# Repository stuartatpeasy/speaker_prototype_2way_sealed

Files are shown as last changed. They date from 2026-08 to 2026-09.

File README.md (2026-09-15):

# DIY Near-Wall Two-Way Loudspeaker

This is the compact project dashboard and documentation router for the sealed
passive two-way prototype. Read it first, then follow only the route relevant to
the task. Detailed procedures, evidence, and history are deliberately kept out
of this file.

## 1. Current Project State

**Lifecycle:** ACTIVE PROTOTYPE DEVELOPMENT

**Current phase:** measured Seed A is the accepted reversible external
prototype. Its acoustic summation, as-built load, bounded level/distortion, and
exposed-component surface-thermal gates pass. Driver procurement and final
crossover/placement decisions remain provisional. The owning
[driver](doc/DRIVER_ANALYSIS.md), [crossover](doc/CROSSOVER_DESIGN.md), and
[REW](doc/rew/README.md) records provide the conditions and evidence.

**Next action:** inventory/procure and build speaker two to the same design,
then compare the decisive installed, acoustic, load, level, and thermal results
under matched conditions. On speaker two, capture a valid immediate hot
`0-degree` response and check whether the narrow `2.18 kHz` high-level feature
repeats. Speaker one's wrong-angle hot trace remains excluded; retest it only if
speaker two reveals an anomaly.

**Last reviewed:** 2026-09-15

| Subsystem | Current consequence | Detailed authority |
| --- | --- | --- |
| Cabinet | One representative sealed prototype is complete; speaker two should match it. | [Cabinet design](doc/CABINET_DESIGN.md) |
| Drivers | The original cooled installed ZMAs remain model baselines; a cooled post-conditioning woofer check is lower priority. | [Driver analysis](doc/DRIVER_ANALYSIS.md) |
| Crossover | Seed A passes the bounded hardware and acoustic gates; keep it external through pair matching. | [Crossover design](doc/CROSSOVER_DESIGN.md) |
| Measurement | StarTech load and UMC22 raw-driver routes pass; desktop UMC202HD sweeps remain suspended. | [REW dispatcher](doc/rew/README.md) |
| Room | Near-wall placement candidates remain measurement trials. | [Room summary](doc/ROOM_DETAILS.md) |

## 2. Project Goal And Locked Architecture

Design and build a pair of accurate, measurement-led passive loudspeakers with
neutral tonal balance, smooth on-axis and off-axis behaviour, low distortion,
and an amplifier-friendly measured load. Installed measurements take precedence
over nominal impedance, textbook crossover values, or unsupported audiophile
claims.

The first version is locked to:

- passive two-way operation;
- SB Acoustics SB17NRX2C35-8 woofer/midwoofer;
- SB Acoustics SB26STWGC-4 waveguide tweeter;
- sealed, near-wall enclosure;
- an external development crossover through a four-pole speakON connection;
- crossover design from phase-bearing measurements of the installed drivers.

Three-way, open-baffle, transmission-line, horn, and reflex alternatives are
outside this version. DSP may be used experimentally before the passive
crossover is finalised.

## 3. Task-Oriented Reading Routes

Read `AGENTS.md` as the standing collaboration policy. Then use the smallest
route below. Files labelled history or qualification are not routine context.

| Task | Read | Add only when needed |
| --- | --- | --- |
| Driver or enclosure alignment | [Driver analysis](doc/DRIVER_ANALYSIS.md) | [Run-in procedure](doc/DRIVER_RUNIN.md) for conditioning; [cabinet design](doc/CABINET_DESIGN.md) for mechanical consequences |
| Cabinet fabrication | [Cabinet design](doc/CABINET_DESIGN.md) | [3D-model hub](doc/3d_models/README.md) for model selection; [regeneration and retention](doc/3d_models/REGENERATION_AND_RETENTION.md) only for rebuilding a model or printer job |
| Crossover modelling | [Driver analysis](doc/DRIVER_ANALYSIS.md), [crossover design](doc/CROSSOVER_DESIGN.md), [measurement workflow](doc/MEASUREMENT_WORKFLOW.md) | [Component development](doc/CROSSOVER_COMPONENT_DEVELOPMENT.md) only for component construction or thermal/mechanical questions |
| UMC22 woofer capture or repeatability investigation | [REW dispatcher](doc/rew/README.md), [UMC22 runbook](doc/rew/procedures/UMC22_INSTALLED_WOOFER_FRD.md) | [FRD method](doc/rew/FRD_MEASUREMENT_METHOD.md) when reviewing geometry, impulse/ETC, the production window, or capture comparisons; [driver analysis](doc/DRIVER_ANALYSIS.md) when assessing or promoting driver-design evidence; qualification only for audit or failure investigation |
| UMC22 protected tweeter capture | [REW dispatcher](doc/rew/README.md), [UMC22 tweeter runbook](doc/rew/procedures/UMC22_INSTALLED_TWEETER_FRD.md) | [FRD method](doc/rew/FRD_MEASUREMENT_METHOD.md) for common timing/window review; [driver analysis](doc/DRIVER_ANALYSIS.md) for the approved impedance and protection derivation |
| UMC22 horizontal off-axis driver series | [REW dispatcher](doc/rew/README.md), [horizontal off-axis runbook](doc/rew/procedures/UMC22_INSTALLED_HORIZONTAL_OFF_AXIS_FRD.md) | [FRD method](doc/rew/FRD_MEASUREMENT_METHOD.md) only when reviewing timing/window validity; completed on-axis runbooks only to audit a disputed electrical-route fact |
| Seed A as-built impedance/phase planning or operation | [StarTech Seed A impedance procedure](doc/rew/procedures/STARTECH_SEED_A_SYSTEM_IMPEDANCE.md), [crossover design](doc/CROSSOVER_DESIGN.md) | [Driver analysis](doc/DRIVER_ANALYSIS.md) for baseline comparison; Seed A commissioning history only to audit completed acoustic evidence |
| Review or deliberately repeat Seed A full-system level/thermal validation | [Seed A level/thermal qualification](doc/rew/qualification/SEED_A_FULL_SYSTEM_LEVEL_AND_THERMAL_QUALIFICATION_2026-09-10.md), [crossover design](doc/CROSSOVER_DESIGN.md) | [Completed procedure](doc/rew/procedures/UMC22_SEED_A_LEVEL_AND_THERMAL.md) only for a deliberate repeat; [fixture use](doc/rew/fixtures/REFERENCE_FIXTURE_USE.md) only after reconnection or a changed route |
| Reconnect or operate the reference fixture | [Fixture use](doc/rew/fixtures/REFERENCE_FIXTURE_USE.md) and the applicable interface procedure | [Fixture specification](doc/rew/fixtures/REFERENCE_FIXTURE_SPECIFICATION.md) if rebuilding or redesigning |
| Audit UMC22 or fixture qualification | [REW dispatcher](doc/rew/README.md), then the named record under `doc/rew/qualification/` | Chronological records under `doc/rew/history/` only for superseded attempts or provenance questions |
| Diagnose or resume UMC202HD | [Dropout diagnosis](doc/rew/UMC202HD_DESKTOP_DROPOUT_DIAGNOSIS.md) | [Suspended UMC202HD procedure](doc/rew/procedures/UMC202HD_FRD_SUSPENDED.md) when preparing to resume |
| Room placement | [Room summary](doc/ROOM_DETAILS.md), [placement and measurement](doc/room/ROOM_PLACEMENT_AND_MEASUREMENT.md) | [Geometry and screening](doc/room/ROOM_GEOMETRY_AND_SCREENING.md) for CAD, coupled-space, or modal questions |
| FRD, ZMA, impulse, or VituixCAD file inspection/comparison | [Measurement data tooling](doc/MEASUREMENT_DATA_TOOLING.md) | [Measurement workflow](doc/MEASUREMENT_WORKFLOW.md) only when interpreting evidence or changing measurement policy |
| REW API status or session snapshot | [REW API client](doc/REW_API_CLIENT.md) | Its qualification record only for maintenance or audit |
| Retained `.mdat` extraction or summary | [REW MDAT extraction](doc/rew/procedures/REW_MDAT_EXTRACTION.md) | [REW API client](doc/REW_API_CLIENT.md) for live reachability; API qualification only for maintenance or audit |
| 3D model selection | [3D-model hub](doc/3d_models/README.md), then one component README | [Regeneration and retention](doc/3d_models/REGENERATION_AND_RETENTION.md) only for rebuilding or re-slicing |
| Documentation review | [Documentation review procedure](doc/DOCUMENTATION_REVIEW.md) | [Local tooling](doc/LOCAL_TOOLING.md) for the offline link, route, and changed-file checks; use comprehensive mode only for consolidation or handover |
| Repository or generated-artifact maintenance | [AGENTS.md](AGENTS.md), [.gitignore](.gitignore), [local tooling](doc/LOCAL_TOOLING.md) | Relevant reconstruction authority only |

## 4. Documentation Map

| Area | Authority |
| --- | --- |
| Collaboration and retention policy | [AGENTS.md](AGENTS.md), [.gitignore](.gitignore) |
| Documentation review | [doc/DOCUMENTATION_REVIEW.md](doc/DOCUMENTATION_REVIEW.md) |
| Driver evidence and conditioning | [doc/DRIVER_ANALYSIS.md](doc/DRIVER_ANALYSIS.md), [doc/DRIVER_RUNIN.md](doc/DRIVER_RUNIN.md) |
| Cabinet and crossover | [doc/CABINET_DESIGN.md](doc/CABINET_DESIGN.md), [doc/CROSSOVER_DESIGN.md](doc/CROSSOVER_DESIGN.md), [doc/CROSSOVER_COMPONENT_DEVELOPMENT.md](doc/CROSSOVER_COMPONENT_DEVELOPMENT.md) |
| Measurement policy and tooling | [doc/MEASUREMENT_WORKFLOW.md](doc/MEASUREMENT_WORKFLOW.md), [doc/MEASUREMENT_DATA_TOOLING.md](doc/MEASUREMENT_DATA_TOOLING.md), [doc/REW_API_CLIENT.md](doc/REW_API_CLIENT.md) |
| REW procedures, qualification, and history | [doc/rew/README.md](doc/rew/README.md) |
| Dated driver and crossover decisions | [doc/history/README.md](doc/history/README.md) — history dispatcher; load only for provenance |
| Room geometry and placement | [doc/ROOM_DETAILS.md](doc/ROOM_DETAILS.md) |
| 3D-model documentation | [doc/3d_models/README.md](doc/3d_models/README.md) |
| Local environments and checkout paths | [doc/LOCAL_TOOLING.md](doc/LOCAL_TOOLING.md) |

All durable project Markdown except this file and `AGENTS.md` lives under
`doc/`. Subtree dispatchers index detailed component, qualification, and history
records without forcing them into normal orientation context.

## 5. Open Decisions

- final damping quantity and distribution;
- final cooled woofer impedance baseline and whether further conditioning helps;
- exact crossover frequency, topology, acoustic polarity, and component values;
- final inductor implementation, restraint, and crossover mounting position;
- amplifier headroom at the required listening level;
- final veneer and finish;
- final room placement among the documented reversible trials;
- whether DSP or a future subwoofer forms part of the finished system;
- production-driver spread and stereo-pair matching during the second-speaker
  build, including the deferred hot `0-degree` comparison.

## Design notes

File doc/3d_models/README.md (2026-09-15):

# 3D Model Collection

| State | Value |
| --- | --- |
| Lifecycle | **CURRENT COLLECTION HUB** |
| Owns | Model catalogue and selection routing |
| Does not own | Component-specific dimensions, provenance, inferred geometry, limitations, or regeneration detail |
| Source tree | [`src/3d_models/`](../../src/3d_models/) |
| Artefact tree | [`3d_models/`](../../3d_models/) |
| Regeneration, preview, printer, and retention | [Regeneration and retention](REGENERATION_AND_RETENTION.md) |
| Last reviewed | 2026-09-15 |

## 1. Collection catalogue

| Family | Preferred model and variants | Component record |
| --- | --- | --- |
| M4 × 10 Type D flanged insert | Low-poly DAE for repeated cabinet instances; detailed DAE for close views; legacy STL fallbacks retained | [Type D insert](M4x10_Type_D_Flanged_Threaded_Insert/README.md) |
| M4 × 10 Type E non-flanged insert | One DAE | [Type E insert](M4x10_Type_E_NonFlanged_Threaded_Insert/README.md) |
| M4 × 30 countersunk machine screw | One DAE | [M4 machine screw](M4x30_Countersunk_Machine_Screw_Black/README.md) |
| No. 4 × 3/4 in self-tapping screw | One DAE | [No. 4 screw](No4x3-4in_2.9x19mm_Pozi_Countersunk_Self_Tapping_Screw_Black_Passivated/README.md) |
| No. 8 × 1 in self-tapping screw | One DAE | [No. 8 screw](No8x1in_4.2x25mm_Pozi_Countersunk_Self_Tapping_Screw_Black/README.md) |
| Neutrik NL4MPXX | DAE converted from retained STEP | [NL4MPXX connector](Neutrik_NL4MPXX/README.md) |
| SB Acoustics SB17NRX2C35-8 | DAE; legacy STL fallback retained | [Woofer](SB_Acoustics_SB17NRX2C35-8/README.md) |
| SB Acoustics SB26STWGC-4 | One DAE | [Tweeter](SB_Acoustics_SB26STWGC-4/README.md) |
| Crossover-coil formers and brackets | Five retained SketchUp-exported fabrication STLs | [Crossover coils](Crossover_Coils/README.md) |

Canonical cabinet and room assemblies, fabrication STLs, and printer jobs also live under [`3d_models/`](../../3d_models/), but are not members of this scripted component catalogue.

## 2. Choose the next authority

For model selection, read only the relevant component record above. For scripted-model regeneration, SketchUp import, preview rendering, runtime/dependencies, G-code re-slicing, verification, or retention, read [Regeneration and retention](REGENERATION_AND_RETENTION.md) after the selected component record. Canonical assemblies and fabrication STL/printer jobs are not part of the scripted catalogue; use their named records and retained source files.

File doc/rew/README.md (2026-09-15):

# REW Documentation Dispatcher

Lifecycle: **CURRENT DISPATCHER**
Last reviewed: 2026-09-15

## 1. Purpose

This file routes a task to one REW authority. It owns navigation and lifecycle
labels only; it does not own measurement status, results, settings, or safety
release. Begin with the smallest route below and load evidence or history only
when the task actually requires it.

The lifecycle labels mean:

- **CURRENT PROCEDURE** — instructions that may govern the next physical or
  software action after their stated prerequisites are satisfied.
- **COMPLETED PROCEDURE / RETAINED EVIDENCE** — the route used for finished
  work; consult for audit or a deliberate repeat after material change, not as
  an automatic signal release.
- **METHOD** — interface-neutral measurement principles and data-handling
  requirements; not an equipment power-up authority.
- **QUALIFICATION EVIDENCE** — concise retained results supporting a release or
  engineering conclusion; normally read for audit, failure investigation, or
  hardware/configuration change.
- **ACTIVE DIAGNOSTIC** — the authority for an unresolved fault and its next
  useful discriminator.
- **HISTORY** — superseded and failed branches retained for provenance. Do not
  load routinely and never follow an old instruction without checking the
  current procedure.

## 2. Task Routes

| Task | Read first | Add only if needed |
| --- | --- | --- |
| UMC22 installed-woofer capture or repeatability investigation | [`procedures/UMC22_INSTALLED_WOOFER_FRD.md`](procedures/UMC22_INSTALLED_WOOFER_FRD.md) | [`FRD_MEASUREMENT_METHOD.md`](FRD_MEASUREMENT_METHOD.md) when choosing/reviewing the production window or comparing captures; [`../DRIVER_ANALYSIS.md`](../DRIVER_ANALYSIS.md) when assessing or promoting driver-design evidence |
| UMC22 protected installed-tweeter capture | [`procedures/UMC22_INSTALLED_TWEETER_FRD.md`](procedures/UMC22_INSTALLED_TWEETER_FRD.md) | [`FRD_MEASUREMENT_METHOD.md`](FRD_MEASUREMENT_METHOD.md) for common timing/window review; [`../DRIVER_ANALYSIS.md`](../DRIVER_ANALYSIS.md) for the measured load and protection derivation |
| UMC22 installed-driver horizontal off-axis series | [`procedures/UMC22_INSTALLED_HORIZONTAL_OFF_AXIS_FRD.md`](procedures/UMC22_INSTALLED_HORIZONTAL_OFF_AXIS_FRD.md) | The completed woofer/tweeter runbooks only if an existing electrical-route fact is disputed; qualification only for a failed gate or changed hardware |
| Audit the completed Seed A full-system level and thermal gate | [`qualification/SEED_A_FULL_SYSTEM_LEVEL_AND_THERMAL_QUALIFICATION_2026-09-10.md`](qualification/SEED_A_FULL_SYSTEM_LEVEL_AND_THERMAL_QUALIFICATION_2026-09-10.md) | [`../CROSSOVER_DESIGN.md`](../CROSSOVER_DESIGN.md) for the design consequence; the completed procedure only for a deliberate repeat |
| Deliberately repeat the Seed A level/thermal route or adapt it for speaker two | [`procedures/UMC22_SEED_A_LEVEL_AND_THERMAL.md`](procedures/UMC22_SEED_A_LEVEL_AND_THERMAL.md) | Fixture qualification only after a changed route or failed gate |
| Deliberately repeat Seed A impedance/phase or adapt the route for speaker two | [`procedures/STARTECH_SEED_A_SYSTEM_IMPEDANCE.md`](procedures/STARTECH_SEED_A_SYSTEM_IMPEDANCE.md) | [`../CROSSOVER_DESIGN.md`](../CROSSOVER_DESIGN.md) for the design gate; qualification only if hardware or an established gate is disputed |
| Audit the completed Seed A load or EPDR result | [`qualification/SEED_A_AS_BUILT_IMPEDANCE_AND_EPDR_2026-09-09.md`](qualification/SEED_A_AS_BUILT_IMPEDANCE_AND_EPDR_2026-09-09.md) | [`../CROSSOVER_DESIGN.md`](../CROSSOVER_DESIGN.md) for the current design consequence |
| Audit completed Seed A filtered/full-system acoustic evidence | [`history/SEED_A_EXTERNAL_CROSSOVER_COMMISSIONING_2026-09-08_TO_09.md`](history/SEED_A_EXTERNAL_CROSSOVER_COMMISSIONING_2026-09-08_TO_09.md) | [`../DRIVER_ANALYSIS.md`](../DRIVER_ANALYSIS.md) or [`../CROSSOVER_DESIGN.md`](../CROSSOVER_DESIGN.md) for the current engineering consequence |
| General installed-driver measurement design or FRD review | [`FRD_MEASUREMENT_METHOD.md`](FRD_MEASUREMENT_METHOD.md) | The applicable interface procedure |
| Plan a new measurement series or revise evidence handling | [`MEASUREMENT_PLANNING_AND_EVIDENCE.md`](MEASUREMENT_PLANNING_AND_EVIDENCE.md) | The exact current interface procedure and qualification only when a gate changes |
| Extract or compactly summarise a retained `.mdat` through REW | [`procedures/REW_MDAT_EXTRACTION.md`](procedures/REW_MDAT_EXTRACTION.md) | [`../REW_API_CLIENT.md`](../REW_API_CLIENT.md) for live status/snapshot; API validation only for maintenance or failure audit |
| Audit the UMC22 release | [`qualification/UMC22_FRD_QUALIFICATION.md`](qualification/UMC22_FRD_QUALIFICATION.md) | The dated UMC22 history only for failed or superseded branches |
| Audit approved installed-driver acoustic sources, window choice, or a capture exclusion | [`qualification/INSTALLED_DRIVER_ACOUSTIC_SOURCES_2026-09-06_TO_07.md`](qualification/INSTALLED_DRIVER_ACOUSTIC_SOURCES_2026-09-06_TO_07.md) | [`../DRIVER_ANALYSIS.md`](../DRIVER_ANALYSIS.md) for the current modelling consequence; dated history only for superseded interface attempts |
| Audit or reproduce REW API extraction validation | [`qualification/REW_API_CLIENT_VALIDATION.md`](qualification/REW_API_CLIENT_VALIDATION.md) | [`../REW_API_CLIENT.md`](../REW_API_CLIENT.md) for the current operating procedure |
| Operate or reconnect the reference fixture | [`fixtures/REFERENCE_FIXTURE_USE.md`](fixtures/REFERENCE_FIXTURE_USE.md) | Qualification only if a gate fails or hardware changed |
| Rebuild, modify, or redesign the fixture | [`fixtures/REFERENCE_FIXTURE_SPECIFICATION.md`](fixtures/REFERENCE_FIXTURE_SPECIFICATION.md) | [`qualification/REFERENCE_FIXTURE_QUALIFICATION_2026-09-01_TO_03.md`](qualification/REFERENCE_FIXTURE_QUALIFICATION_2026-09-01_TO_03.md) |
| Diagnose UMC202HD desktop dropouts | [`UMC202HD_DESKTOP_DROPOUT_DIAGNOSIS.md`](UMC202HD_DESKTOP_DROPOUT_DIAGNOSIS.md) | No other REW file unless a specific analogue result is disputed |
| Decide whether UMC202HD FRD may resume | [`procedures/UMC202HD_FRD_SUSPENDED.md`](procedures/UMC202HD_FRD_SUSPENDED.md) | Dropout authority, fixture-use file, then qualification evidence if the physical chain changed |

## 3. Evidence And History

- [`qualification/UMC22_FRD_QUALIFICATION.md`](qualification/UMC22_FRD_QUALIFICATION.md) — **QUALIFICATION EVIDENCE** for UMC22 Gates A-E and the final repeatability release.
- [`qualification/INSTALLED_DRIVER_ACOUSTIC_SOURCES_2026-09-06_TO_07.md`](qualification/INSTALLED_DRIVER_ACOUSTIC_SOURCES_2026-09-06_TO_07.md) — **QUALIFICATION EVIDENCE** for approved installed-driver on-axis and sparse-polar source selection, exclusions, timing, windows, and protection scale.
- [`qualification/REFERENCE_FIXTURE_QUALIFICATION_2026-09-01_TO_03.md`](qualification/REFERENCE_FIXTURE_QUALIFICATION_2026-09-01_TO_03.md) — **QUALIFICATION EVIDENCE** for amplifier topology, fixture construction, clamps, ground paths, cables, and AC commissioning.
- [`qualification/REW_API_CLIENT_VALIDATION.md`](qualification/REW_API_CLIENT_VALIDATION.md) — **QUALIFICATION EVIDENCE** for offline tests and live selected extraction; the Codex host-access boundary remains separately stated.
- [`qualification/STARTECH_IMPEDANCE_ROUTE_QUALIFICATION_2026-09-09.md`](qualification/STARTECH_IMPEDANCE_ROUTE_QUALIFICATION_2026-09-09.md) — **QUALIFICATION EVIDENCE** for the effective R/R/L route, refreshed open/short/reference calibration, known-resistor verification, and Seed A level release.
- [`qualification/SEED_A_AS_BUILT_IMPEDANCE_AND_EPDR_2026-09-09.md`](qualification/SEED_A_AS_BUILT_IMPEDANCE_AND_EPDR_2026-09-09.md) — **QUALIFICATION EVIDENCE** for the retained complete-system capture, measured minimum load, EPDR derivation, model comparison, and load-gate pass.
- [`qualification/SEED_A_FULL_SYSTEM_LEVEL_AND_THERMAL_QUALIFICATION_2026-09-10.md`](qualification/SEED_A_FULL_SYSTEM_LEVEL_AND_THERMAL_QUALIFICATION_2026-09-10.md) — **QUALIFICATION EVIDENCE** for the retained level series, sampled distortion, compression comparison, external-component temperatures, invalid post-thermal trace exclusion, and bounded decision.
- [`history/UMC22_FRD_QUALIFICATION_LOG_2026-09-05.md`](history/UMC22_FRD_QUALIFICATION_LOG_2026-09-05.md) — **HISTORY** containing the detailed UMC22 chronology.
- [`history/FRD_REPEATABILITY_DEVELOPMENT_2026-09-03_TO_05.md`](history/FRD_REPEATABILITY_DEVELOPMENT_2026-09-03_TO_05.md) — **HISTORY** containing the UMC202HD-to-UMC22 method-development narrative.
- [`history/SEED_A_EXTERNAL_CROSSOVER_COMMISSIONING_2026-09-08_TO_09.md`](history/SEED_A_EXTERNAL_CROSSOVER_COMMISSIONING_2026-09-08_TO_09.md) — **HISTORY / RETAINED MEASUREMENT EVIDENCE** for Seed A cold commissioning, the parked tweeter-only-load investigation, WF1/TF1/SUM1/REV1, and the first physical full-system horizontal set.

History files are deliberately excluded from normal orientation. Search or
open the relevant dated subsection only when reconstructing why a setting or
decision changed.

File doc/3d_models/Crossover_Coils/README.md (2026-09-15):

# Crossover Coil Fabrication Models

| State | Value |
| --- | --- |
| Lifecycle | **CURRENT RETAINED FABRICATION SOURCES** |
| Owns | Identity, file-level provenance, geometry checks, print reconstruction, and retention limits for the crossover-coil formers and brackets |
| Does not own | Electrical winding targets, inductance/DCR acceptance, PCB layout, installed restraint, or manufacturing release |
| Source tree | [`3d_models/Crossover coils/`](../../../3d_models/Crossover%20coils/) |
| Current use | Candidate formers and restraint brackets for the reversible external crossover and its matched second network |
| Limitations | Only binary STL exports are retained; no editable SketchUp source or parameterised generator is present, and STL dimensions do not prove fit or mechanical adequacy |
| Last reviewed | 2026-09-15 |

## 1. Retained models

Each binary header begins `SketchUp STL tmp`, which establishes the exporter
family but not the SketchUp version, units setting, authoring history, or design
intent. File-level inspection gives:

| STL | Bytes | Triangles | Axis-aligned size, mm | SHA-256 |
| --- | ---: | ---: | --- | --- |
| `Crossover coil bracket 70mm.stl` | `36,884` | `736` | `24 x 45 x 47` | `1a1c5f53c819f191d65dd57bc6a944bdf2bd17f0ede35a2619a52653eb27129a` |
| `Crossover coil bracket B.stl` | `81,284` | `1,624` | `54 x 50 x 51` | `bb128d6cfdb267210c2d28ef907b901df0f76c888de0b029383f7d10baa7defd` |
| `Crossover coil former 50mm.stl` | `87,884` | `1,756` | `50 x 50 x 33` | `1d27ed4c79d08ac5ad17f20713781e60b5f202eba2ae47380797f6348366c287` |
| `Crossover coil former 60mm.stl` | `115,484` | `2,308` | `60 x 60 x 33` | `46a93e1c0fd671c08022aa63b22a1416570dfbe013cbe9eb493ed98c347cc9a6` |
| `Crossover coil former 70mm.stl` | `104,084` | `2,080` | `70 x 70 x 33.5` | `411bb6568155a367072750986901e53c84828467ae5ccf0e84cfa93079025e8f` |

These are retained fabrication sources because no complete reconstruction path
exists. Do not replace or ignore them merely because a slicer can consume the
exports. Verify coil fit, lead exit, separation/orientation, restraint, PCB and
cabinet clearance, material, and print quality on the actual assembly.

## 2. Print reconstruction

[`3d_models/PRINT_SETTINGS.json`](../../../3d_models/PRINT_SETTINGS.json) owns
the Cura 5.13.0 / Creality CR-20 Pro settings and reference output statistics.
G-code is intentionally ignored. Re-slice the named current STL with the
manifest settings and compare bounds, time, and filament use proportionately;
functional rather than byte-identical equivalence is expected.

The 2026-09-13 file reorganisation changed two former geometries while removing
their old names. For historical print jobs, the manifest therefore records the
source path and Git revision that existed at capture. Recover that exact input
without altering the worktree with:

```text
git show <sourceRevisionAtCapture>:3d_models/<sourceStlAtCapture>
```

Redirect that output only into a temporary workspace. A similarly named current
STL is not assumed geometrically equivalent unless the manifest says the move
was exact.

## 3. Electrical authority

Former diameter and winding space are mechanical constraints, not inductance
specifications. Use [Crossover component
development](../../CROSSOVER_COMPONENT_DEVELOPMENT.md) for the measured Seed A
inductances, DCRs, winding practice, pair matching, and thermal limitations.

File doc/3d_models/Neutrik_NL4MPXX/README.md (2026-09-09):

# Neutrik NL4MPXX Connector

[Collection import, regeneration, and retention instructions](../README.md)

## 1. Model, source, and placement

The SketchUp model is [Neutrik_NL4MPXX.dae](../../../3d_models/Neutrik_NL4MPXX/Neutrik_NL4MPXX.dae). It is an OpenCascade tessellation of the retained [3d_models/nl4mpxx.stp](../../../3d_models/nl4mpxx.stp).

- Units: millimetres; Z-up.
- Origin/orientation: the STEP coordinate system is preserved without scaling, rotation, centring, or relocation.
- Dimensions: 25.9 × 30.9 × 34.3 mm.
- Bounds: X `-12.95` to `12.95` mm; Y `-15.45` to `15.45` mm; Z `-27.25` to `7.05` mm.

## 2. Provenance and conversion limits

The STEP identifies `NL4MPXX-4`, Creo Parametric, and millimetres. OpenCascade reads one valid solid with 1,108 analytic B-rep faces. Because the source contains no STEP colour/presentation records, the DAE adds one dark graphite housing material rather than inferred part colours.

Source STEP SHA-256:

```text
AA7DDF218941F2284EE6E9C9E7E2591CA32B3B0ED0E6CA1A27EAEDB660CD6748
```

The converter uses `0.35 mm` linear and `0.65 rad` angular deflection. The result contains 18,262 triangles, 17,428 face-local vertices, and no degenerate triangles. Periodic CAD seams remain coincident mesh seams; the source B-rep passes OpenCascade validity.

## 3. Generator and dependency

[generate_neutrik_nl4mpxx.py](../../../src/3d_models/Neutrik_NL4MPXX/generate_neutrik_nl4mpxx.py) reads the retained STEP path above. Conversion additionally requires:

```console
python -m pip install cadquery-ocp-novtk
```

The exact package version used for the present DAE was not recorded. Treat the
documented STEP hash, tessellation settings, bounds, solid/face count, triangle
count, and validity checks as the current semantic reconstruction test, and pin
the package version before changing or re-qualifying the converter. The shared
preview renderer reads the generated DAE directly, so OpenCascade is needed
only for STEP conversion.

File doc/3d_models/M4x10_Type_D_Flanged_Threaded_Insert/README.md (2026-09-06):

# M4 × 10 mm Type D Flanged Threaded Insert

[Collection import, regeneration, and retention instructions](../README.md)

## 1. Preferred variant and placement

Use the [low-poly DAE](../../../3d_models/M4x10_Type_D_Flanged_Threaded_Insert_LowPoly/M4x10_Type_D_Flanged_Threaded_Insert_LowPoly.dae) for repeated cabinet instances. It retains the published envelope, flange, hex drive, through bore, and visible external helix in approximately 1,900 triangles. Use the [detailed DAE](../../../3d_models/M4x10_Type_D_Flanged_Threaded_Insert/M4x10_Type_D_Flanged_Threaded_Insert.dae) only for close views requiring the modelled internal M4 thread.

- Units: millimetres.
- Origin: centre of the upper flange face.
- Orientation: flange face in the XY plane; insert extends 10 mm along negative Z.

## 2. Controlling dimensions

| Feature | Dimension |
| --- | ---: |
| Overall length | 10.0 mm |
| Flange / maximum diameter | 8.5 mm |
| Body root diameter | 5.5 mm |
| Internal machine thread | M4 × 0.7 |
| Hex drive | 4.0 mm across flats |
| Suggested pilot hole, reference only | 5.6–6.0 mm |

## 3. Provenance and limitations

Envelope dimensions come from [The Insert Company Type D table](https://www.theinsertcompany.com/type_d_threaded_insert_for_wood.php). Flange thickness, hex depth, and die-cast external tooth form are not fully specified and are representative. Confirm the actual insert and pilot-hole behaviour in the cabinet material before fabrication.

Both variants are closed manifold meshes. The low-poly model substitutes a smooth 3.24 mm M4 minor-diameter bore for the hidden internal helix. Its 24-sided flange preserves the exact 8.5 mm X/Y envelope with approximately 0.036 mm maximum chord error. Retained [detailed STL](../../../3d_models/M4x10_Type_D_Flanged_Threaded_Insert/M4x10_Type_D_Flanged_Threaded_Insert.stl) and [low-poly STL](../../../3d_models/M4x10_Type_D_Flanged_Threaded_Insert_LowPoly/M4x10_Type_D_Flanged_Threaded_Insert_LowPoly.stl) files are legacy fallbacks.

## 4. Generators

- [Detailed generator](../../../src/3d_models/M4x10_Type_D_Flanged_Threaded_Insert/generate_m4_type_d_insert.py)
- [Low-poly generator](../../../src/3d_models/M4x10_Type_D_Flanged_Threaded_Insert_LowPoly/generate_m4_type_d_insert_low_poly.py)

Use the low-poly folder name with the shared preview renderer when verifying the preferred assembly variant.

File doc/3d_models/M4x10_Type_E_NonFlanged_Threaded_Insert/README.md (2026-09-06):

# M4 × 10 mm Type E Non-Flanged Threaded Insert

[Collection import, regeneration, and retention instructions](../README.md)

## 1. Model and placement

The SketchUp model is [M4x10_Type_E_NonFlanged_Threaded_Insert.dae](../../../3d_models/M4x10_Type_E_NonFlanged_Threaded_Insert/M4x10_Type_E_NonFlanged_Threaded_Insert.dae).

- Units: millimetres; Z-up.
- Origin: centre of the upper drive face.
- Orientation: insert extends exactly 10 mm along negative Z.
- The unheaded body can be installed below the wood surface.

## 2. Controlling dimensions

| Feature | Dimension |
| --- | ---: |
| Internal thread | M4 × 0.7 |
| Overall length | 10.0 mm |
| Maximum external-thread diameter | 8.5 mm |
| External-thread root diameter | 5.5 mm |
| Hex drive | 4.0 mm across flats |
| Suggested pilot hole | 5.6–6.0 mm |

## 3. Provenance and limitations

Dimensions and the non-flanged form come from [The Insert Company Type E record](https://www.theinsertcompany.com/type_e_threaded_insert_for_wood.php). External-thread pitch and crest form, bottom runout, hex depth, drive-to-bore transition, and four-lobed upper contour details are inferred from supplier imagery. The hidden M4 female helix is represented by a smooth 3.24 mm minor-diameter bore.

The model is a closed, outward-wound manifold containing 936 vertices and 1,872 triangles. Its 24-sided maximum-diameter approximation preserves the exact 8.5 mm X/Y envelope with approximately 0.036 mm maximum chord error.

## 4. Generator

[generate_m4_type_e_insert.py](../../../src/3d_models/M4x10_Type_E_NonFlanged_Threaded_Insert/generate_m4_type_e_insert.py)

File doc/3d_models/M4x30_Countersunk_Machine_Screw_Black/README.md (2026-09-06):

# M4 × 30 mm Black Countersunk Machine Screw

[Collection import, regeneration, and retention instructions](../README.md)

## 1. Model and placement

The SketchUp model is [M4x30_Countersunk_Machine_Screw_Black.dae](../../../3d_models/M4x30_Countersunk_Machine_Screw_Black/M4x30_Countersunk_Machine_Screw_Black.dae).

- Units: millimetres; Z-up.
- Origin: centre of the flat upper head face.
- Orientation: screw extends exactly 30.0 mm along negative Z.
- Countersunk-screw length includes the head.

## 2. Controlling dimensions

| Feature | Dimension |
| --- | ---: |
| Thread | M4 × 0.7, right hand |
| Overall length | 30.0 mm |
| Head diameter | 7.5 mm |
| Head height | 2.2 mm |
| Countersink angle | 90 degrees |
| Drive | PZ2 |
| Modelled thread-root diameter | 3.14 mm |

## 3. Provenance and limitations

The product size and black finish come from [Accu](https://www.accu.co.uk/pozi-countersunk-screws/988564-SPK-M4-30-CS-BL); [Westfield Fasteners](https://www.westfieldfasteners.co.uk/Bolts-Screws-Metric/Machine-Screw-Phillips-Countersunk-M4x75-A2-Stainless.html) corroborates the DIN 965 M4 head dimensions.

The 24-sided head preserves the exact 7.5 mm X/Y envelope. The right-hand external thread is a continuous helix with a flat, lightly chamfered end; the Pozidriv recess is a cavity. Recess-wing detail and the 3.14 mm root diameter are representative where drawings are incomplete. The closed manifold has 1,562 vertices and 3,120 triangles.

## 4. Generator

[generate_m4x30_countersunk_machine_screw.py](../../../src/3d_models/M4x30_Countersunk_Machine_Screw_Black/generate_m4x30_countersunk_machine_screw.py)

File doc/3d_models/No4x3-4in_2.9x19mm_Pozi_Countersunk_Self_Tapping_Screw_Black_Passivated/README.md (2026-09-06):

# No. 4 × 3/4 in (2.9 × 19 mm) Black-Passivated Self-Tapping Screw

[Collection import, regeneration, and retention instructions](../README.md)

## 1. Model and placement

The SketchUp model is [No4x3-4in_2.9x19mm_Pozi_Countersunk_Self_Tapping_Screw_Black_Passivated.dae](../../../3d_models/No4x3-4in_2.9x19mm_Pozi_Countersunk_Self_Tapping_Screw_Black_Passivated/No4x3-4in_2.9x19mm_Pozi_Countersunk_Self_Tapping_Screw_Black_Passivated.dae).

- Units: millimetres; Z-up.
- Origin: centre of the flat upper head face.
- Orientation: screw extends exactly 19.0 mm along negative Z, including the head.
- The metric 19 mm nominal length controls the model.

## 2. Controlling dimensions

| Feature | Dimension |
| --- | ---: |
| Thread | ST2.9 × 1.1, right hand |
| Overall length | 19.0 mm |
| Head diameter | 5.5 mm |
| Head height | 1.7 mm |
| Countersink angle | 80 degrees |
| Drive | PZ1 |
| Type Z recess width | 2.8 mm |
| Modelled recess depth | 1.60 mm |
| Type C point length | 2.6 mm |
| Modelled thread-root diameter | 2.08 mm |

## 3. Provenance and limitations

[Bolt World](https://boltworld.co.uk/products/no-4-x-3-4-2-9-x-19mm-pozi-countersunk-self-tapping-screws-black-passivated-zinc-plated-din-7982/) establishes the matching finish, PZ1 drive, head dimensions, and Type C/AB point. [Accu](https://www.accu.co.uk/self-tapping-pozi-countersunk-screws/163548-SPKT-No-4-3-4-A2-BL) corroborates the 2.9 × 19 mm, 80-degree, DIN 7982 C Z form; [Westfield Fasteners](https://www.westfieldfasteners.co.uk/Standards/TappingScrew-PoziCsk.html) supplies pitch, recess, and point standards data.

The 24-sided head preserves the 5.5 mm X/Y envelope. The external thread is a continuous helix blending into a Type C/AB-style point, and the PZ1 recess is a cavity. Recess-wing form and the modelled thread root remain representative. The closed manifold contains 890 vertices and 1,776 triangles.

## 4. Generator

[generate_no4x3_4in_pozi_countersunk_self_tapping_screw.py](../../../src/3d_models/No4x3-4in_2.9x19mm_Pozi_Countersunk_Self_Tapping_Screw_Black_Passivated/generate_no4x3_4in_pozi_countersunk_self_tapping_screw.py)

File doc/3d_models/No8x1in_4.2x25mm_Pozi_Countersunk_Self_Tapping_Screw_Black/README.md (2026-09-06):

# No. 8 × 1 in (4.2 × 25 mm) Black Self-Tapping Screw

[Collection import, regeneration, and retention instructions](../README.md)

## 1. Model and placement

The SketchUp model is [No8x1in_4.2x25mm_Pozi_Countersunk_Self_Tapping_Screw_Black.dae](../../../3d_models/No8x1in_4.2x25mm_Pozi_Countersunk_Self_Tapping_Screw_Black/No8x1in_4.2x25mm_Pozi_Countersunk_Self_Tapping_Screw_Black.dae).

- Units: millimetres; Z-up.
- Origin: centre of the flat upper head face.
- Orientation: screw extends exactly 25.0 mm along negative Z, including the head.
- The metric 25 mm nominal length controls the model.

## 2. Controlling dimensions

| Feature | Dimension |
| --- | ---: |
| Thread | ST4.2 × 1.4, right hand |
| Overall length | 25.0 mm |
| Head diameter | 8.1 mm |
| Head height | 2.5 mm |
| Countersink angle | 80 degrees |
| Drive | PZ2 |
| Point length | 3.7 mm |
| Modelled thread-root diameter | 3.10 mm |

## 3. Provenance and limitations

[Bolt World](https://boltworld.co.uk/products/no-8-x-1-4-2-x-25mm-pozi-countersunk-self-tapping-screws-black-passivated-zinc-plated-din-7982/) establishes the matching size, PZ2 drive, head dimensions, and DIN 7982 designation. [Accu](https://www.accu.co.uk/self-tapping-pozi-countersunk-screws/163584-SPKT-No-8-1-A2-BL) corroborates the product; [Westfield Fasteners](https://www.westfieldfasteners.co.uk/Standards/TappingScrew-PoziCsk.html) supplies pitch and Type C point data.

The 24-sided head preserves the exact 8.1 mm X/Y envelope. The external thread is a continuous helix blending into a Type C/AB-style point, and the Pozidriv recess is a cavity. Recess-wing form and the 3.10 mm thread root are representative where drawings are incomplete. The closed manifold contains 890 vertices and 1,776 triangles.

## 4. Generator

[generate_no8x1in_pozi_countersunk_self_tapping_screw.py](../../../src/3d_models/No8x1in_4.2x25mm_Pozi_Countersunk_Self_Tapping_Screw_Black/generate_no8x1in_pozi_countersunk_self_tapping_screw.py)

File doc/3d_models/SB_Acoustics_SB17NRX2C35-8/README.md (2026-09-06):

# SB Acoustics SB17NRX2C35-8 SketchUp Model

[Collection import, regeneration, and retention instructions](../README.md)

## 1. Model and placement

The primary model is [SB_Acoustics_SB17NRX2C35-8.dae](../../../3d_models/SB_Acoustics_SB17NRX2C35-8/SB_Acoustics_SB17NRX2C35-8.dae). The [STL](../../../3d_models/SB_Acoustics_SB17NRX2C35-8/SB_Acoustics_SB17NRX2C35-8.stl) is an uncoloured legacy fallback, not a watertight printing solid.

- Units: millimetres.
- Origin: acoustic axis on the rear mounting face of the flange.
- Orientation: cone/front along positive Z; motor along negative Z.
- Rear limit with the mounting plane at Z = 0: exactly `-75 mm`.

## 2. Manufacturer-published dimensions

| Feature | Dimension |
| --- | ---: |
| Frame outside diameter | 171.0 mm |
| Mounting-hole pitch circle | 159.0 mm |
| Mounting recesses / through holes | 4 × 8.5 mm / 4 × 4.3 mm |
| Rear basket envelope | 144.9 mm diameter |
| Magnet outside diameter | 100.0 mm |
| Front flange thickness | 6.5 mm |
| Mounting / overall depth | 75.0 mm / 85.9 mm |
| Front projection | 10.9 mm |
| Voice-coil diameter / winding height | 35.5 mm / 16.0 mm |

Sources: [manufacturer product page](https://sbacoustics.com/product/6in-sb17nrx2c35-8-norex/) and [datasheet](https://sbacoustics.com/wp-content/uploads/2020/02/6in-SB17NRX2C35-8.pdf).

## 3. Inferred geometry and limitations

Basket/spokes, cone and surround profiles, spider, motor plates, pole vent, terminals, tinsel leads, and labels are visually representative estimates from manufacturer and public product imagery. They do not override published dimensions.

Stepped mounting holes and pitch circle are accurate coloured reference surfaces but are not boolean-cut through the flange. The visual/layout assembly contains overlapping closed parts. Its 64-sided 171 mm circumference has approximately 0.103 mm maximum chord error; less visible parts use lower radial resolution. The generated model contains 8,068 triangles.

## 4. Generator

[generate_sb17nrx2c35_8.py](../../../src/3d_models/SB_Acoustics_SB17NRX2C35-8/generate_sb17nrx2c35_8.py) produces the correctly named `.dae` above; it does not recreate the legacy STL.

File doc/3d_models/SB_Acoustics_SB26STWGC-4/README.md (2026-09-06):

# SB Acoustics SB26STWGC-4 SketchUp Model

[Collection import, regeneration, and retention instructions](../README.md)

## 1. Model and placement

The model is [SB_Acoustics_SB26STWGC-4.dae](../../../3d_models/SB_Acoustics_SB26STWGC-4/SB_Acoustics_SB26STWGC-4.dae).

- Units: millimetres.
- Origin: acoustic axis on the rear mounting face of the waveguide.
- Orientation: waveguide/front along positive Z; motor and chamber along negative Z.
- Rear limit with the mounting plane at Z = 0: exactly `-42.1 mm`.

## 2. Manufacturer-published dimensions

| Feature | Dimension |
| --- | ---: |
| Waveguide outside diameter | 103.8 mm |
| Mounting-hole pitch circle | 92.0 mm |
| Mounting recesses / through holes | 4 × 8.0 mm / 4 × 4.2 mm |
| Rear/terminal envelope | 82.8 mm diameter |
| Motor diameter | 70.0 mm |
| Faceplate thickness | 6.0 mm |
| Mounting / overall depth | 42.1 mm / 48.1 mm |
| Voice-coil diameter / winding height | 25.4 mm / 1.3 mm |

Sources: [manufacturer product page](https://sbacoustics.com/product/sb26stwgc-4-fabric/), [datasheet](https://sbacoustics.com/wp-content/uploads/2020/05/SB26STWGC-4.pdf), and [public multi-angle imagery](https://www.soundimports.eu/en/sb-acoustics-sb26stwgc-4.html).

## 3. Inferred geometry and limitations

Waveguide and dome/surround profiles, adapter boss, motor plates, rear chamber, pole vent, terminals, and labels are visually representative estimates. A user-supplied production-unit sketch established a flat rear annulus blending into an approximately 64 mm central boss with a 3.0 mm concave root fillet; the 70 mm motor overhangs the boss and opposed terminals define the 82.8 mm envelope. These inferences do not override published dimensions.

Mounting recesses and holes are accurate coloured reference surfaces but are not boolean-cut. The visual/layout assembly is not a watertight printing solid. The 64-sided waveguide circumference has approximately 0.062 mm maximum chord error; the four-subdivision root fillet has approximately 0.058 mm maximum profile chord error. The DAE contains 5,714 triangles and the generator reports no degenerate triangles.

## 4. Generator

[generate_sb26stwgc_4.py](../../../src/3d_models/SB_Acoustics_SB26STWGC-4/generate_sb26stwgc_4.py)

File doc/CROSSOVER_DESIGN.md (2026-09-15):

# Crossover Design

> - **Lifecycle:** ACTIVE DESIGN AUTHORITY
> - **Owns:** current acoustic direction, driver polarity/topology, NL4 allocation, evidence dependencies, validation gates, and open design decisions
> - **Does not own:** detailed component construction, installed-driver evidence, measurement procedures, or superseded design development
> - **Read when:** modelling, assessing the present crossover, or planning an authorised controlled refinement
> - **Current decision:** retain same-polarity third-order Seed A as the reversible external prototype; measured acoustic, load, bounded level/distortion, and external-component surface-thermal gates pass
> - **Next gate:** build and test speaker two under matched conditions, including a correct immediate hot `0-degree` comparison and a check that the narrow approximately `1.28 dB` high-level shape change near `2.18 kHz` repeats
> - **Limitations:** one speaker only; approximate rather than steady sweep-voltage readings; generic rather than absolute-SPL microphone calibration; the attempted post-thermal trace is excluded because it was captured at `60 degrees`; positive-side sparse-horizontal evidence only; the parked undamped tweeter-only mechanism and possible ultrasonic behaviour remain unproved
> - **As of:** 2026-09-15

This is the current passive-crossover authority. Read the [design-development
history](history/CROSSOVER_DESIGN_DEVELOPMENT_2026-09-07_TO_08.md) only to
audit the exploratory Seed A/Seed B work or the VituixCAD correction history.
Current driver sources are in [DRIVER_ANALYSIS.md](DRIVER_ANALYSIS.md), and
component construction is in
[CROSSOVER_COMPONENT_DEVELOPMENT.md](CROSSOVER_COMPONENT_DEVELOPMENT.md).

## 1. Prototype interface and external crossover

The prototype brings the woofer and tweeter out separately through a **Neutrik
speakON NL4**:

- 1+ / 1-: woofer positive / negative;
- 2+ / 2-: tweeter positive / negative.

Keep the crossover external on a board with secure terminals, accessible
inductor taps, and enough room for safe substitutions. Do not switch taps with
the amplifier energised. Leave unused winding sections open-circuit, insulated,
and restrained so they cannot become a shorted turn.

## 2. Current crossover direction

Design from installed phase-bearing driver responses and impedances, not nominal
impedances or textbook equations. The initial approximately `2.2-2.4 kHz`,
LR4-like direction has been superseded by the measured Seed A prototype, which
crosses broadly near `1.83 kHz` and passes its physical summation gates.

Seed A uses normal (same) acoustic polarity and the measured third-order
electrical network in Section 2.2. Its shallow woofer upper transition and
moderate crossover-region beamwidth flare remain possible refinement targets.
The bounded alternative search found extra woofer suppression traded away
response span, phase/null margin, or load, while fourth-order and targeted-notch
variants were negligible or locally overfit. Do not promote Seed B unless
matched speaker-two evidence repeats a broad, design-relevant weakness.

Retain these design rules for later controlled work:

- electrical and acoustic order can differ because natural driver responses
  contribute to the final slopes;
- use partial rather than full baffle-step compensation;
- keep tweeter attenuation and check the complete measured load; and
- add impedance equalisation, breakup suppression, or sixth-order slopes only
  for a measured whole-system benefit.

### 2.1 Verified measured baseline

[`vituixcad/Prototype loudspeaker measured baseline verified 2026-09-07.vxp`](../vituixcad/Prototype%20loudspeaker%20measured%20baseline%20verified%202026-09-07.vxp)
is `10,825` bytes with SHA-256
`a456b8c2773cf0412394c75811aa6fdb41c2047a15f5f193f130904a7fb85645`.
It contains correct TW1/C2 FRDs at `0 degrees`, current installed ZMAs, TW1
scale `0.00 dB`, C2 scale `+11.14 dB`, zero response delays, native
unsmoothed phase, normal polarity, and direct unfiltered branches. It is the
raw software baseline, not a listening network.

### 2.2 Practical measured-component model

**DERIVED PRACTICAL MODEL / SIGNAL-FREE GATES PASSED:**
[`vituixcad/Prototype loudspeaker crossover Seed A practical measured 2026-09-08.vxp`](../vituixcad/Prototype%20loudspeaker%20crossover%20Seed%20A%20practical%20measured%202026-09-08.vxp)
retains the verified sparse-polar source assignments, topology, normal polarity,
and C2 scale multiplier `3.605786`, while using the completed measurements:

| Part | Practical value |
|---|---:|
| L(W1) | `0.724 mH`, `0.292 ohm` DCR, `1.8 mm` wire |
| C(W1) | `17.96 uF`, `0.04 ohm` ESR |
| L(W2) | `0.111 mH`, `0.172 ohm` DCR, `1.8 mm` wire |
| C(T1) | `12.22 uF`, `0.04 ohm` ESR |
| L(T1) | `0.219 mH`, `0.193 ohm` DCR, `1.8 mm` wire |
| C(T2) | `22.59 uF`, `0.04 ohm` ESR |
| R(Tser) | `1.401 ohm`; aggregate bank power field `20 W` |
| R(Tpar) | `39.032 ohm`; aggregate bank power field `15 W` |

The current practical file is `26,354` bytes with SHA-256
`16676944a98b625bb59effa4757f4224e0da763b36293679ace8dc0c67861a04`.
It parses with two drivers, eight measured components, four horizontal responses
per driver, installed ZMA paths, and unchanged tweeter scale; no source is
missing. Complex replay gives `2.116 kHz` branch equality, `13.2 degrees`
relative phase, `18.6 dB` normal-to-reverse difference, and `3.805 ohm`
minimum input impedance near `2.792 kHz` at `-9.4 degrees`. These pass the
bounded `2.05-2.25 kHz`, `20 degree`, `15 dB`, and `3.5 ohm` gates.

### 2.3 Measured acoustic consequence

**MEASURED ACOUSTIC VALIDATION - PROPORTIONATE PASS:** the retained authority is
[`rew/SB17NRX2C35-8_UMC22_full_dual_repeatability.mdat`](../rew/SB17NRX2C35-8_UMC22_full_dual_repeatability.mdat).
Capture detail and diagnostics are in the [Seed A commissioning
history](rew/history/SEED_A_EXTERNAL_CROSSOVER_COMMISSIONING_2026-09-08_TO_09.md).

- WF1 and TF1 place broad measured branch equality near `1.83 kHz`, about
  `13-14%` below the practical model, with essentially coincident phase.
- SUM1 correlates `0.99566` with voltage-corrected WF1+TF1; REV1 correlates
  `0.99463` with WF1-TF1. The physical polarity gate passes: the
  normal-to-reverse difference peaks at `25.31 dB` near `1.636 kHz` and is
  `15.82 dB` near `1.83 kHz`.
- The approximately `5.3 dB` axial dip near `11 kHz` predates Seed A and
  partly fills/moves off axis; it does not justify EQ.
- The `0/+20/+40/+60 degree` full-system set has no broad crossover hole. A
  moderate roughly `2.5-3.1 dB` beamwidth change through `1.5-2.5 kHz`
  remains a possible controlled-refinement target.

The intermittent distorted `1 kHz` tone occurred only with the undamped
tweeter-only load. It is closed/parked after clean resistor-dummy, damped
real-tweeter, and complete-system tests; an amplifier/load interaction remains
an inference, not a diagnosis.

### 2.4 As-built complete-system load

**VERIFIED MEASUREMENT / DERIVED - LOAD GATE PASSED:**
[`rew/SPK_impedance_WT_1_20260909.mdat`](../rew/SPK_impedance_WT_1_20260909.mdat)
and
[`rew/SPK_impedance_both_drivers_run1_2026-09-09.zma`](../rew/SPK_impedance_both_drivers_run1_2026-09-09.zma)
are owned by the [load record](rew/qualification/SEED_A_AS_BUILT_IMPEDANCE_AND_EPDR_2026-09-09.md).

Across `20 Hz-20 kHz`, minimum magnitude is `4.366 ohm` near `9.617 kHz`,
minimum real part is `4.284 ohm` near `2.156 kHz`, and minimum idealised
class-B EPDR is `2.563 ohm` near `1.942 kHz`, where actual impedance is
`4.905 ohm` at `-25.113 degrees`. The measured load clears the `3.5 ohm`
prototype gate by `0.866 ohm`; retain Seed A unchanged.

### 2.5 Full-system level, distortion, compression, and thermal result

**VERIFIED MEASUREMENT / USER-REPORTED CONDITIONS / DERIVED - BOUNDED PASS
WITH HOT-ACOUSTIC CHECK DEFERRED:** the [level/thermal qualification](rew/qualification/SEED_A_FULL_SYSTEM_LEVEL_AND_THERMAL_QUALIFICATION_2026-09-10.md)
and
[`rew/SPK_Seed_A_full_system_level_thermal_20260910.mdat`](../rew/SPK_Seed_A_full_system_level_thermal_20260910.mdat)
cover `0.5/1/2/4 V RMS` and a 15-minute nominal `2 V RMS` CTA-2034 exposure.

Both UMC22 inputs retained at least `27.9 dB` headroom; no warning, clipping,
dropout, audible distortion, protection event, or anomaly was reported. Sampled
THD and compression pass. A narrow `4 V` versus `2 V` difference reaches
`-1.28 dB` near `2.18 kHz`; it is a speaker-two confirmation item. R(Tser)
rose from `20.4` to `20.8 degrees C` and L(W1) from `20.4` to
`20.6 degrees C`, with neither rising in the final five minutes. The attempted
post-thermal sweep is excluded because it was at `60 degrees`, not `0 degrees`.

## 3. Evidence and model dependencies

Use only approved installed ZMA and phase-bearing FRD sources in
[DRIVER_ANALYSIS.md](DRIVER_ANALYSIS.md). The useful present crossover-region
loads near `2.30 kHz` are approximately `7.98 ohm` at `+10.8 degrees` for
the woofer and `3.48 ohm` at `-5.0 degrees` for the tweeter.

The approved C6 woofer source is
[`rew/frd/SB17NRX2C35-8/000deg_1m_UMC22_2026-09-06.frd`](../rew/frd/SB17NRX2C35-8/000deg_1m_UMC22_2026-09-06.frd).
The common-position TW1 source is
[`rew/frd/SB17NRX2C35-8/000deg_tweeter-axis_1m_UMC22_2026-09-06.frd`](../rew/frd/SB17NRX2C35-8/000deg_tweeter-axis_1m_UMC22_2026-09-06.frd).
With the `10.13 uF`, `0.08 ohm` protection capacitor and installed tweeter
ZMA, C2 requires `+11.14 dB`; leave TW1 at `0.00 dB`, delays at `0 us`,
minimum-phase conversion off, and polarity normal. History explains the
multiplier/decibel serialisation correction.

## 4. Excursion and power philosophy

Do not design for routine operation at rated Xmax. Normal use should be well
below Xmax; Xmech/Xlim are emergency limits. Read tweeter power ratings with
their specified high-pass condition and never apply an unfiltered broadband or
low-frequency signal to the bare tweeter.

## 5. Validation state before freezing the crossover

1. **Passed:** approved installed ZMA and phase-bearing FRD sources.
2. **Passed:** measured external network and practical model.
3. **Passed:** filtered drivers, normal sum, physical reverse-polarity null,
   sparse positive-horizontal set, and as-built load/EPDR.
4. **Bounded pass / deferred comparison:** level, sampled distortion, and
   external-component thermal gates. The wrong-angle post-thermal trace is
   excluded; obtain the valid hot `0-degree` comparison and check `2.18 kHz`
   on speaker two.
5. Keep the network external through matched speaker-two and pair checks. Move
   it inside only if those results support final implementation.

## 6. Open crossover items

- whether matched speaker-two evidence supports retaining Seed A unchanged;
- second-channel component matching and final inductor implementation;
- permanent inductor interlock, outer-layer binding, and PCB restraint;
- amplifier headroom at the required listening level; and
- final crossover mounting position and whether DSP remains development-only.

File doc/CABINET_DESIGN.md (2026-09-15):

# Cabinet and Mechanical Design

| State | Value |
| --- | --- |
| Lifecycle | **ACTIVE MECHANICAL AUTHORITY** |
| Owns | Accepted enclosure geometry, construction, hardware, sealing, bracing, damping intent, and repeat-build mechanical checks |
| Does not own | Driver evidence, acoustic alignment, crossover topology, room placement, or component-PCB design |
| Current decision | Retain the completed approximately `280 x 430 x 300 mm`, `21.7 L` geometric-net sealed prototype as speaker one's representative enclosure |
| Next gate | Build speaker two to the same verified physical geometry, recording any fitted or manufacturing-dependent dimensions that differ |
| Limitations | The prototype itself remains authoritative for empirically fitted details not yet back-annotated into CAD; damping quantity, final finish, crossover mounting, and repeat-build cutting/joinery detail remain open |
| Last reviewed | 2026-09-15 |

This file is the detailed mechanical source for the prototype enclosure. The high-level project state and documentation index are in [README.md](../README.md); driver and alignment evidence is in [DRIVER_ANALYSIS.md](DRIVER_ANALYSIS.md).

## 1. Prototype mechanical baseline

The enclosure geometry in **`3d_models/Prototype loudspeaker cabinet.dae`** records the design basis of the completed acoustically representative prototype. Further enclosure resizing or structural redesign is not planned before measurement of this build.

The prototype itself remains the dimensional authority for details that depend on actual purchased parts or manufacturing. Countersinks will be fitted to the actual screws, tweeter body and terminal clearance will be adjusted empirically, and the rear-panel centre landing will be fitted to the measured working compression of the actual gasket. Confirmed adjustments should be back-annotated into the CAD model.

This baseline freezes the initial enclosure design, not the damping distribution, finish, crossover, or later production refinements.

## 2. Enclosure alignment and volume

The enclosure is **sealed**, giving a predictable prototype with gradual bass roll-off, no port artefacts or below-tuning unloading, and straightforward integration with near-wall placement, a future subwoofer, or DSP high-pass.

The accepted body is approximately **280 × 430 × 300 mm**, giving about **23.65 L gross** and **21.7 L geometric net volume** before damping. The **20–24 L** range remains an acoustic reference, not permission to resize the accepted prototype. The target is well damped rather than maximally extended.

Published woofer parameters predicted approximately **Qtc 0.63 / Fc 54.7 Hz / F3 62 Hz**. The completed prototype must instead be assessed from its installed impedance and acoustic measurements; see [DRIVER_ANALYSIS.md](DRIVER_ANALYSIS.md).

Width and depth modes remain clustered near **700 Hz**. Retain the present geometry and use bracing, damping, and measurement rather than resizing solely to separate them.

## 3. Cabinet construction

Locked construction choices:

- main cabinet panels: **18 mm plywood**;
- front baffle: two laminated layers of 18 mm plywood, total **36 mm**;
- final cosmetic finish likely to be veneer over the plywood;
- solid hardwood is not required structurally and is not expected to improve acoustic performance.

The cabinet must be airtight, accurately assembled, well braced, internally damped, and free from large unsupported panel spans.

### 3.1 Fastener schedule

To minimise distinct hardware types:

- **M4 × 30 mm black countersunk Pozi machine screws**: rear panel and tweeter, into M4 inserts;
- **M4 × 10 mm Type E non-flanged threaded inserts**: rear frame, centre-brace landing, and tweeter; selected for manufacturability and their ability to be recessed below the plywood surface;
- **No. 8 × 1 in black countersunk Pozi screws**: woofer, direct into plywood; a pragmatic prototype choice that may be improved later;
- **No. 4 × 3/4 in black countersunk Pozi screws**: speakON connector.

## 4. Front baffle

The current baffle design is considered substantially complete.

### 4.1 Overall geometry

- baffle size: approximately **280 × 430 × 36 mm**;
- woofer and tweeter vertically aligned;
- driver centre-to-centre spacing: **150 mm**;
- both drivers flush-recessed;
- no separate driver gaskets: both drivers use their manufacturer-fitted gaskets;
- woofer rear cut-out: approximately Ø148 mm for 18 mm behind the mounting plane, followed by an approximately 11.5 mm, 45° relief to Ø171 mm; this relief is retained to reduce throat reflection and basket shadowing;
- tweeter rear opening kept close to the required body clearance rather than heavily flared.

### 4.2 Edge treatment

All baffle edges use approximately **25 mm radius roundovers**. The side roundovers are most important; retain 25 mm where practical, prioritising a smooth and consistent profile. A reduction to 20 mm is an acceptable manufacturing fallback.

### 4.3 Driver mounting status

For the selected Ø8.5 mm **Type E non-flanged M4 inserts**, retain about **5 mm of sound plywood beyond the insert OD** to any free or cut edge—roughly **9.25 mm insert-axis-to-edge**—with 6 mm preferred and less than 4 mm high-risk. The modelled **Ø5.5 mm pilot is a deliberate, slightly undersized prototype choice**, not a drafting error; confirm insertion behaviour, holding strength, and resistance to ply splitting or delamination in an offcut of the actual plywood before machining the cabinet.

Tweeter mounting:

- recessed Type E non-flanged M4 inserts will be installed from the enclosure side of the baffle, behind the driver-body region; retention relies on their external thread rather than a flange;
- the front portion uses M4 clearance bores and the insert-sized pilots are confined to the rear portion;
- the rear opening includes local clearance around the two terminal “ears” without unnecessarily enlarging the opening around the rest of the tweeter body;
- exact body, terminal, connector, and wiring clearance will be fitted to the physical tweeter because the available 3D model is not a manufacturing drawing.

Prototype woofer mounting:

- basket, airflow, and edge-clearance constraints prevent suitable local mounting islands or conventional M4 wood inserts;
- the specified No. 8 × 1 in screws will be used directly in the plywood for the prototype;
- the accepted CAD uses approximately Ø3.0 mm pilots, slightly below the representative 3.10 mm thread-root diameter; confirm the actual screws in the complete plywood laminate;
- metal backing plates, captive nuts, or another repeatable fastening system remain possible later production refinements.

The woofer fasteners need only compress the flange gasket evenly. They should not be tightened to general-purpose metal-fastener torque.

### 4.4 Final machining checks

Before cutting a repeat or final baffle:

- measure the actual physical drivers;
- make test rebates in scrap;
- include clearance for veneer, adhesive, finish, and manufacturing tolerance;
- confirm flange depth after gasket compression;
- ensure adequate material remains between the two driver rebates;
- preserve full-thickness material around mounting points;
- verify the rear-installed tweeter inserts and corrected body clearance in a full-depth test piece;
- test the selected woofer fastening method in the complete 36 mm plywood laminate, including repeated removal and refitting, tightening feel, pull-out resistance, and any tendency for the plies to split or delaminate.

## 5. Other cabinet panels

The side, top, bottom, and removable rear panel may remain simple rectangles.
Speaker one is complete; exact repeat/production cutting dimensions and joinery
still need to be reconciled with the fitted prototype and back-annotated into
the fabrication record before speaker two is cut.

## 6. Rear panel and prototype access

For the prototype, the rear panel should be:

- removable, flush or slightly recessed rather than proud;
- provided with deliberate peripheral assembly clearance for manufacturing tolerance and finish;
- sealed by **15 × 2 mm self-adhesive closed-cell neoprene sponge strip** around the perimeter only;
- fixed by M4 countersunk machine screws into recessed Type E non-flanged threaded inserts in the internal rear frame;
- sufficiently supported and evenly sealed so it does not become a large radiating panel.

Current rear-panel details:

- the approximately **242 × 392 mm** panel has about **1 mm clearance per edge** within the approximately 244 × 394 mm opening;
- 16 perimeter inserts are centred in approximately 20 mm-wide frame rails, about 10 mm from either rail edge;
- the panel screw holes use approximately **Ø4.5 mm shank clearance**; countersink angle, mouth diameter, and depth will be cut to the actual 90° M4 screw heads during the prototype build rather than copied literally from the current CAD representation;
- the main horizontal brace has no compressible centre gasket: it should meet the panel at a rigid central landing, with deliberate clearance elsewhere;
- the modelled central landing is approximately **40 mm wide**, uses the full brace thickness, and is fitted to the panel position only after the actual neoprene reaches a comfortable, repeatable working compression; the single central M4 screw supplies preload rather than bending the panel into contact or crushing the gasket to a nominal dimension.

The final production version may use a permanently glued rear panel after the crossover and damping are settled.

## 7. Prototype connector

The prototype brings woofer and tweeter connections out separately through a **Neutrik speakON NL4** so the development crossover can remain external. The connector and rear panel must remain airtight. A right-angle plug will enable the cabinet to remain at its design distance from the rear wall.

Pin allocation and development-crossover safety are specified in [CROSSOVER_DESIGN.md](CROSSOVER_DESIGN.md).

## 8. Bracing

Use single-piece **window braces** fitted to the internal cross-section, with large openings and perimeter glue joints tying opposite panels together.

For the removable-rear prototype, the main brace does not depend on a permanent glue joint to the rear panel. Its small, rigid central landing is mechanically clamped to the panel, while the remainder of the brace edge stays at least approximately 1 mm clear to prevent intermittent contact or buzzing.

Likely initial bracing:

- one main horizontal window brace;
- secondary upper, lower, and rear-panel stiffeners;
- placement chosen to avoid the woofer magnet vent, terminals, and connector;
- generous openings so the enclosure remains one acoustically connected volume.

Selected brace corners are chamfered to ease installation of damping material; elaborate internal coving is not required.

## 9. Internal damping and stuffing

Use open, air-permeable **4 oz polyester/Dacron upholstery wadding**, chosen for clean, stable, and readily adjustable prototype damping.

Provisional use:

- one layer on the side, top, and bottom walls;
- two or more layers on the rear wall behind the woofer;
- optional additional loose fill in the remaining volume;
- keep clear of the woofer basket, cone, surround, pole-piece vent, terminals, and tweeter connections;
- do not compress it flat.

The amount and distribution must be recorded and adjusted using repeatable impedance and acoustic measurements. Treat the geometric 21.7 L volume separately from any damping-induced effective-volume increase.

## 10. Feet and support

Use four approximately **32 × 32 × 16 mm soft silicone-rubber feet**. Their installed rise is approximately **15 mm**, giving a supported cabinet height of about **445 mm**. They suit the intended shelf placement, reduce rattles and surface transmission, and provide repeatable positioning without spikes.

## 11. Open mechanical items

- repeat/production cutting list and detailed joinery for the 430 mm-high body;
- exact rear-panel countersink dimensions after trial fitting the actual screws;
- final working compression of the neoprene strip and resulting central-landing fit;
- exact empirical tweeter body, terminal, connector, and wiring clearance;
- any later production replacement for the prototype woofer wood-screw mounting;
- final damping quantity and distribution;
- inductor interlock and PCB restraint interfaces with the cabinet;
- final crossover mounting position;
- final veneer and finish.

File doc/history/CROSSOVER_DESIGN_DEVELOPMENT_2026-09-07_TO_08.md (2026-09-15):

# Crossover Design Development - 2026-09-07 to 2026-09-08

> - **Lifecycle:** HISTORY / SUPERSEDED DESIGN DEVELOPMENT
> - **Owns:** exploratory Seed A and Seed B modelling, predecessor VXP review, and resolved VXP serialisation/connectivity errors
> - **Does not own:** current Seed A decision, measured-component model, or validation gate
> - **Read when:** auditing why Seed A was selected, reproducing a historic calculation, or diagnosing an old VXP
> - **Current consequence:** retain measured same-polarity third-order Seed A; current evidence is in [Crossover design](../CROSSOVER_DESIGN.md)
> - **Last reviewed:** 2026-09-15

This record retains dated calculations and superseded VXP interpretation. They
were useful selection evidence, not measured filtered-system evidence.

## 1. Exploratory Seed A

An independent complex nodal fit compared second-, third-, and fourth-order
scaffolds in both polarities against native TW1/C2 FRDs and installed ZMAs,
penalising phase mismatch, low impedance, tweeter attenuation, and woofer
breakup. The simplest useful seed was same-polarity third order:

| Branch | Source-to-driver order | Seed value |
|---|---|---:|
| Woofer | L(W1), shunt C(W1), L(W2) | `0.72 mH` / `18.0 uF` / `0.11 mH` |
| Tweeter | C(T1), shunt L(T1), C(T2), R(Tser) | `12.2 uF` / `0.22 mH` / `22.5 uF` / `1.40 ohm` |
| Tweeter shunt | R(Tpar) directly across tweeter | `39 ohm` |
| Polarity | both drivers | normal / same |

Estimated DCRs (`0.165`, `0.097`, `0.083 ohm`) and capacitor ESRs
(`0.01 ohm`) were planning inputs, not measurements. The longer-window
calculation predicted `2.12 kHz` equality, `16.8 degrees` relative phase,
`16.6 dB` reverse null, `3.71 ohm` minimum near `2.66 kHz`, `-24.8 dB`
tweeter attenuation at `1 kHz`, and woofer output `15.4 dB` below tweeter at
`5 kHz`. The former fourth-order scaffold predicted `2.77 kHz`,
approximately `102 degrees`, and poor summation, so it was superseded.

The positive `+20/+40/+60 degree` raw-driver data supported a handover region
near `2.2-2.3 kHz` without defining it to the nearest hundred hertz. The
woofer's local `+40 degree`, `2.2 kHz` feature carried approximately
`0.8 dB` window-choice uncertainty. The vertical pivot was in the front-baffle
plane on the horizontal driver centreline; positive rotation was anti-clockwise
viewed from above. Use only the measured positive side; no full-space/directivity
conclusion follows.

## 2. Nominal sparse-polar VXP and correction

[`vituixcad/Prototype loudspeaker crossover Seed A sparse polar verified 2026-09-07.vxp`](../../vituixcad/Prototype%20loudspeaker%20crossover%20Seed%20A%20sparse%20polar%20verified%202026-09-07.vxp)
was `26,630` bytes with SHA-256
`e8235831de072724d95ad0a5d1b84fb57bc4235693953d717626b5fadb8d3538` at
review. It contains two drivers, eight electrical components, twelve sources,
and explicit horizontal `0/+20/+40/+60 degree` entries per driver; the current
practical VXP retains sources/settings and substitutes measured values.

The stored C2 scale `3.6057864302164244` is a linear multiplier, displayed by
VituixCAD as `20 log10(3.6057864302164244) = 11.140 dB`. Intermediate files
that stored `11.14` applied about `+20.94 dB`, over-weighting the tweeter by
about `9.80 dB`; their acoustic plots are invalid. Separately, R2=`39 ohm`
was initially in series below D2 rather than across it. The retained verified
VXP has R2 in parallel and R1=`1.4 ohm` in series; the later R(Tpar) symbol
move was cosmetic. Earlier source, level-corrected, corrected, and redundant
on-axis variants were deleted at the user's request after their reconstruction
inputs and failure modes were recorded. None validates Seed A.

The verified sparse-polar VXP uses the tweeter's `1.5 ms` polar window rather
than the `3.5 ms` on-axis design FRD. Its calculation gives `2.101 kHz`,
`6.4 degrees`, and a `25.1 dB` reverse null; the longer-window seed's
`2.12 kHz`, `16.8 degrees`, and `16.6 dB` are an analysis-window
difference, not a physical timing change. Its calculated `3.705 ohm` minimum
near `2.655 kHz` at `-10.4 degrees` was later superseded for hardware
judgement by the as-built load measurement.

## 3. Signal-free audit and bounded Seed B comparison

The longer-window replay gave `2.102 kHz`, `16.1 degrees`, `5.71 dB`
constructive addition, `16.84 dB` normal-to-reverse difference, and a
`3.705 ohm` minimum. It showed a reasonable tweeter rise but only about
`9.1 dB` woofer fall from `2.1-4.2 kHz`; raw breakup counteracted electrical
roll-off. A conventional added woofer shunt capacitor (`1-22 uF`) made that
fall progressively shallower, while a larger second inductor worsened phase,
null, and response span. This was a provisional hold, not a construction gate.

The deterministic Seed B search fixed the Seed A tweeter branch and required
`2.05-2.25 kHz` equality, at most `20 degrees`, at least `15 dB` reverse
difference, at most `4.2 dB` robust `1-5 kHz` span, and at least `3.5 ohm`
minimum impedance. DCR scaled with square-root inductance, so comparisons were
not construction specifications. The strongest three-reactance result
(`0.739 mH / 15.34 uF / 0.320 mH`) improved woofer fall `-8.89` to
`-12.15 dB` and `5 kHz` separation `-15.50` to `-17.36 dB`, but worsened
span `3.46` to `4.20 dB`, phase `16.93` to `19.52 degrees`, reverse
difference `16.52` to `15.27 dB`, and minimum impedance `3.707` to
`3.599 ohm`. Four-reactance searches reduced their added capacitor to
`0.06-0.14 uF`, electrically negligible. A series-RLC shunt could fit a
narrow `4.2 kHz` dip but did not meet all system gates. No Seed B was promoted.

This comparison selected Seed A for a reversible build. Measured construction,
acoustic evidence, load, and bounded level/thermal evidence subsequently
replaced the signal-free work as the current authority.

## 4. Retained sparse-polar directivity detail

The protected-tweeter `+20/+40/+60 degree` archive passed identity, timing,
impulse, and window-sensitivity review. With its matched `1.5 ms` right
window, it remained broad through approximately `2.1-2.4 kHz` and narrowed
progressively above about `4 kHz`. The completed woofer family passed UUID,
metadata, impulse-envelope, reflection, window, and native-response review.
A common `3.5 ms` right window was stable enough: changing to `3.0 ms`
changed derived directivity over `1.8-2.6 kHz` by `0.13-0.53 dB RMS`.

At `2.4 kHz`, woofer changes from on-axis were `-0.94`, `-1.80`, and
`-4.39 dB` at `+20`, `+40`, and `+60 degrees`; at `3.0 kHz` they were
`-1.63`, `-4.20`, and `-9.75 dB`. One-sixth-octave mismatch between
woofer and tweeter was lowest near `2.2-2.3 kHz`: `1.99 dB` at `2.2 kHz`
and `2.05 dB` at `2.3 kHz`, against `3.32 dB` at `2.1 kHz`,
`3.10 dB` at `2.4 kHz`, and about `3.8 dB` at `2.5-2.6 kHz`.

The preliminary Seed A polar calculation gave extrema over `1.8-3.0 kHz` of
`-1.74/+0.29 dB` at `+20 degrees`, `-1.94/+2.11 dB` at `+40 degrees`,
and `-3.12/+0.43 dB` at `+60 degrees`. The positive `+40 degree` feature
near `2.2 kHz` appeared in both drivers and overlapped the approximately
`0.8 dB` local woofer window uncertainty. It did not justify fine
optimisation or further raw sweeps.

## 5. Retained signal-free branch detail

At the measured approximately `3.48 ohm` tweeter impedance near `2.3 kHz`,
`39 ohm` in parallel gives about `3.20 ohm`; with `1.40 ohm` series its
resistive divider is about `-3.15 dB`. The complete high-pass was about
`-3.88 dB` at `2.3 kHz` and its `8-10 kHz` passband about `-2.70 dB`;
filtered tweeter output at `1 kHz` was about `24.4 dB` below `8-10 kHz`.
The ideal LR4 reference was diagnostic, not an order requirement.

For resistor planning only, the pad-only model assigned approximately `30%`
of real input power to the `1.40 ohm` series resistor and `6%` to the
`39 ohm` shunt over `2.3-10 kHz`. If `20 W` reached the pad, that was
about `6.0 W` and `1.2 W`; actual selected-bank construction superseded
this planning calculation.

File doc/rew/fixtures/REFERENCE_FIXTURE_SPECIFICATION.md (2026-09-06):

# Amplifier-Output Reference Fixture — Specification

Lifecycle: **CURRENT SPECIFICATION**
Owns: electrical design, construction requirements, component evidence,
attenuation/loading/fault calculations, and redesign constraints.
Does not own: operating sequence or completed test evidence.
Use procedure: [`REFERENCE_FIXTURE_USE.md`](REFERENCE_FIXTURE_USE.md)
Qualification:
[`../qualification/REFERENCE_FIXTURE_QUALIFICATION_2026-09-01_TO_03.md`](../qualification/REFERENCE_FIXTURE_QUALIFICATION_2026-09-01_TO_03.md)
Last reviewed: 2026-09-06

## 1. Functional Definition

The fixture derives a protected electrical reference from one Technics SU-V570
speaker-output pair for a two-channel REW measurement. It comprises:

1. a `2 m`, red/black, `1.5 mm^2` two-conductor input cable;
2. two symmetric `9.1 kohm` series and `1.0 kohm` shunt divider legs;
3. two independent bidirectional `5.1 V` zener clamp pairs;
4. an approximately `5 cm` twisted tip/ring/sleeve output tail; and
5. a 1/4-inch TRS plug.

The electrical reference removes DAC/amplifier gain and response from the
derived acoustic transfer function and supplies common timing. The current
connection references amplifier terminals, not the driver end of the separate
speaker cable. The true-RMS meter remains the authority for setting driver
voltage.

The SU-V570 has passed the unpowered common-ground topology gate, but neither
speaker conductor is hard-wired to fixture sleeve. Both legs are attenuated.
This preserves a floating symmetric network when disconnected and avoids
building an additional direct ground bond into the fixture.

The protection layers are:

- R1/R2 `9.1 kohm`, minimum `0.5 W`, as primary current limiters;
- R3/R4 `1.0 kohm` shunts, providing approximately 20 dB attenuation;
- series-opposed `5.1 V` zener pairs as secondary open-shunt/overvoltage
  protection; and
- construction, resistance, DC, ground-path, and proportionate AC tests.

The fixture is not mains isolation, protective earth, a speaker load, or a
substitute for amplifier safety testing. It cannot protect a construction error
that bypasses a series resistor.

## 2. Electrical Schematic

The installed clamp pairs are series-opposed with anodes joined. A
common-cathode pair is electrically equivalent. Each midpoint is individually
insulated and connected nowhere else.

```text
         2 m, 1.5 mm^2                    ~5 cm TWISTED T/R/S WIRES
       RED amplifier lead                       TO 1/4-INCH TRS

SU + o================o-- R1 9.1 kohm, 0.5 W --+---------- T (tip)
                                                |
                                                +-- R3 1.0 kohm --+
                                                |                 |
                                                +--K D1 A--A D2 K-+
                                                                  |
                                                                  +------ S
                                                                  |
                                                +--K D3 A--A D4 K-+
                                                |                 |
                                                +-- R4 1.0 kohm --+
                                                |
SU - o================o-- R2 9.1 kohm, 0.5 W --+---------- R (ring)

      BLACK amplifier lead
```

Fixture sleeve is not directly connected to the black amplifier lead.
UMC202HD Input 2 outer XLR contacts remain unused. UMC22 use is controlled by
its separate risk acceptance and qualification.

## 3. Bill Of Materials And Retained Evidence

| Ref. | Requirement | Present evidence and limitation |
| --- | --- | --- |
| Input cable | `2 m`, joined red/black `1.5 mm^2`; insulation suitable for completed `64.5 V DC` test | No printed manufacturer/rating; complete fixture passed; secure bare-wire amplifier end |
| R1 | `9.1 kohm`, 1%, metal film, at least `0.5 W`, working voltage above `100 V` | User-confirmed Mouser part, part number unretained; complete path `9.125 kohm` pre-stress, `9.127 kohm` post-stress |
| R2 | Same as R1 | Complete path `9.139 kohm` pre-stress, `9.141 kohm` post-stress |
| R3 | `1.0 kohm`, 1%, metal film, at least `0.25 W` | `1.002 kohm` pre/post-stress |
| R4 | Same as R3 | `1.003 kohm` pre-stress, `1.004 kohm` post-stress |
| D1-D4 | Four matched `5.1 V` small-signal zeners, two opposed pairs; traceable `BZX55B5V1` or `BZX55C5V1` preferred for a reproducible build | Marked `BZX 5V1`; manufacturer, suffix, tolerance, and rating unknown; each near `5 V` at `2 mA`; installed bidirectional behaviour passed |
| Output tail | Shielded balanced pair preferred; very short twisted T/R/S allowed with noise check | Approximately `5 cm` of three twisted, insulated `14/0.7` hookup wires; no overall screen |
| Plug | 1/4-inch TRS, contacts exactly as schematic | Unknown make/model; all-metal body bonded to sleeve; internal insulator and cable clamp; mapping passed |
| Body | Insulating enclosure and strain relief; no exposed joints | Approximately `6 cm` multilayer heat-shrink body; individually insulated parts/junctions; bench-use limitation |

A reproducible future build should use fully traceable resistors, zeners, cable,
plug, and enclosure. Do not infer missing manufacturer ratings from generic
part-family expectations.

## 4. Construction Requirements

1. Keep red and black input conductors together for their full route. Do not
   form separate loops around the room.
2. Prevent R1/R2 bodies or leads contacting one another, sleeve, enclosure
   hardware, or clamp parts.
3. Use sleeve as the local star point only for R3, R4, clamp endpoints, and the
   output-tail sleeve.
4. Put each clamp pair close to its signal node and sleeve connection. Insulate
   the joined midpoint; do not use it as a ground or test point.
5. Provide independent strain relief for the heavy input cable and output tail.
   Solder joints must carry no cable tension.
6. Permanently mark the amplifier end `RED +` and `BLACK -`, and mark the TRS
   plug `UMC202HD INPUT 2 - CENTRAL TRS - LINE` where that interface is used.
7. Use fully insulated/shrouded connections for high-voltage DC qualification.
8. Ensure the bare-wire amplifier termination is fully captured and cannot
   bridge adjacent binding posts. Inspect and pull-test before use.

**RECORDED CONSTRUCTION — 2026-09-03:** joined figure-of-eight insulation
continues over the `2 m` input cable except approximately `5 cm` at the
amplifier end and `2 cm` at the fixture. Components form a free-air soldered
network with individually heat-shrunk bodies/leads, additional junction
insulation, and overlapping overall heat-shrink. Tapered layers and internal
wire returns transfer moderate pull into encapsulation. All conductors and both
zener midpoints are inaccessible. Sleeve is the verified local star.

The output tail is deliberately unscreened. Its short twisted construction and
approximately `1 kohm` shunts keep loop area and node impedance moderate, but it
is not electrostatically equivalent to screened balanced cable. Actual
full-system no-signal noise and movement sensitivity are therefore required
measurement-quality checks.

Unknown heat-shrink identity means no specific dielectric, abrasion,
temperature, or flame rating is claimed. Passing the `64.5 V DC` test and
post-stress matrix supports careful bench use only—not permanent installation,
crushing, abrasion, unattended operation, or use after damage.

## 5. Cable Resistance And Attenuation

At approximately `20 degrees C`, with copper resistivity
`rho ~= 0.0172 ohm mm^2/m`, each `2 m`, `1.5 mm^2` conductor is estimated at:

```text
Rlead = rho x length / area
      = 0.0172 ohm mm^2/m x 2 m / 1.5 mm^2
      = 0.0229 ohm
Rloop = 0.0459 ohm
```

At `1.00 V RMS`, divider current is about `99 uA`, so one lead drops only
about `2.3 uV`. Even `4.50 mA` fault current drops about `0.10 mV`; cable
resistance is negligible in the divider ratio.

Nominal one-leg transfer, with sleeve externally tied to amplifier reference:

```text
k = 1.0 kohm / (9.1 kohm + 1.0 kohm) = 0.099010
A = 20 log10(k) = -20.086 dB
```

Measured pre-stress branch values give:

```text
k_tip  = 1.002 / (9.125 + 1.002) = 0.098943 = -20.092 dB
k_ring = 1.003 / (9.139 + 1.003) = 0.098896 = -20.096 dB

k_floating = (1.002 + 1.003)
             / (9.125 + 1.002 + 1.003 + 9.139)
           = 0.098920 = -20.094 dB
```

These are unloaded predictions. Published UMC202HD material does not state the
`LINE` input impedance, so installed loading cannot be calculated defensibly.
Actual full-dual reference level owns installed gain; sub-decibel agreement is
not itself a safety condition.

## 6. Amplifier Loading And Fault Calculations

With external playback commoning sleeve to SU-V570 signal ground, the active
branch is approximately `10.127 kohm`. At `1.00 V RMS`:

```text
Ifixture = 1.00 V / 10.127 kohm = 98.75 uA
Pfixture = 98.75 uW
8 ohm || 10.127 kohm = 7.9937 ohm
```

The fixture changes an ideal `8 ohm` load by only `0.079%`.

The SU-V570 schematic shows approximately `+45.5 V`, `0 V`, and `-45.5 V`
rails. An ideal rail-limited sine gives `32.17 V RMS`. Divided output is
`3.18 V RMS`, `4.50 V peak`. Published amplifier conditions are lower:

| Condition | Speaker voltage | Fixture-node peak |
| --- | ---: | ---: |
| `60 W` into `8 ohm`, 20 Hz-20 kHz | `21.91 V RMS` | `3.07 V` |
| `70 W` into `8 ohm`, 1 kHz at 1% THD | `23.66 V RMS` | `3.31 V` |
| Ideal `+/-45.5 V` rail-bound sine | `32.17 V RMS` | `4.50 V` |

UMC202HD `+20 dBu` maximum line level corresponds to `7.75 V RMS` or
`10.96 V peak`; the rail-bound divided output is approximately `7.7 dB` below
that performance limit. The UMC22's lower instrument-input limit is handled by
its separate accepted-risk record.

For sustained `45.5 V DC` with shunt intact:

```text
Ifault = 45.5 V / (9.125 kohm + 1.002 kohm) = 4.49 mA
P_R1 = (4.49 mA)^2 x 9.125 kohm = 0.184 W
P_R3 = (4.49 mA)^2 x 1.002 kohm = 0.020 W
Vtip = 4.50 V
```

This supports the `0.5 W` series and `0.25 W` shunt minimums with useful
margin, subject to working-voltage and temperature derating.

## 7. Clamp Design And Redesign Constraints

Two series-opposed `5.1 V` zeners at each node produce a low-current clamp
approximately equal to zener plus forward drop:

```text
Vclamp approximately Vz + Vf approximately 5.5 to 6.2 V peak
```

The reported anode-to-anode installation is correct; polarity swaps which
device is in zener breakdown. The earlier provisional `3.3 V` choice is
superseded because its soft knee lies too close to possible `3.1-4.5 V peak`
normal divided output.

With an open shunt and `45.5 V` fault, using `5.6 V` clamp:

```text
Iclamp = (45.5 - 5.6) V / 9.125 kohm = 4.37 mA
Pzener approximately 5.0 V x 4.37 mA = 21.9 mW
```

At `64 V` commissioning with shunt intact:

```text
Iseries = (64 - 5.6) V / 9.125 kohm = 6.40 mA
Ishunt = 5.6 V / 1.002 kohm = 5.59 mA
Izener approximately 0.81 mA
Pzener approximately 4.1 mW
```

Even accidental open shunt during that current-limited test bounds zener
dissipation near `32 mW`. No `500 mW` rating is attributed to the unidentified
parts; completed four-polarity curves provide the one-off prototype evidence.

Do not substitute a power TVS without redesign and remeasurement: its rated
surge voltage may assume unavailable current and its capacitance may disturb
the audio-band reference. Do not change resistor values, clamp family,
topology, cable/reference plane, or enclosure and inherit this qualification.
A redesign must re-check attenuation, interface loading, rail/fault current,
resistor power/voltage, clamp current/knee/capacitance, construction, complete
resistance matrix, both polarities of both legs, ground paths, and low-voltage
AC behaviour.

Do not use anticipated loudness or volume position as protection. UMC202HD
`+3 dBu` output is `1.095 V RMS`; against SU-V570 `150 mV` sensitivity for
rated output, the ratio is `7.30` or `17.3 dB`, so rated amplifier output is
possible with substantial volume attenuation.

## 8. Primary Component References

- [Vishay BZX55 data sheet](https://www.vishay.com/docs/85604/bzx55.pdf)
- [Thurlby Thandar PL-series data](https://www.farnell.com/datasheets/99860.pdf)

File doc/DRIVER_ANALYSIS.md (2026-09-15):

# Driver Analysis and Measurement Record

**Project:** sealed passive two-way loudspeaker prototype
**Woofer:** SB Acoustics **SB17NRX2C35-8**
**Tweeter:** SB Acoustics **SB26STWGC-4**
**Record created:** 2026-08-27
**Last updated:** 2026-09-15

> - **Lifecycle:** ACTIVE DRIVER EVIDENCE AUTHORITY
> - **Owns:** evidence classes, approved driver ZMA/FRD sources, measurement conditions and quality, woofer/tweeter results and derivations, retention and procurement decisions, driver-specific modelling consequences, uncertainties, and next evidence gates
> - **Does not own:** REW/interface qualification chronology, fixture design, detailed acoustic-capture procedure, crossover-component construction, or room-placement evidence
> - **Current decision:** retain both installed drivers and Seed A; acoustic, as-built load, bounded level/distortion, and external-component surface-thermal gates pass proportionately
> - **Next gate:** procure/build and measure speaker two under matched conditions, including a correct immediate hot `0-degree` comparison and confirmation of the narrow approximately `1.28 dB` high-level shape change near `2.18 kHz`; retest speaker one only if the second unit reveals an anomaly
> - **Limitations:** one sample of each driver; incomplete baseline conditions; approximate rather than steady sweep-voltage readings; generic rather than absolute-SPL microphone calibration; the attempted post-thermal trace is excluded because the speaker was at `60 degrees`; contact probes do not measure voice-coil temperature; known local woofer early-tail variability near `2.03 kHz`; C2 scale is derived; the parked undamped tweeter-only mechanism and possible ultrasonic behaviour remain unproved; positive-side sparse polar evidence only
> - **As of:** 2026-09-15

This is the durable engineering record for the driver investigation. It supplements [README.md](../README.md). Detailed dated driver-impact history is retained in [DRIVER_ANALYSIS_CHANGELOG.md](history/DRIVER_ANALYSIS_CHANGELOG.md).

## 1. Authority, evidence, and current sources

### 1.1 Evidence labels

- **VERIFIED MEASUREMENT** — directly present in retained measurement evidence and independently read back or checked; a user-transcribed instrument result remains **USER-REPORTED** unless its own durable record supports verification.
- **DERIVED** — calculated from stated measured or published inputs and retained equations.
- **PUBLISHED** — manufacturer specification or manufacturer technical guidance.
- **EXTERNAL RESEARCH** — relevant non-manufacturer technical literature.
- **USER-REPORTED** — a configuration, condition, or observation reported by the user but not independently encoded in an archived measurement.
- **USER-CONFIRMED CONFIGURATION** — a user-confirmed setting or connection state used to interpret evidence.
- **INFERRED** — a physically plausible interpretation requiring assumptions that have not been measured.
- **PROVISIONAL DECISION** — a present engineering direction subject to stated test gates.
- **OPEN ITEM** — measurement, decision, or archival work still outstanding.
- **HISTORICAL EVIDENCE** — retained evidence whose conclusion or procedure has been superseded.

### 1.2 Approved impedance sources

The only current driver-impedance baselines approved for crossover modelling are:

- Woofer: [`rew/SB17NRX2C35-8 installed.zma`](../rew/SB17NRX2C35-8%20installed.zma)
- Tweeter: [`rew/SB26STWGC-4 installed.zma`](../rew/SB26STWGC-4%20installed.zma)

Both drivers were correctly mounted in the sealed prototype enclosure in their normal mechanical configuration, without temporary sealing putty. The woofer baseline was taken immediately after installation and before deliberate run-in. The matched-rate post-conditioning trace remains comparison evidence only because its approximately 0.342 ohm broadband series-resistance offset prevents promotion to the cooled modelling baseline.

### 1.3 Approved acoustic-source manifest

**PROVISIONAL DESIGN RELEASE:** retain C6 as the installed-woofer-axis source, with C5 as its immediate repeatability witness. Retain TW1 and protected-tweeter C2 as the common-position, tweeter-axis pair. The positive-side `0/+20/+40/+60 degree` woofer and protected-tweeter families are approved sparse-polar evidence. This is a prototype-design release, with the stated uncertainty; it is not a production response specification.

| Use | Current source and interpretation limit |
| --- | --- |
| Woofer-axis crossover source | `rew/SB17NRX2C35-8_installed_0deg_1m_UMC22_C6_2026-09-06.mdat`, UUID `1547767f-1781-4e51-b824-462b5a2788e1`; durable export [`000deg_1m_UMC22_2026-09-06.frd`](../rew/frd/SB17NRX2C35-8/000deg_1m_UMC22_2026-09-06.frd), SHA-256 `af3142aeff9dcd232ddb61878452c31afe5cae5446e4bd266b2e4e337488c1ca`; use `500 Hz-12 kHz`. |
| Common-position woofer source | `rew/SB17NRX2C35-8_installed_000deg_tweeter-axis_1m_UMC22_2026-09-06.mdat`, TW1 UUID `12568bef-2ec1-4cc7-be3a-91460b0659fa`; durable export [`000deg_tweeter-axis_1m_UMC22_2026-09-06.frd`](../rew/frd/SB17NRX2C35-8/000deg_tweeter-axis_1m_UMC22_2026-09-06.frd), SHA-256 `03923152b08c36e066cb0f9520c7a76489bf6837e3b85cd06c67af0c12a8e4b7`; use `500 Hz-12 kHz`. |
| Common-position protected-tweeter source | `rew/SB26STWGC-4_installed_0deg_tweeter-axis_1m_UMC22_2026-09-06.mdat`, C2 UUID `898195c2-fc7d-4eee-a877-7be9d3782f0d`; durable export [`000deg_tweeter-axis_1m_UMC22_2026-09-06.frd`](../rew/frd/SB26STWGC-4/000deg_tweeter-axis_1m_UMC22_2026-09-06.frd), SHA-256 `a409445a40e645682b188b7a12596c10f727d8a0f78138f052c043d60bb0ea1e`; use `500 Hz-12 kHz` and apply `+11.14 dB` magnitude only in VituixCAD. |
| Sparse positive-horizontal families | Woofer: `1.5-5 kHz`; protected tweeter: `1.5-12 kHz`. Use their separate `polar/` FRDs, native phase, their approved windows, and no added alignment. |

All current source identities, raw-file and FRD hashes, UUIDs, capture conditions, window validation, rejected attempts, export/release checks, polar results, and the derivation of the protected-tweeter scale are retained once in the audit-only [installed-driver acoustic-source qualification](rew/qualification/INSTALLED_DRIVER_ACOUSTIC_SOURCES_2026-09-06_TO_07.md). Read it to audit a source, change its release, investigate a failure, or reproduce an export; do not load it for routine modelling.

Durable acoustic exports use `rew/frd/<driver>/<AAA>deg_<distance>_<interface>_<date>.frd`; do not overwrite a dataset when a new condition needs a distinct identity.
### 1.4 Current driver state

- Only one woofer and one tweeter are presently available.
- The prototype's geometric net volume is approximately 21.7 L before damping-material effective-volume change.
- The cooled pre-conditioning woofer baseline has one clean sealed-box resonance at approximately 67.0 Hz and no separate resonance near 83 Hz.
- The matched 48 kHz post-conditioning trace moves the resonance to approximately 65.71 Hz, a 1.88% decrease, but still awaits a fully cooled confirmation.
- The woofer's installed total system Q is approximately 0.81–0.82 and remains manageable for development.
- The tweeter's installed impedance agrees closely with published parameters and has no suspicious additional resonance.
- Both drivers remain provisionally retained.
- Seed A's measured filtered branches cross broadly near 1.83 kHz with nearly coincident phase; constructive sum, physical reverse null, and the sparse positive-horizontal full-system set pass proportionately.
- The moderate approximately 2.5–3.1 dB beamwidth change through 1.5–2.5 kHz is retained as a possible later refinement target, not a present failure.
- The as-built Seed A load passes: minimum magnitude is `4.366 ohm`, minimum real part is `4.284 ohm`, and minimum idealised class-B EPDR is `2.563 ohm`; detailed system evidence is in the [Seed A load record](rew/qualification/SEED_A_AS_BUILT_IMPEDANCE_AND_EPDR_2026-09-09.md).
- The raw woofer, protected-tweeter, sparse-polar, Seed A acoustic/load, bounded level/distortion, and external-component surface-thermal packages are complete. The wrong-angle post-thermal trace is excluded; the next driver-relevant gate is matched speaker-two measurement, including a valid hot `0-degree` comparison and confirmation of the narrow high-level feature near `2.18 kHz`.

### 1.5 Project file-location convention

- `rew/` — raw REW measurements and impedance exports; durable acoustic
  exports use the driver-specific `rew/frd/<driver>/` subtree and the naming
  convention in Section 1.3.
- `vituixcad/` — VituixCAD projects and VituixCAD-generated outputs.

## 2. Current impedance-measurement data

### 2.1 File metadata

**VERIFIED FROM BOTH FILE HEADERS**

| Field | Value |
|---|---|
| REW version | 5.40 beta 133 |
| Interface | StarTech ICUSBAUDIO2D generic external USB sound card (**USER-CONFIRMED for all impedance measurements to date**) |
| Measurement date | 2026-08-30 |
| Sweep | 1M logarithmic swept sine, one sweep, -12 dBFS |
| Sample rate | 48 kHz |
| Sense resistor | 100.0 ohm |
| Entered lead resistance | 0.000 ohm |
| Input resistance | 20 kohm |
| Calibration factor | 0.9783 |
| Smoothing / spacing | none / 1/96 octave |
| Point count | 1,276 per file |
| Recorded span | 2.211 Hz to 22.013 kHz |

The woofer was measured at 09:30:58 and the tweeter at 10:00:22. The exported
headers preserve only a generic Windows USB-audio source name, so the StarTech
identity comes from the user's measurement-history confirmation rather than
independent file metadata. The headers do not record driver-terminal voltage,
enclosure fill state, ambient temperature, or screw torque. Those conditions
should be recorded with future comparison measurements.

### 2.2 Data quality and usable range

Both files are valid, densely sampled ZMA exports with frequency, impedance magnitude, and phase. Their traces are smooth and physically coherent through the resonances and crossover region.

**VERIFIED MEASUREMENT:** points below approximately **8-10 Hz** are measurement artifacts. They fall below credible voice-coil resistance and must not be used to estimate DCR, Q, or low-frequency load. This does not affect crossover modelling or the sealed-box result around 67 Hz.

### 2.3 Reproducible impedance-peak calculation

The fitted Q values below use a curve-consistent baseline resistance, $R_0$, estimated from the real part of impedance at 10 Hz:

$$
R_0=|Z|\cos\phi.
$$

For a single dominant impedance resonance, define the bandwidth level and crossing frequencies by

$$
Z_{th}=\sqrt{R_0Z_{max}},
$$

with $f_1$ and $f_2$ at the rising and falling crossings of that magnitude. Log-frequency interpolation between adjacent measured points is used. Then

$$
f_0=\sqrt{f_1f_2},
$$

$$
Q_m=\frac{f_0}{f_2-f_1}\sqrt{\frac{Z_{max}}{R_0}},
\qquad
Q_e=\frac{Q_m}{Z_{max}/R_0-1},
\qquad
Q_t=\frac{Q_m}{Z_{max}/R_0}.
$$

For the installed woofer these are box-system quantities $Q_{mc}$, $Q_{ec}$, and $Q_{tc}$. For the tweeter, whose own rear chamber defines its mechanical system, they are reported conventionally as $Q_{ms}$, $Q_{es}$, and $Q_{ts}$. They are approximate equivalent-circuit fits, not independent direct measurements of every loss mechanism.

## 3. Woofer published reference data

### 3.1 Manufacturer specifications

**PUBLISHED - SB Acoustics SB17NRX2C35-8 datasheet**

| Parameter | Published value |
|---|---:|
| Nominal impedance | 8 ohm |
| DC resistance, $R_e$ | 5.7 ohm |
| Voice-coil inductance, $L_e$ | 0.15 mH |
| Effective diaphragm area, $S_d$ | 118 cm2 |
| Free-air resonance, $F_s$ | 36.5 Hz |
| Sensitivity | 87 dB at 2.83 V/1 m |
| $Q_{ms}$ | 4.55 |
| $Q_{es}$ | 0.47 |
| $Q_{ts}$ | 0.42 |
| Moving mass, $M_{ms}$ | 13.9 g |
| Force factor, $Bl$ | 6.25 T m |
| Equivalent compliance volume, $V_{as}$ | 27 L |
| Suspension compliance, $C_{ms}$ | 1.37 mm/N |
| Mechanical resistance, $R_{ms}$ | 0.7 kg/s |
| Linear excursion, $X_{max}$ | +/-5.5 mm |
| Rated power | 50 W |

### 3.2 Published-parameter enclosure prediction

Using the published $F_s=36.5$ Hz, $Q_{ts}=0.42$, $V_{as}=27$ L, and the approximately 21.7 L geometric net volume gives:

- **DERIVED:** $F_c\approx54.7$ Hz;
- **DERIVED:** $Q_{tc}\approx0.63$;
- **DERIVED:** ideal anechoic small-signal $F_3\approx62.3$ Hz;
- no response peak from the nominal second-order sealed alignment.

These remain a record of the datasheet-based design case, not a description of the completed prototype.

## 4. Woofer installed measurement

### 4.1 Principal measured features

**VERIFIED MEASUREMENT / DERIVED FROM CURRENT ZMA**

| Quantity | Result |
|---|---:|
| Curve-consistent $R_0$ estimate | 5.645 ohm |
| Impedance magnitude maximum | 96.544 ohm at 67.272 Hz |
| Bandwidth threshold, $Z_{th}$ | 23.345 ohm |
| Lower threshold crossing, $f_1$ | 57.811 Hz |
| Upper threshold crossing, $f_2$ | 77.583 Hz |
| Derived sealed-system resonance, $F_c$ | 66.971 Hz |
| $Q_{mc}$ | 14.008 |
| $Q_{ec}$ | 0.870 |
| $Q_{tc}$ | 0.819 |
| Positive phase maximum | +61.79 degrees at 57.81 Hz |
| Negative phase minimum | -63.54 degrees at 77.16 Hz |

The impedance maximum is a magnitude in **ohms**, not an inductance. Its height mainly reflects motional back-EMF and the balance of mechanical and electrical damping. High impedance at resonance is not an amplifier-current hazard.

The close agreement between the curve-derived $R_0\approx5.645$ ohm and the published $R_e=5.7$ ohm is reassuring. A nulled cold-DCR measurement taken with this setup would still be preferable when an exact series-resistance model is required.

### 4.2 The secondary-resonance question

**VERIFIED MEASUREMENT:** the correctly installed woofer trace has one low-frequency resonance only. At **82.94 Hz**, the impedance is **16.46 ohm at -61.06 degrees**, lying smoothly on the falling side of the 67 Hz peak. There is no local maximum or phase reversal there.

This is strong evidence that a distinct feature near 83 Hz is not inherent to the normally installed driver/enclosure system. The ordinary mounting has eliminated the leak-related mode without needing temporary sealing compound.

### 4.3 Idealized low-frequency consequence

For a normalized second-order sealed high-pass response,

$$
|H(x)|^2=\frac{x^4}{(1-x^2)^2+x^2/Q_{tc}^2},
\qquad x=\frac{f}{F_c}.
$$

Using the measured $F_c=66.97$ Hz and derived $Q_{tc}=0.819$:

- **DERIVED:** ideal anechoic small-signal $F_3\approx59.0$ Hz;
- **DERIVED:** a modest maximum of approximately **+0.29 dB near 133 Hz**;
- $F_3$ lies below $F_c$, as expected because $Q_{tc}>0.707$.

The apparently similar or slightly lower $F_3$ than the published-parameter design case does not mean equal deep-bass behaviour. With both responses normalized at high frequency, the idealized installed alignment differs approximately as follows:

| Frequency | Installed minus published-parameter case |
|---:|---:|
| 30 Hz | -2.28 dB |
| 40 Hz | -1.32 dB |
| 50 Hz | -0.33 dB |
| 80 Hz | +1.11 dB |
| 100 Hz | +1.08 dB |
| 150 Hz | +0.64 dB |

Physical interpretation: relative to the nominal design calculation, this state trades some output below roughly 50 Hz for a mild broad lift through the upper bass. The predicted lift is small enough to remain quite plausible for the intended prototype, but room placement and the eventual woofer-series resistance will matter.

These response figures are **DERIVED**, not acoustic measurements. They assume that the installed system is adequately represented by a linear second-order sealed model. Leakage, damping material, baffle step, room gain, crossover resistance, excursion, and thermal effects are not included.

### 4.4 Crossover-region impedance

**VERIFIED FROM CURRENT ZMA**

| Frequency | \|Z\| | Phase |
|---:|---:|---:|
| 2199.83 Hz | 7.9687 ohm | +10.425 degrees |
| 2297.23 Hz | 7.9767 ohm | +10.753 degrees |
| 2398.93 Hz | 8.0119 ohm | +11.068 degrees |
| 2505.14 Hz | 8.0403 ohm | +11.499 degrees |

The woofer is close to 8 ohm in magnitude around the intended crossover, but it is not an 8 ohm resistor. At 2297 Hz its rectangular equivalent is approximately $7.84+j1.49$ ohm. The full ZMA should therefore be used in VituixCAD.

There is no strong electrical anomaly in the 2.2-2.5 kHz region. Small higher-frequency impedance structure cannot establish cone-breakup amplitude or acoustic suitability; the installed FRD and distortion measurements remain decisive.

### 4.5 Woofer judgement

**PROVISIONAL DECISION:** retain the SB17NRX2C35-8 in the present enclosure.

The measured $Q_{tc}\approx0.82$ sits inside the project's broadly manageable **0.75-0.95** development range. The alignment is warmer than the published-parameter design case but is not severely resonant. No additional low-frequency mode survives normal installation, and the impedance near the intended crossover is smooth and convenient to model.

The later bounded complete-system package establishes proportionate acoustic,
level/distortion, and broad-compression evidence for speaker one. Pair matching
and production spread remain open.

### 4.6 Conditioning status and current baseline

**CURRENT DECISION:** the cooled pre-conditioning installed ZMA remains the crossover baseline. The matched 48 kHz post-conditioning trace remains comparison evidence because its approximately `+0.342 ohm` broadband real-series offset prevents promotion. The detailed 45 Hz and 30 Hz operating estimates, comparison calculation, and supersession rationale are retained in [Driver-analysis change history](history/DRIVER_ANALYSIS_CHANGELOG.md).

Use [DRIVER_RUNIN.md](DRIVER_RUNIN.md) for any future bounded conditioning, cooldown, cold-DCR, calibration, rested-confirmation, safety, and measurement-based stopping rules. No dedicated tweeter run-in is justified.
## 5. Tweeter published reference data

### 5.1 Manufacturer specifications

**PUBLISHED - SB Acoustics SB26STWGC-4 datasheet**

| Parameter | Published value |
|---|---:|
| Nominal impedance | 4 ohm |
| DC resistance, $R_e$ | 3.2 ohm |
| Voice-coil inductance, $L_e$ | 0.04 mH |
| Effective diaphragm area, $S_d$ | 6.2 cm2 |
| Resonance, $F_s$ | 780 Hz |
| Sensitivity | 93 dB at 2.83 V/1 m |
| $Q_{ms}$ | 2.8 |
| $Q_{es}$ | 2.1 |
| $Q_{ts}$ | 1.2 |
| Force factor, $Bl$ | 1.6 T m |
| Moving mass, $M_{ms}$ | 0.3 g |
| Linear excursion, $X_{max}$ | +/-0.6 mm |
| Rated power statement | 120 W with the manufacturer's stated 2.6 kHz, 12 dB/octave Butterworth high-pass condition |

The 120 W figure is conditional, not an unconditional broadband power rating.

## 6. Tweeter installed measurement

### 6.1 Principal measured features

**VERIFIED MEASUREMENT / DERIVED FROM CURRENT ZMA**

| Quantity | Installed result | Published |
|---|---:|---:|
| Curve-consistent $R_0$ estimate | 3.274 ohm | $R_e=3.2$ ohm |
| Impedance magnitude maximum | 7.557 ohm at 755.62 Hz | not stated |
| Bandwidth-derived $F_s$ | 760.91 Hz | 780 Hz |
| $Q_{ms}$ | 2.622 | 2.8 |
| $Q_{es}$ | 2.005 | 2.1 |
| $Q_{ts}$ | 1.136 | 1.2 |
| Positive phase maximum | +24.04 degrees at 574.31 Hz | not stated |
| Negative phase minimum | -22.32 degrees at 979.91 Hz | not stated |

The fitted resonance is approximately **2.4% below** the published value; the fitted Q values are within approximately **5-6%**. This is close agreement for a real installed sample and shows no electrical reason to doubt the tweeter.

The magnitude maximum occurs a few hertz below the bandwidth-derived resonance because the rising voice-coil impedance and the discrete frequency samples make the magnitude-peak and ideal phase-centre definitions slightly different. Reporting the result as approximately **761 Hz** is appropriately precise.

### 6.2 Crossover-region impedance

**VERIFIED FROM CURRENT ZMA**

| Frequency | \|Z\| | Phase |
|---:|---:|---:|
| 2199.83 Hz | 3.4884 ohm | -5.699 degrees |
| 2297.23 Hz | 3.4768 ohm | -5.032 degrees |
| 2398.93 Hz | 3.4786 ohm | -4.445 degrees |
| 2505.14 Hz | 3.4787 ohm | -3.725 degrees |

Around the intended crossover the tweeter is approximately **3.48 ohm**, nearly resistive but mildly capacitive. At 2297 Hz its rectangular equivalent is approximately $3.46-j0.30$ ohm. It must not be modelled as a frequency-independent 4 ohm resistor.

There are no suspicious secondary impedance peaks. The normal installed mounting has not introduced an evident rear-cavity or front-cavity electrical resonance.

### 6.3 Tweeter judgement

**PROVISIONAL DECISION:** retain the SB26STWGC-4.

The then-intended `2.2-2.4 kHz` region was approximately three times the
measured resonance frequency. That ratio was only a preliminary plausibility
check; the later installed, filtered, summed, and bounded level evidence now
owns the Seed A decision.

No dedicated tweeter run-in is presently justified. Use the baseline and protected-use procedure in [DRIVER_RUNIN.md](DRIVER_RUNIN.md); never apply an unfiltered conditioning signal directly to the bare tweeter.

### 6.4 Measurement protection and current geometry

**CURRENT CONFIGURATION / DERIVED MODEL CORRECTION:** the common-position source pair uses the fixed microphone on the tweeter axis, `1.000 m` from the baffle-plane pivot; preserve its measured relative timing and do not add a geometric delay. The raw tweeter was captured through the measured `10.13 uF`, `0.08 ohm` ESR series protection capacitor. Its post-capacitor reference leaves a constant `+11.14 dB` magnitude correction for VituixCAD; apply no phase, delay, polarity, smoothing, or minimum-phase correction. This correction is not an absolute-SPL calibration.

Use `Hann 2.0 ms` left / `Tukey 0.25 3.5 ms` right at each own direct peak, with FDW and MTW off, for the phase-bearing on-axis sources. The woofer polar family uses that window; the protected-tweeter polar family uses a `1.5 ms` right window. Preserve native phase and interpret the woofer polar family only over `1.5-5 kHz` and the protected-tweeter family only over `1.5-12 kHz`.

The qualified UMC22 electrical route, protection component, direct sound geometry, source windows, raw capture provenance, and all release checks are in the [installed-driver acoustic-source qualification](rew/qualification/INSTALLED_DRIVER_ACOUSTIC_SOURCES_2026-09-06_TO_07.md). The repeat procedures own the safe operational sequence.
## 7. Driver-specific modelling consequences

### 7.1 Current VituixCAD inputs

Use only `rew/SB17NRX2C35-8 installed.zma` and `rew/SB26STWGC-4 installed.zma`. In `vituixcad/Prototype loudspeaker crossover Seed A practical measured 2026-09-08.vxp`, use the verified common-position TW1/C2 FRDs and sparse `0/+20/+40/+60 degree` families, with native phase, normal polarity, zero coordinates, no response delay/smoothing/minimum-phase conversion, woofer `0.00 dB`, and tweeter `+11.14 dB` (`3.605786` linear multiplier). This is source configuration, not a new crossover decision.

The practical model contains the measured capacitor, resistor, inductor, ESR, and DCR values. The older nominal-component sparse-polar project and its screenshots are historical corroboration only; do not use them as present component evidence. Generated unmeasured-angle curves and the positive-side sparse set remain outside the model evidence boundary.

### 7.2 Full-system level, distortion, and thermal consequence

**VERIFIED MEASUREMENT / USER-REPORTED CONDITIONS / DERIVED — BOUNDED PASS
WITH ONE DEFERRED COMPARISON (2026-09-10):** the retained
[`rew/SPK_Seed_A_full_system_level_thermal_20260910.mdat`](../rew/SPK_Seed_A_full_system_level_thermal_20260910.mdat)
contains the intended nominal `0.5/1/2/4 V RMS` traces. The exact shorter
measurement names, trace identities, source hash, comparison method, and
distortion samples are in the [owning
qualification](rew/qualification/SEED_A_FULL_SYSTEM_LEVEL_AND_THERMAL_QUALIFICATION_2026-09-10.md).

Both interface channels retained at least `27.9 dB` headroom and all intended
sweeps completed without a reported warning or audible anomaly. Sampled
distortion passes the project limits. Nominal-voltage normalisation shows no
broad compression above `0.5 dB`; a narrow `4 V` versus `2 V` difference of
about `-1.28 dB` near `2.18 kHz` is retained for speaker-two confirmation.
R(Tser) and L(W1) surface rises during the 15-minute nominal `2 V RMS`
CTA-2034 exposure were only `0.4` and `0.2 degrees C`, respectively, and
both were stable over the final five minutes.

The post-thermal trace is excluded from all acoustic conclusions because the
speaker was inadvertently at `60 degrees`. The user has explicitly waived an
immediate repeat on proportionality grounds. A correct hot `0-degree`
comparison is required on speaker two; repeat speaker one only if that test
reveals an anomaly.
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

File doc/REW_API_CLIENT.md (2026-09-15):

# REW API Client

| State | Value |
| --- | --- |
| Lifecycle | **CURRENT STATUS AND SNAPSHOT ROUTER** |
| Owns | Current REW API reachability, status/snapshot operation, and routing |
| Does not own | `.mdat` extraction semantics, workspace safeguards, output reconstruction, or detailed qualification evidence |
| Validation record | [REW API client validation](rew/qualification/REW_API_CLIENT_VALIDATION.md) |
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

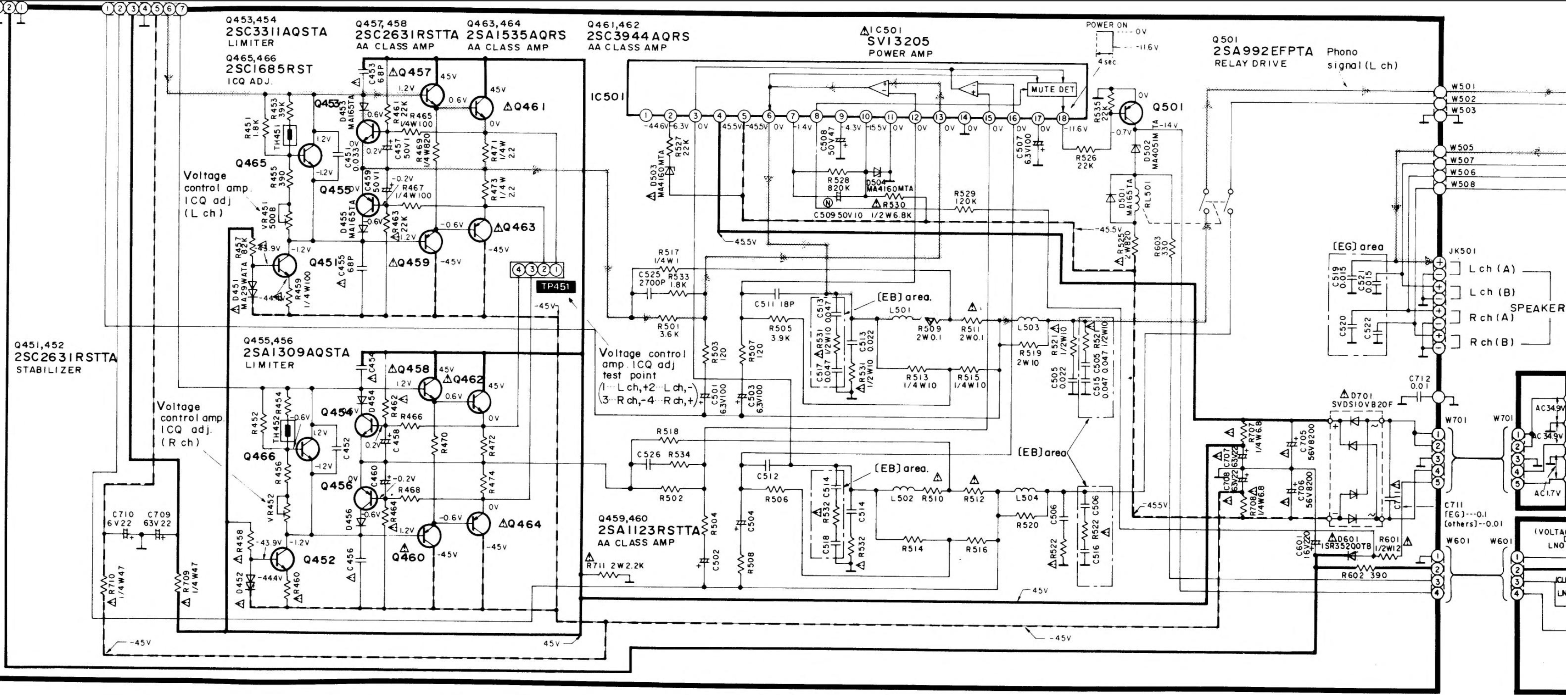
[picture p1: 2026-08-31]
rew/SU-V570_power_amp_output_schematic.png

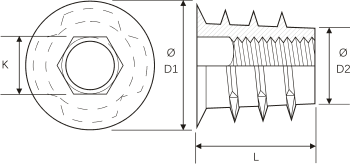
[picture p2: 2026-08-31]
type_d_dimension_reference.png

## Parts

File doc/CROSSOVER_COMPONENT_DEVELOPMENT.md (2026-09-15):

# Crossover Component Development

> - **Lifecycle:** ACTIVE COMPONENT-DEVELOPMENT AUTHORITY
> - **Owns:** current measured component banks, inductor construction and measurement, resistor-bank topology, second-network matching, thermal/mechanical rules
> - **Does not own:** acoustic targets, driver evidence, measurement procedures, or pre-build stock-selection arithmetic
> - **Read when:** procuring, winding, matching, laying out, or building the crossover
> - **Current decision:** Seed A's measured external component set passes; match speaker two to its completed values, then validate the new network acoustically and electrically
> - **Next gate:** recount/procure parts, build the second measured network, and retain both networks externally through pair evidence
> - **Limitations:** holdings have not been recounted; measurements are user-reported; AADE inductance frequency and signed DCR measurement pairs for completed coils are unavailable; PCB/manufacturing release is unqualified; surface temperatures do not reveal winding or voice-coil temperature
> - **As of:** 2026-09-15

The [component-build evidence](history/CROSSOVER_COMPONENT_BUILD_EVIDENCE_2026-09-07_TO_08.md)
holds superseded stock inventories, sample readings, arithmetic, donor-coil
estimates, and reverse-polarity DCR pairs. It is for audit, not routine work.
The active acoustic authority is [CROSSOVER_DESIGN.md](CROSSOVER_DESIGN.md).

## 1. Development rules

- Measure, label, and model every component used.
- Keep substitutions reversible and inductor taps accessible.
- Treat nominal values and winding turns as starting points; direct measurement
  is the acceptance criterion.
- Validate restraint, spacing, temperature, and complete as-built load before
  internal mounting.

## 2. Current Seed A component set

The current practical values are measured completed banks and coils, not sums of
individual samples or winding estimates.

| Part | Completed value | Construction / consequence |
|---|---:|---|
| C(W1) | `17.96 uF`, `0.04 ohm` ESR | within `-0.222%` of `18.0 uF` |
| C(T1) | `12.22 uF`, `0.04 ohm` ESR | within `+0.164%` of `12.2 uF` |
| C(T2) | `22.59 uF`, `0.04 ohm` ESR | within `+0.400%` of `22.5 uF` |
| L(W1) | `724 uH`, `0.292 ohm` DCR | 167 turns, `1.8 mm` ECW |
| L(W2) | `111 uH`, `0.172 ohm` DCR | 78 turns, `1.8 mm` ECW |
| L(T1) | `219 uH`, `0.193 ohm` DCR | 100 turns, `1.8 mm` ECW |
| R(Tser) | `1.401 ohm` | four selected 5R6 resistors in parallel |
| R(Tpar) | `39.032 ohm` | three selected 13R resistors in series |

All reactive values are within `+/-1%` of their Seed A targets. Model these
actual values and parasitics; do not unwind, add turns, trim, or dismantle a
completed bank solely to improve nominal agreement.

## 3. Capacitors

Use polypropylene film capacitors, normally `10%` tolerance and sensible
`100-250 VDC` or higher rating. Measure and label every part before use;
parallel only within its named isolated bank, then measure the completed bank
and enter that value and ESR in the model. The direct reading supersedes
component arithmetic.

For speaker two, recount labelled stock and procure/select a new measured set.
Match the three completed Seed A totals above as closely as practical; `+/-1%`
is preferred and up to `+/-2%` is acceptable for the reversible prototype
after modelling actual values. Check final pad size and lead pitch against
selected physical parts. Do not infer remaining holdings from the 2026-09-07
stock report.

## 4. Inductors

Use air-core coils, actual measured DCR, large-gauge round wire, and physically
separated/approximately orthogonal placement. Foil/ribbon is optional.

### 4.1 Measurement and second-network acceptance

Measure loose coils away from metal and conductive loops at a consistent,
recorded frequency. The reported Seed A method used a PL310QMD at `1 V` with a
`25 mA` limit, a `47 ohm`, `0.5 W` ballast, U1272A current measurement,
and U1282A voltage probes directly across cleaned coil terminals. Reverse
current and voltage without moving those probes and calculate:

```text
R = (Vforward - Vreverse) / (Iforward - Ireverse).
```

The signed-pair subtraction rejects a fixed thermal-EMF/meter offset. For
completed Seed A coils, already-derived DCR is accepted even though signed pairs
were not retained. AADE L/C Meter IIB was nulled before each inductance reading;
its frequency is unknown.

For speaker two, reproduce measured Seed A inductances and DCRs from
measurement, not turn count. Secure incomplete outer layers, retain access to
development taps, keep inductors separated and approximately orthogonal, and
measure the installed network because residual mutual coupling can alter
effective inductance.

### 4.2 Former and layout rules

The current common-former baseline is `1.8 mm` solderable ECW, maximum
outermost-winding OD `70 mm`, `30 mm` wire-bearing barrel OD, and `39 mm`
clear axial length. Inner layers are close-wound; only the outermost may be
incomplete and axial spacers are not used. Use the retained [3D-printed
crossover-coil models](3d_models/Crossover_Coils/README.md) and an ABS former
printed with suitable enclosed-printer ventilation.

## 5. Resistors, thermal, and PCB rules

R(Tser) is four parallel parts and R(Tpar) is three parts in **series**. Do not
copy the old all-parallel L-pad footprint. Match completed Seed A values for
speaker two.

Use one qualified family of flameproof `5 W` parts where practical, at least
`5 mm` body clearance, ventilation, and verified body dimensions, lead
diameter/pitch, mounting, derating, and a second source before manufacturing
release. The exposed Seed A prototype passed a 15-minute nominal `2 V RMS`
CTA-2034 surface check: R(Tser) rose `20.4` to `20.8 degrees C`; L(W1) rose
`20.4` to `20.6 degrees C`; neither rose in the final five minutes. This
does not qualify a different part family or enclosed PCB.

## 6. Completed assembly consequence

Seed A passed coherent point-to-point cold topology checks. With drivers and
the powered-down amplifier connected in verified polarity, input resistance was
`5.929 ohm`; subtracting woofer-filter DCR gives
`5.929 - (0.292 + 0.172) = 5.465 ohm`, consistent with installed woofer
evidence. Powered idle and an initial `0.10 V RMS`, `200-20000 Hz`
commissioning sweep were normal. Detailed commissioning is in the [Seed A
commissioning history](rew/history/SEED_A_EXTERNAL_CROSSOVER_COMMISSIONING_2026-09-08_TO_09.md).

Measured values feed the practical model in [CROSSOVER_DESIGN.md](CROSSOVER_DESIGN.md).
The component, acoustic, load/EPDR, and bounded level/thermal gates pass; retain
the network externally until speaker-two matching and final mounting decisions
are supported by evidence.

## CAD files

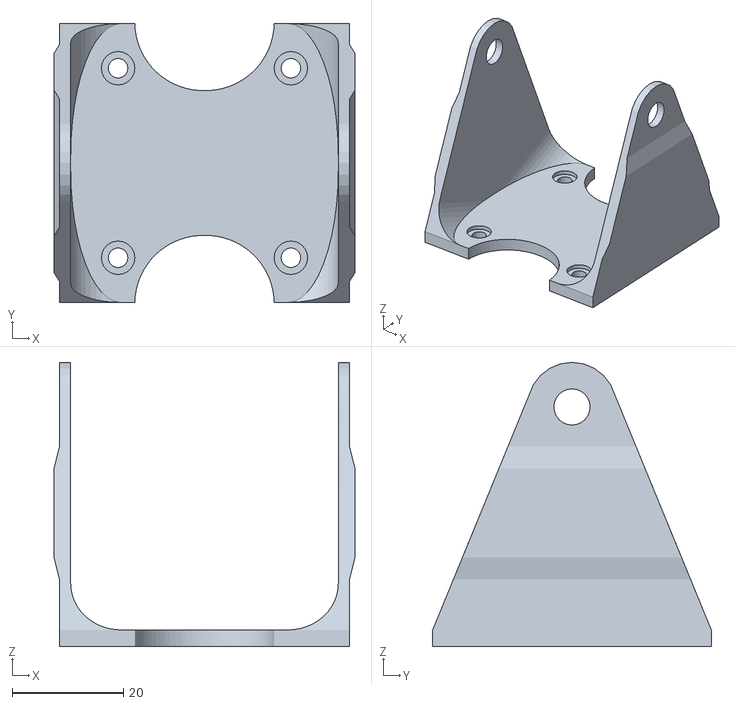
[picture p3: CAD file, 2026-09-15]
3d_models/Crossover coils/Crossover coil bracket B.stl
54.0 x 50.0 x 51.0

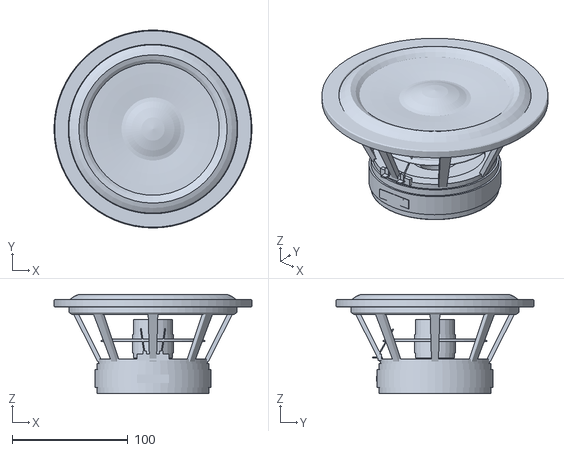
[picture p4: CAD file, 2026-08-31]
3d_models/SB_Acoustics_SB17NRX2C35-8/SB_Acoustics_SB17NRX2C35-8.stl
171.0 x 171.0 x 85.9

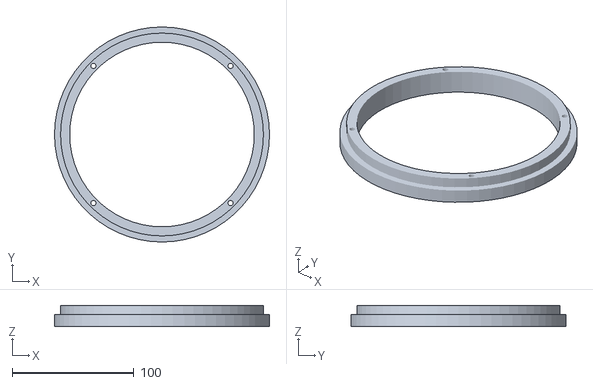
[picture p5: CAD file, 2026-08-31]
3d_models/Woofer inner ring template.stl
176.3 x 176.3 x 17.5

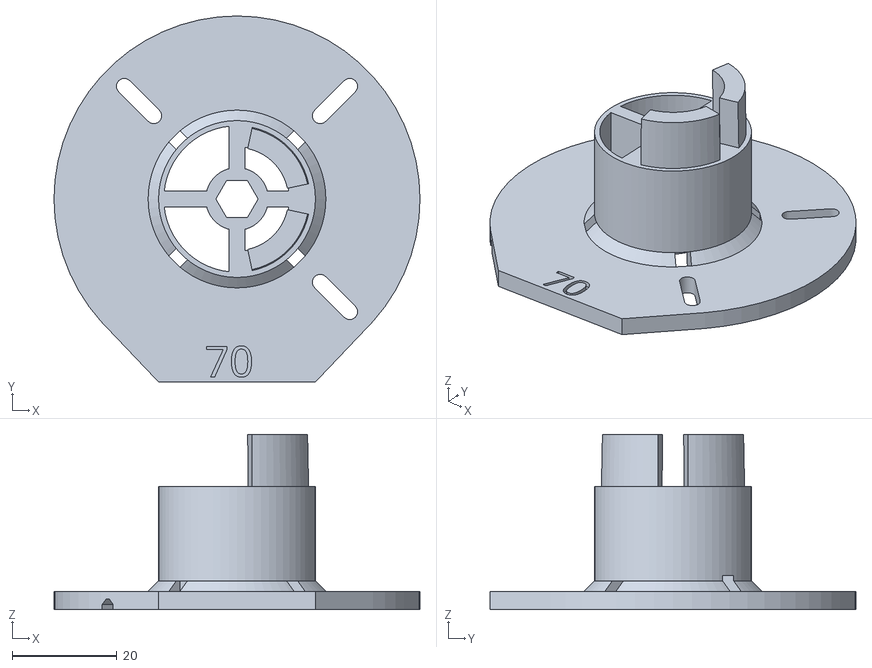
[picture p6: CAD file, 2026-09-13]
3d_models/Crossover coils/Crossover coil former 70mm.stl
70.0 x 70.0 x 33.5

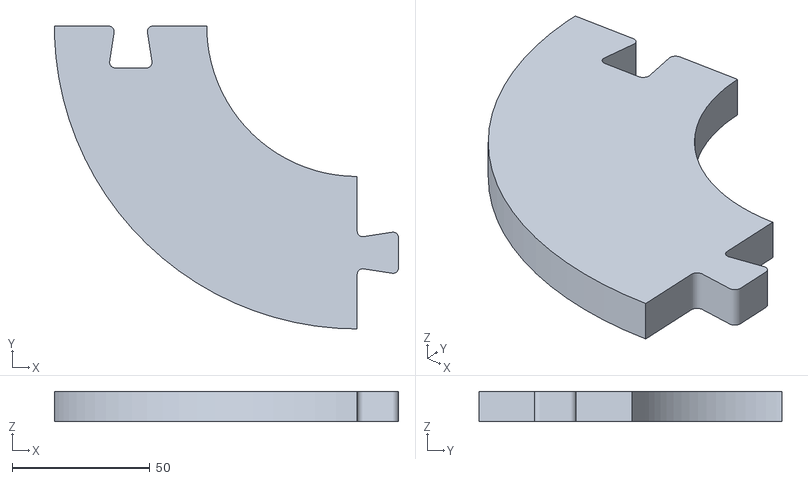
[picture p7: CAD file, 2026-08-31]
3d_models/Tweeter outer template segment.stl
124.9 x 110.0 x 11.0

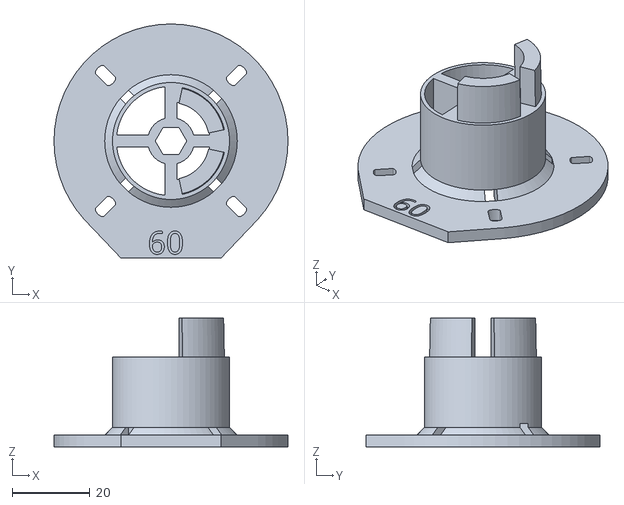
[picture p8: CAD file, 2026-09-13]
3d_models/Crossover coils/Crossover coil former 60mm.stl
60.0 x 60.0 x 33.0

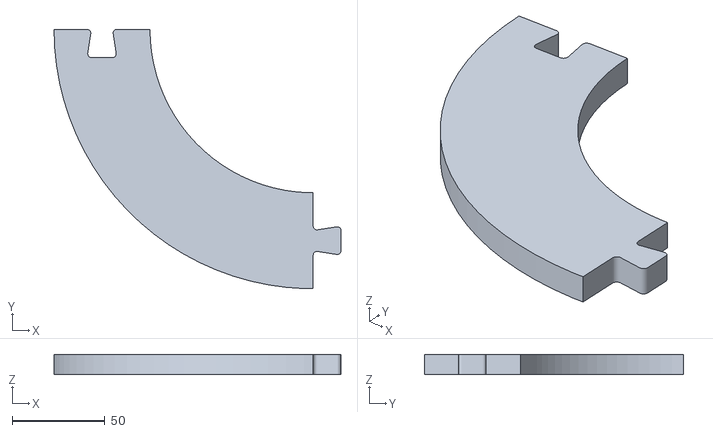
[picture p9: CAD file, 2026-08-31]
3d_models/Woofer outer template segment.stl
155.0 x 140.0 x 11.0

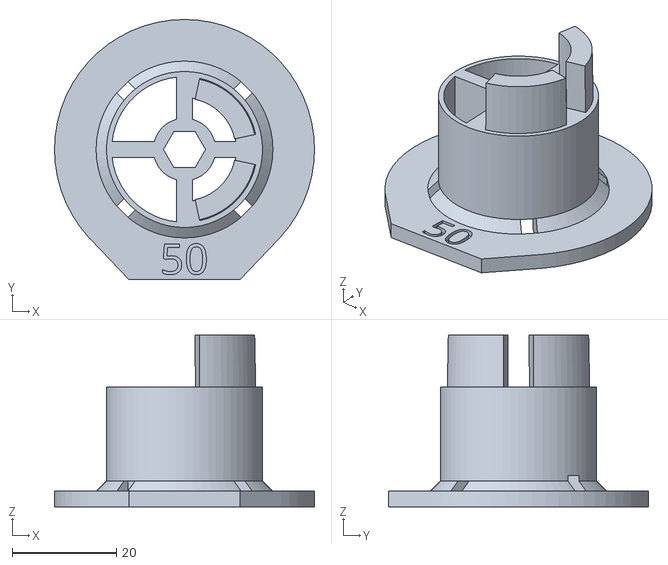
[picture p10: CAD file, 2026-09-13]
3d_models/Crossover coils/Crossover coil former 50mm.stl
50.0 x 50.0 x 33.0

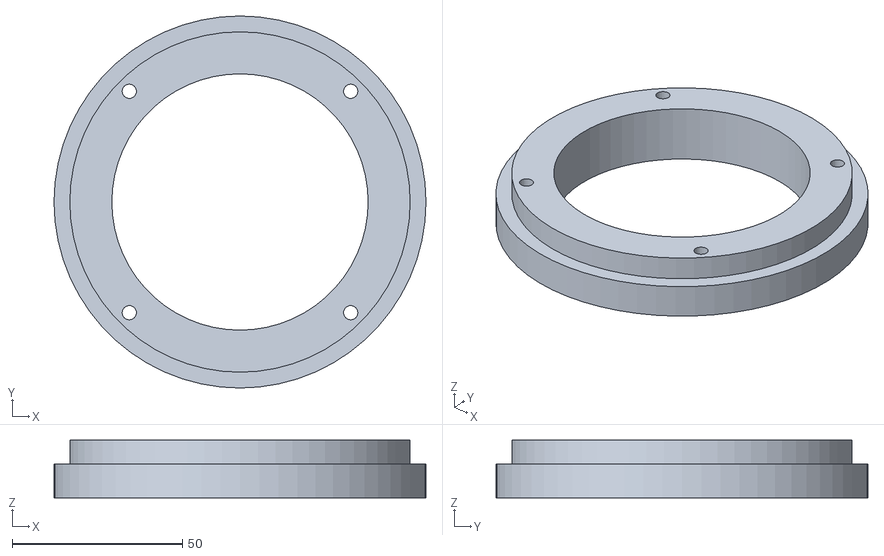
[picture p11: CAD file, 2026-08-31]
3d_models/Tweeter inner ring template.stl
109.3 x 109.3 x 17.0

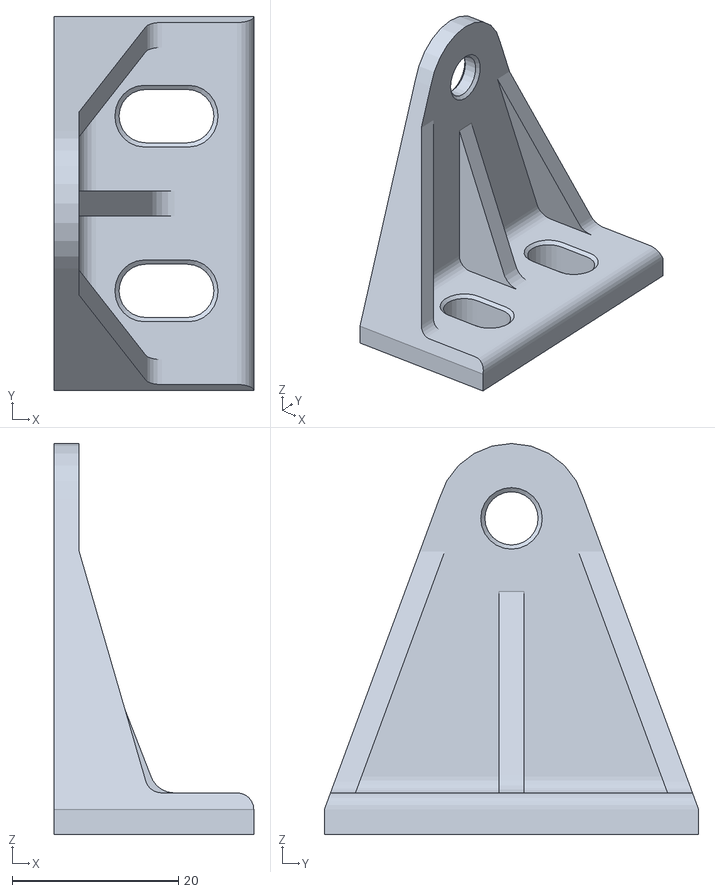
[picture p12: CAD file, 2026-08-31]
3d_models/Crossover coils/Crossover coil bracket 70mm.stl
24.0 x 45.0 x 47.0

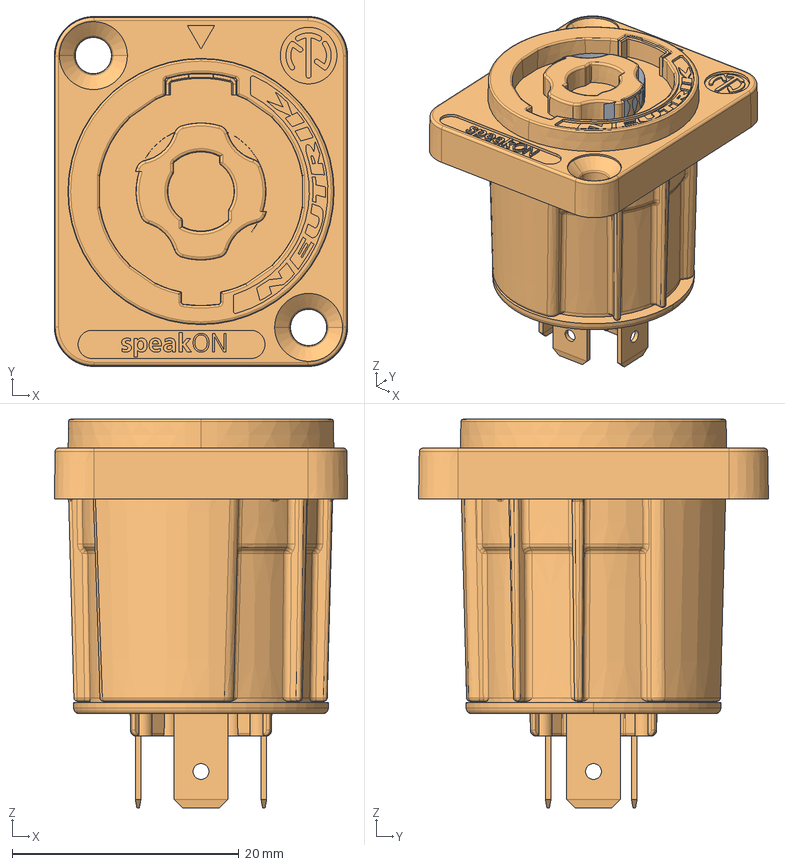
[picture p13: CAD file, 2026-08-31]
3d_models/nl4mpxx.stp
25.9 x 30.9 x 34.3 mm

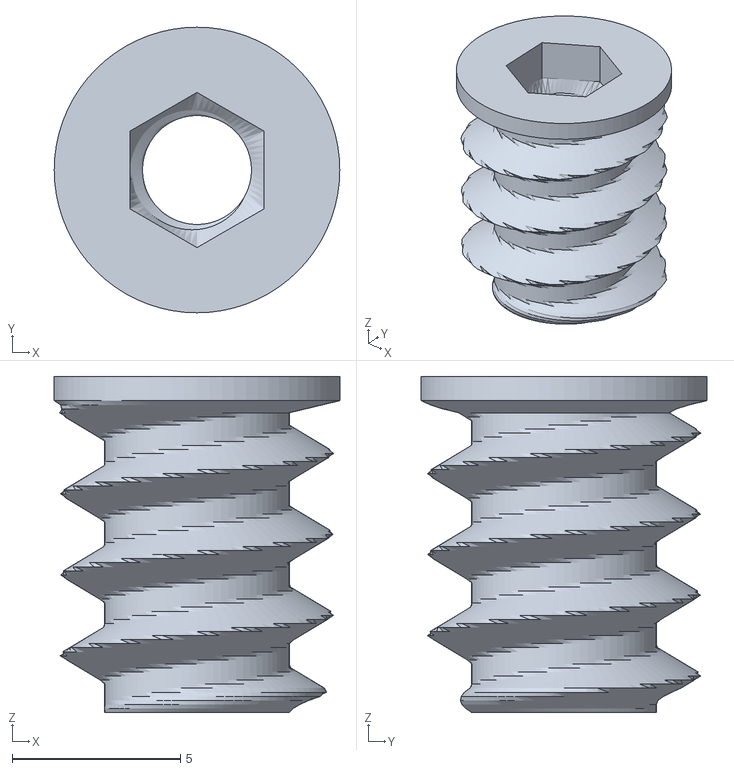
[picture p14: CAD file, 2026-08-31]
3d_models/M4x10_Type_D_Flanged_Threaded_Insert/M4x10_Type_D_Flanged_Threaded_Insert.stl
8.50 x 8.50 x 10.0

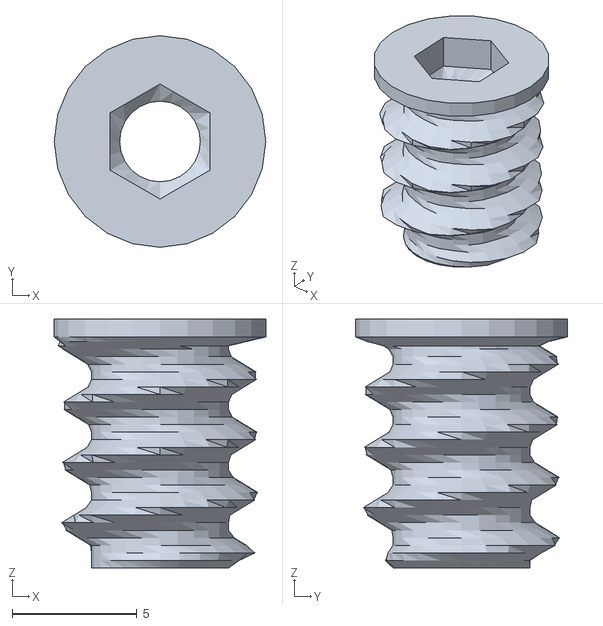
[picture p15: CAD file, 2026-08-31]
3d_models/M4x10_Type_D_Flanged_Threaded_Insert_LowPoly/M4x10_Type_D_Flanged_Threaded_Insert_LowPoly.stl
8.50 x 8.50 x 10.0

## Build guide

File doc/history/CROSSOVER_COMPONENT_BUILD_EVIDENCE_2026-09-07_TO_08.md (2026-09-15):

# Crossover Component Build Evidence - 2026-09-07 to 2026-09-08

> - **Lifecycle:** HISTORY / RETAINED COMPONENT-BUILD EVIDENCE
> - **Owns:** dated stock, sample selection, arithmetic, donor-coil estimates, and pre-build DCR readings
> - **Does not own:** active measured component specification or speaker-two procurement decision
> - **Read when:** auditing a completed Seed A value, historic material provenance, or selection arithmetic
> - **Current consequence:** use completed measurements in [Crossover component development](../CROSSOVER_COMPONENT_DEVELOPMENT.md)
> - **Last reviewed:** 2026-09-15

These user-reported dated records explain how Seed A was built. They do not
state present stock. Direct completed-bank and completed-coil readings supersede
all arithmetic and estimates below.

## 1. Capacitor stock and selection

On `2026-09-07`, reported definite-provenance holdings were four each of
`10 uF` TDK B32774H4106K000 (`450 VDC`) and `6.8 uF` Panasonic ECW-FJ60685J
(`600 VDC`), ten each of `2.2 uF` ECW-FD2W225J, `1.0 uF` ECW-FD2W105JC,
`0.47 uF` ECW-FD2W474J (`450 VDC`), `0.22 uF` ECW-FD2W224KB, and
`0.10 uF` ECW-FD2W104KQ. The `2.2-10 uF` samples used a Peak Atlas ESR+;
smaller parts used an AADE L/C Meter IIB without ESR. Test frequency and
equivalent-circuit convention were not recorded. Lesser-provenance capacitors
were not selected.

The nominal banks were C(W1) `18.0 uF`, C(T1) `12.2 uF`, C(T2) `22.5 uF`.
Whole-network selection gave C(W1) `6.8-A + 6.8-C + 2.2-A + 2.2-C + 0.22-B =
17.9996 uF`; C(T1) `10-D + 2.2-J = 12.27 uF`; and C(T2) `10-B + 10-C +
2.2-D = 22.64 uF`. The `0.10 uF` trim was deliberately omitted. Completed
measurements were C(W1) `17.96 uF`, C(T1) `12.22 uF`, and C(T2) `22.59 uF`,
each `0.04 ohm` ESR; they are the active values.

The reported stock was sufficient for one channel, not a pair: six `10 uF`
parts would be needed but only four were reported before speaker one. Recount
rather than subtracting from this record for speaker two. For a parallel bank,
`Cbank = C1 + C2 + ...`; measure ESR directly rather than summing it. A useful
small-ESR check is `Rbank approximately equals sum(Ri * Ci^2) / (sum(Ci))^2`.

## 2. Donor coils, estimates, and pre-build DCR

Available finished coils were reported as `1.2 mH`, 215 turns, `1.8 mm` ECW;
`902 uH`, 195 turns, `1.4 mm`; `550 uH`, 170 turns, `1.4 mm`; and
`207 uH`, 97 turns, `1.8 mm`. The first and last were approved donors, while
the two `1.4 mm` coils remained spares. An empirical `L = k N^p` estimate
from the `1.8 mm` observations gave `p = 2.21`; it suggested about 171 turns
for `0.72 mH`, 73 for `0.11 mH`, and 100 for `0.22 mH`. The `1.4 mm` pair
produced an implausible local exponent `3.61`, so its earlier 79-turn estimate
was withdrawn. The meter, not the estimate, was the stopping rule.

The polarity-reversed four-point method used a `1 V`, `25 mA`-limited
PL310QMD, `47 ohm` ballast, U1272A current measurement, and U1282A coil
voltage. Results were `0.33470 ohm` (550 uH), `0.42174 ohm` (902 uH),
`0.18812 ohm` (207 uH), and `0.36476 ohm` (1.2 mH). The raw signed I/V
pairs and illustrative `0.30/0.13/0.19 ohm` sensitivity tuple are dated
planning evidence only; complete-coil DCRs `0.292/0.172/0.193 ohm` for
L(W1)/L(W2)/L(T1) supersede them.

## 3. Resistor stock and selection

Dated definite-provenance stock was ten each of `3.6`, `4.7`, `5.1`,
`5.6`, `6.8`, `7.5`, `8.2`, `9.1`, `10`, `11`, `13`, `15`,
`18`, and `22 ohm` `5 W` metal-oxide resistors. Lower-power E24 and mixed
lesser-provenance stock were not selected. Nominal construction was four
`5.6 ohm` parts in parallel for `1.400 ohm` R(Tser), and three `13 ohm`
parts in series for `39.0 ohm` R(Tpar). At a conservative `20 W` pad case
this corresponded to about `6.0 W` and `1.2 W` bank dissipation.

The U1282A was lead-nulled on the `60 ohm` range. Selected 5R6 E/F/I/J gave a
calculated `1.391494 ohm`; 13R B/D/E summed to `39.000 ohm`. Completed banks
measured `1.401 ohm` and `39.032 ohm`; these supersede sample arithmetic.
R(Tpar) is a series string, so early all-parallel L-pad footprints are invalid.

## 4. Detailed sample readings retained from the build record

The unit readings below are user-reported. They are retained to reconstruct the
dated whole-network selection, not to select a second network.

### 4.1 Capacitor samples

| Sample | Measured capacitance | Measured ESR |
|---|---:|---:|
| 10-A | 10.43 uF | 0.08 ohm |
| 10-B | 10.16 uF | 0.09 ohm |
| 10-C | 10.32 uF | 0.08 ohm |
| 10-D | 10.13 uF | 0.07 ohm |
| 6.8-A | 6.72 uF | 0.08 ohm |
| 6.8-B | 6.60 uF | 0.08 ohm |
| 6.8-C | 6.70 uF | 0.08 ohm |
| 6.8-D | 6.69 uF | 0.08 ohm |
| 2.2-A | 2.19 uF | 0.07 ohm |
| 2.2-B | 2.21 uF | 0.06 ohm |
| 2.2-C | 2.17 uF | 0.06 ohm |
| 2.2-D | 2.16 uF | 0.06 ohm |
| 2.2-E | 2.21 uF | 0.06 ohm |
| 2.2-F | 2.17 uF | 0.06 ohm |
| 2.2-G | 2.16 uF | 0.06 ohm |
| 2.2-H | 2.20 uF | 0.06 ohm |
| 2.2-I | 2.20 uF | 0.07 ohm |
| 2.2-J | 2.14 uF | 0.06 ohm |
| 0.22-A | 0.2214 uF | not available |
| 0.22-B | 0.2196 uF | not available |
| 0.22-C | 0.2167 uF | not available |
| 0.22-D | 0.2240 uF | not available |
| 0.10-A | 0.0993 uF | not available |
| 0.10-B | 0.1019 uF | not available |
| 0.10-C | 0.0983 uF | not available |
| 0.10-D | 0.0989 uF | not available |

### 4.2 Pre-build reverse-polarity DCR pairs

| Coil | Forward I / V | Reverse I / V | Derived DCR |
|---|---:|---:|---:|
| 550 uH, 170 turns, 1.4 mm | 19.888 mA / 6.659 mV | -19.870 mA / -6.648 mV | 0.33470 ohm |
| 902 uH, 195 turns, 1.4 mm | 19.703 mA / 8.317 mV | -19.843 mA / -8.361 mV | 0.42174 ohm |
| 207 uH, 97 turns, 1.8 mm | 19.800 mA / 3.727 mV | -20.041 mA / -3.768 mV | 0.18812 ohm |
| 1.2 mH, 215 turns, 1.8 mm | 19.934 mA / 7.274 mV | -19.928 mA / -7.266 mV | 0.36476 ohm |

The derivation is `R = (Vforward - Vreverse) / (Iforward - Ireverse)`.
For the 550 uH coil, `13.307 mV / 39.758 mA = 0.33470 ohm`; millivolts
divided by milliamperes give ohms. The near agreement of forward and reverse
ratios did not suggest a material polarity-dependent offset.

### 4.3 Resistor sample readings and selection

| Sample | 5.6 ohm population | 13 ohm population |
|---|---:|---:|
| A | 5.535 ohm | 12.898 ohm |
| B | 5.398 ohm | 13.034 ohm |
| C | 5.543 ohm | 12.924 ohm |
| D | 5.543 ohm | 12.986 ohm |
| E | 5.559 ohm | 12.980 ohm |
| F | 5.584 ohm | 12.999 ohm |
| G | 5.520 ohm | 12.878 ohm |
| H | 5.527 ohm | 12.925 ohm |
| I | 5.554 ohm | 12.919 ohm |
| J | 5.567 ohm | 12.881 ohm |

| Seed A part | Selected samples | Calculated value | Error from target |
|---|---|---:|---:|
| R(Tser) | 5R6-E / F / I / J in parallel | 1.391494 ohm | -0.008506 ohm; -0.608% |
| R(Tpar) | 13R-B + D + E in series | 39.000 ohm | 0.000 ohm; 0.000% |

The four highest measured 5R6 parts gave the closest parallel bank because
every sample was below its marking. At the conservative 6 W bank case, the
predicted individual powers were 1.502, 1.495, 1.503, and 1.500 W; the 1.2 W
R(Tpar) string divided to about 0.401, 0.400, and 0.399 W.

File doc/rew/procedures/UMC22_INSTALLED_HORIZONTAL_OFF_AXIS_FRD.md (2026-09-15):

# UMC22 Installed Horizontal Off-Axis FRD Runbook

> - **Lifecycle:** COMPLETED PROCEDURE / SAFE REPEAT ROUTE
> - **Owns:** a bounded positive-horizontal raw-driver repeat series
> - **Does not own:** source-release evidence, a full polar specification, or crossover decisions
> - **Read when:** deliberately repeating the sparse polar route after a material change or on speaker two
> - **Current approved action:** preserve the verified source families; no unchanged speaker-one repeat
> - **Next gate:** matched speaker-two raw-driver and Seed A validation
> - **Limitations:** positive side only at `20 degree` spacing; inferred symmetry; woofer use `1.5-5 kHz`, protected-tweeter use `1.5-12 kHz`
> - **Last reviewed:** 2026-09-15

The completed raw sources, UUIDs, hashes, windows, releases, and known filing
corrections are in the audit-only [installed-driver acoustic-source
qualification](../qualification/INSTALLED_DRIVER_ACOUSTIC_SOURCES_2026-09-06_TO_07.md).
This runbook releases no signal by itself.

## 1. Geometry And Scope

The smallest directivity discriminator is the existing `0 degree` source plus
`+20`, `+40`, and `+60 degree` captures for each raw driver. It is not a full
polar set. Do not infer negative-side, vertical, 10-degree, or laboratory-grade
behaviour from it.

At `0 degree`, centre the baffle over the jig's vertical rotation axis in the
baffle plane. Positive means anti-clockwise viewed from above. Keep the
microphone fixed at tweeter-centre height and `1.000 m` from the baffle-plane
pivot; do not move, swing, or re-aim it as the cabinet rotates. Secure the
cabinet at every mark.

## 2. Common No-Excitation Audit

Use the qualified UMC22 settings: V5.40 beta 133, Java `Stereo only`, exact
exclusive UMC22 input/output, `48 kHz`, L/L/L/R, loopback as calibration and
timing reference, loopback IR merge off, timing offset `0.0000 ms`, and
`ECM8000_calibration_data.csv` on microphone L only. Prepare each named sweep
at `20-20000 Hz`, `-20 dBFS`, `256k`, one repetition, with clipping abort
enabled. Keep Generator and other application audio stopped except for an
explicitly approved Measure action.

At the start of a day or after a material electrical, power, endpoint, geometry,
or anomaly change, obtain one current confirmation of normal silent operation,
secure microphone/jig, and relevant driver topology. Use a read-only REW API
snapshot when available only to corroborate software state.

## 3. Woofer Batch

Connect the woofer alone through NL4 `1+`/`1-`, with the qualified
clamp/attenuator directly across it to `INST 2`; keep the tweeter and protection
capacitor out of circuit. Before power-up confirm plausible resistance at the
measurement plane, no strain/short, and the U1282A in high-impedance voltage
mode if used. Use the safe startup and stop rules in the
[woofer runbook](UMC22_INSTALLED_WOOFER_FRD.md).

With Generator stopped, rotate and secure at `+20`, `+40`, then `+60 degrees`.
Run only the explicitly approved named sweep at each angle. Between sweeps check
the angle mark, security, fixed microphone/jig, silence, and any anomaly. Save
only the three new measurements to a fresh raw archive; never include retained
on-axis sources or API-loaded duplicates.

## 4. Protected-Tweeter Batch

A woofer-to-tweeter change is a topology change. With signals stopped, lower
volume, switch the amplifier off, disconnect woofer feed, restore the measured
`10.13 uF`, `0.08 ohm` ESR protection capacitor, and connect the fixture across
the tweeter after it through NL4 `2+`/`2-`. Recheck the protection topology and
perform a new no-excitation audit after power-up. Use the safe startup and stop
rules in the [tweeter runbook](UMC22_INSTALLED_TWEETER_FRD.md).

Run only the approved `+20/+40/+60 degree` titles, retaining exactly the three
new measurements in a fresh raw archive. The protected-tweeter model scale
remains `+11.14 dB` magnitude only.

## 5. Review, Export, And Stop Rules

Do not export before signal-free review under [FRD measurement method](../FRD_MEASUREMENT_METHOD.md).
Verify each title/identity, native unsmoothed grid, loopback timing, direct
arrival, first material reflection, and REW-native window. Do not align peaks,
apply an IR shift, or overwrite the phase-bearing on-axis design FRD.

Use the established polar windows: woofer `Hann 2.0 ms` left / `Tukey 0.25
3.5 ms` right; protected tweeter `Hann 2.0 ms` left / `Tukey 0.25 1.5 ms`
right; each at its own exact direct peak, FDW/MTW off. Export under the separate
per-driver `polar/` subdirectory and interpret only the stated bands.

Stop, de-energise safely, and retain the failed measurement for any clipping,
REW warning, dropout, abnormal sound, instability, heat, smell, smoke, spark,
tingle, cabinet/jig/microphone movement, loose cable, or other anomaly. A
failed angle stops the rest of that batch pending review.

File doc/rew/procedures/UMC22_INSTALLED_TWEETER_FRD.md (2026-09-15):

# UMC22 Installed-Protected-Tweeter FRD Runbook

> - **Lifecycle:** COMPLETED PROCEDURE / SAFE REPEAT ROUTE
> - **Owns:** the safe, bounded UMC22 route for a deliberately repeated protected-tweeter capture
> - **Does not own:** source-release evidence, historic capture results, or crossover decisions
> - **Read when:** deliberately repeating the protected route after a material change or on speaker two
> - **Current approved action:** preserve the released sources; no unchanged speaker-one repeat
> - **Next gate:** matched speaker-two raw-driver capture and validation
> - **Limitations:** protection is a measurement safeguard, not a listening crossover; microphone calibration is not absolute SPL
> - **Last reviewed:** 2026-09-15

The approved C2 source, `+11.14 dB` modelling scale, raw-file identities,
hashes, UUIDs, and source-release checks are in the audit-only
[installed-driver acoustic-source qualification](../qualification/INSTALLED_DRIVER_ACOUSTIC_SOURCES_2026-09-06_TO_07.md).
This runbook releases no signal by itself.

## 1. Scope And Protection

Use only the qualified UMC22, SU-V570, ECM8000, and reference fixture route
with the installed SB26 tweeter. The measured `10.13 uF`, `0.08 ohm` ESR series
capacitor must remain in the tweeter-positive path. Connect the qualified
clamp/attenuator directly across the tweeter after that capacitor through NL4
`2+`/`2-`; never connect the amplifier directly to `INST 2`.

The capacitor protects the tweeter during raw measurement. Its post-capacitor
reference leaves the established `+11.14 dB` magnitude-only VituixCAD scale;
apply no extra phase, delay, polarity, smoothing, or minimum-phase correction.

## 2. Required Geometry And Route

Use the fixed microphone at tweeter-axis height, `1.000 m` from the baffle-plane
pivot, aimed at the cabinet. Secure the cabinet and microphone. Preserve
measured timing; do not add a geometric delay. The electrical and UMC22 controls
are the qualified settings in the [woofer runbook](UMC22_INSTALLED_WOOFER_FRD.md#2-required-unchanged-route).

Before a changed-route startup, stop all audio, set volume down, switch the
amplifier off, disconnect USB and phantom, then inspect the capacitor, wiring,
terminals, strain relief, insulation, and fixture. Before power-up confirm
plausible resistance across the tweeter/reference plane, a capacitor-charging
rise toward open circuit on the amplifier side, and no short, capacitor bypass,
loose connection, or exposed conductor. Connect ECM8000 before phantom, then
start at minimum volume. Stop for abnormal sound, hum, transient, clipping,
instability, heat, smell, or smoke.

## 3. No-Excitation Audit

At the start of a new measurement day or after a power, wiring, endpoint,
geometry, or anomaly change, obtain one current report that the protected route
is connected, the speaker and microphone are secure, and idle operation is
silent and normal. With Generator, Check Levels, Measure, and all other audio
stopped, verify the exact UMC22 endpoints, Java `Stereo only`, `48 kHz`,
L/L/L/R routing, loopback calibration/timing, loopback IR merge off, timing
offset `0.0000 ms`, `ECM8000_calibration_data.csv` on L only, no microphone
calibration on reference R, clips off, and no abnormal condition.

Prepare only an explicitly approved title and one `20-20000 Hz`, `-20 dBFS`,
`256k`, clipping-abort-enabled sweep. Use the read-only REW API snapshot where
available as corroboration, never as proof of physical wiring or geometry.

## 4. Capture, Retention, And Stop Rules

Run only the approved sweep while monitoring both input levels and hardware
clips. Record headrooms, warnings/anomalies, calibration and routing,
timing-reference index, System Delay, IR start, timing offset, clock adjustment,
SNR, and signal-to-distortion. Save raw `.mdat` before signal-free review.

Stop, de-energise safely, and retain a failed capture as diagnostic evidence
for clipping, a REW warning, dropout, unusual sound, rubbing, instability,
heat, smell, smoke, spark, tingle, movement, loose cable, or any anomaly. One
failed capture stops the remaining batch pending review.

Use [FRD measurement method](../FRD_MEASUREMENT_METHOD.md) for source review,
windowing, and export. Keep the `.mdat` authoritative; do not save API-loaded
duplicate measurements into it.

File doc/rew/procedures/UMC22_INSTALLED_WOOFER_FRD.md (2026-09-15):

# UMC22 Installed-Woofer FRD Runbook

> - **Lifecycle:** COMPLETED PROCEDURE / SAFE REPEAT ROUTE
> - **Owns:** the safe, bounded UMC22 route for a deliberate installed-woofer repeat
> - **Does not own:** source-release evidence, historical capture results, or crossover decisions
> - **Read when:** deliberately repeating the route after a material change or on speaker two
> - **Current approved action:** preserve the released sources; no unchanged speaker-one repeat
> - **Next gate:** matched speaker-two raw-driver capture and validation
> - **Limitations:** the UMC22/fixture route is interface-specific; generic microphone calibration is not absolute SPL
> - **Last reviewed:** 2026-09-15

The approved C6, C5, and TW1 sources, their hashes and UUIDs, and every dated
capture result are in the audit-only [installed-driver acoustic-source
qualification](../qualification/INSTALLED_DRIVER_ACOUSTIC_SOURCES_2026-09-06_TO_07.md).
This runbook releases no signal by itself.

## 1. Scope And Safety Boundary

Use only the qualified UMC22, SU-V570, ECM8000, and protected-reference route
for an installed SB17 woofer. Do not connect an amplifier output directly to
`INST 2`; use the qualified fixture under [fixture use](../fixtures/REFERENCE_FIXTURE_USE.md).
The accepted UMC22 fault risk does not waive checks that protect the person,
amplifier, speaker, PC, or source validity.

## 2. Required Unchanged Route

The released path is REW output L → UMC22 Output 1 → TS-to-RCA → SU-V570 AUX
left → speaker bank B left → woofer; the qualified clamp/attenuator is in
parallel at the woofer terminals and feeds `INST 2`; ECM8000 feeds Input 1 XLR.
Use only B-left, leave Output 2, headphones, and AUX right empty, and keep
`DIRECT MONITOR` off.

Use the established `1.000 m` geometry. For woofer-axis work, place the
microphone on the woofer axis; for a common-position source, place it on the
fixed tweeter axis and do not add a geometric delay. Secure the cabinet and
microphone. Close the window behind the microphone where practical.

Use the qualified controls: UMC22 `OUTPUT` fully clockwise, `GAIN 1` and
`GAIN 2` about 2 o'clock, phantom on only after the ECM8000 is connected,
SU-V570 AUX / tone defeat / loudness off / POWER AMP DIRECT off / B-left only /
`-38 dB` mark. Use the documented `1 kHz` tone only if a changed path requires
level restoration to `1.00 V RMS` across the woofer; stop the tone immediately.

## 3. Cold Start Or Changed-Route Check

For a disconnection, uncertain state, or material route change: stop all audio,
set volume down, switch the amplifier off, disconnect USB, turn phantom off,
and inspect fixture, terminals, insulation, restraint, woofer polarity, and
connector retention. Reconnect the released path, connect the ECM8000 before
phantom, then power the amplifier at minimum. Stop for exposed conductor,
loose/damaged connection, hum, transient, clipping, instability, heat, smell,
or smoke.

At the start of a new measurement day, after a relevant power-cycle,
reconnection, endpoint change, unattended setup interval, or anomaly, obtain
one current confirmation that power, wiring, geometry, and idle behaviour are
normal. If unchanged in an active package, keep the setup undisturbed.

## 4. No-Excitation Audit

With Generator, Check Levels, Measure, and all other application audio stopped,
confirm the following before preparing a named capture:

| Item | Required state |
| --- | --- |
| REW route | V5.40 beta 133, Java `Stereo only`, exact exclusive UMC22 input and output, `48 kHz` |
| Channel matrix | output L / timing output L / measurement input `MICROPHONE (Master Volume) L` / reference input `MICROPHONE (Master Volume) R` |
| Timing/calibration | loopback as calibration and timing reference; make calibration from loopback; IR merge off; timing offset `0.0000 ms` |
| Microphone calibration | `ECM8000_calibration_data.csv` on active L only; reference R has none |
| Physical state | clip indicators off; silent, stable system with no new heat, smell, or anomaly |
| Capture | actual-date `SB17-IW-<angle>-<position>-1m-U22-<YYMMDD>-C<next>`; `20-20000 Hz`, `-20 dBFS`, `256k`, one repetition, clipping abort enabled |

Use the read-only REW API status/snapshot when available as corroboration; it
cannot prove wiring or geometry. If REW recovery was required, reselect and
verify the exact endpoints, Stereo-only mode, L/L/L/R, input-volume `1.00`, and
per-input calibration. A shared UMC22 input is invalid.

## 5. Capture, Retention, And Stop Rules

After a specifically approved capture package, run only the named sweep while
watching both input levels and hardware clips. Record displayed headrooms,
warnings/anomalies, microphone and soundcard calibration, routing,
timing-reference index, System Delay, IR start, timing offset, clock adjustment,
SNR, and signal-to-distortion. Save raw `.mdat` before signal-free review.

Stop, de-energise safely, and preserve any failed capture as diagnostic evidence
for a REW warning, dropout, clipping, rubbing/buzzing, instability, unusual
heat, smell, smoke, spark, tingle, disturbed microphone/cabinet, loose cable,
or any other anomaly. Do not continue a package or modify a failed capture into
apparent validity.

Use [FRD measurement method](../FRD_MEASUREMENT_METHOD.md) for signal-free
impulse/ETC review, REW-native window selection, export, and naming. Retain the
`.mdat` as authority; selected API extraction may corroborate it, but API-loaded
duplicates must never be saved into a production archive.

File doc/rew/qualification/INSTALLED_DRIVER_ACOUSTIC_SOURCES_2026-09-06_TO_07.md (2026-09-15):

# Installed Driver Acoustic Sources — 2026-09-06 To 2026-09-07

> - **Lifecycle:** AUDIT-ONLY SOURCE QUALIFICATION
> - **Owns:** detailed raw acoustic-capture provenance, capture/release evidence, source identities, UUIDs, hashes, windows, raw and exported file checks, failed attempts, source-scale derivation, sparse-polar evidence, and source-filing corrections
> - **Does not own:** current driver conclusions, crossover decisions, live operation, or a generic measurement procedure
> - **Current authority:** [Driver analysis](../../DRIVER_ANALYSIS.md)
> - **Read when:** auditing or changing an approved source, diagnosing an anomaly, reproducing an export, or reviewing a failure; do not routinely load for modelling or capture preparation
> - **Approved release:** C6 woofer-axis; TW1/C2 common-position; protected-tweeter `+11.14 dB` VituixCAD magnitude correction; positive-side sparse woofer and protected-tweeter polar families
> - **Limitations:** one driver sample each; generic microphone calibration rather than absolute SPL; positive-side sparse polar only; local woofer early-tail variability near `2.03 kHz`; derived C2 scale; no inferred unmeasured angles
> - **Last reviewed:** 2026-09-15

This record moved the detailed source-release evidence out of the routinely read driver authority without discarding it. The current source manifest, applicability, and next gate remain in [Driver analysis](../../DRIVER_ANALYSIS.md).

## 1. Scope And Current Release

The released sources retain their original raw `.mdat` archives as authority. The exported FRDs are faithful native unsmoothed representations at the approved REW-native windows. Do not overwrite an archive or FRD; create a separately named source for a materially different capture or analysis state.

## 2. Detailed On-Axis, Common-Position, And Polar Evidence

### 2.1 Original detailed source-release evidence

C6 is the approved installed-woofer-axis source capture, with C5 as its
immediate repeatability witness. Its durable phase-bearing FRD is retained
below. TW1 and protected-tweeter C2 are the retained common-position sources
from the fixed tweeter-axis microphone point, so their relative phase and path
length represent one observation point. Both positive-side sparse raw polar
capture families now pass signal-free review; the protected-tweeter polar FRDs
and woofer polar FRDs are verified. This is a prototype-design release with
stated uncertainty, not a frozen production response.

**VERIFIED EXPORT — C6:**
[`rew/frd/SB17NRX2C35-8/000deg_1m_UMC22_2026-09-06.frd`](../../../rew/frd/SB17NRX2C35-8/000deg_1m_UMC22_2026-09-06.frd)
is the current crossover-input export. It is `913,746` bytes with SHA-256
`af3142aeff9dcd232ddb61878452c31afe5cae5446e4bd266b2e4e337488c1ca`.
Its header identifies REW V5.40 beta 133, C6's title, `-20.0 dBFS` `256k`
loopback-calibrated/timed capture, `3.1100 ms` delay, no smoothing, and a
nominal `500 Hz` start. It contains `31,404` finite frequency/magnitude/phase
rows from `499.877960` to `12000.000966 Hz` at the native approximately
`0.366211 Hz` spacing.

**DERIVED EXPORT VALIDATION:** a fresh signal-free API extraction selected C6
by UUID `1547767f-1781-4e51-b824-462b5a2788e1` from its authoritative
single-measurement `.mdat`, returned the expected source SHA-256 and stored
`Hann` `2.0 ms` left / `Tukey 0.25` `3.5 ms` right window at
`3.1100022059 ms`, with FDW/MTW off and no warning. Across all `31,404` export
rows, frequency differs from the native response by at most `0.000058 Hz`,
magnitude by `0.000508 dB`, and circular phase by `0.001508 degrees`. Those
differences are text precision only; the FRD is a faithful native unsmoothed
export of the approved capture.

**USER DECISION — EXPORT NAMING:** durable acoustic exports use
`rew/frd/<driver>/<AAA>deg_<distance>_<interface>_<date>.frd`, with a
three-digit zero-padded angle for useful filename sorting. Revisit the suffix
before adding multiple materially different datasets for the same driver and
angle; do not overwrite one dataset with another.

**VERIFIED MEASUREMENT / DERIVED REVIEW — COMMON-POSITION TW1 PASSED:** the
one authorised companion woofer sweep
`SB17-IW-0deg-1m-U22-260906-TW1` completed at `17:52:37` with UUID
`12568bef-2ec1-4cc7-be3a-91460b0659fa`. REW reports `48 kHz`,
`20.141602-19999.879 Hz`, direct peak/System Delay `3.1388593352 ms`, IR start
`3.0208333333 ms`, loopback-cal reference, zero timing offset/IR shift, zero
clock adjustment, and `42.75 dB` signal-to-noise. The user reported no warning,
clipping, or anomaly, minimum displayed headroom `8.8 dB`, and constant
reference-input figure `33.7 dB`. A post-capture GET-only snapshot found audio
ready, Generator stopped, no current error or blocking state, and the intended
`-20 dBFS`, `20-20000 Hz`, `256k`, one-repetition configuration. Earlier
warning-history entries predate TW1 and belong to the throwaway-instance event;
they are not TW1 warnings.

TW1 arrives `28.857 us` later than woofer-axis C6. The simple geometric
prediction for the reported `150 mm` rise at `1.000 m` baffle distance is
`32.616 us`, leaving only `-3.759 us` residual. A signal-free comparison applied
the same direct-sound support offline—`Hann` `2.0 ms` left and a one-sided
`Tukey 0.25` `3.5 ms` right approximation—to both raw impulses. At the nearest
native bin to `2.297 kHz`, TW1 is `-0.271 dB` relative to C6; circular phase is
`-22.12 degrees` before and `+1.74 degrees` after removing the measured delay.
The first stronger late-energy maximum is at approximately `3.60 ms` after the
direct peak, just beyond the proposed right-window end. This makes the common
REW-native `Hann 2.0 ms` / `Tukey 0.25 3.5 ms` window appropriate for TW1 on
its own impulse evidence. FDW/MTW remain off and the window reference is the
exact `3.1388593352 ms` direct arrival. The offline frequency comparison is a
review diagnostic, not the durable REW export.

**PROVISIONAL DESIGN RELEASE:** no repeat of TW1 is justified. Its timing,
impulse, headroom, metadata, and crossover-region response are coherent with
the intentional microphone move. Increasing attenuation above approximately
`5 kHz` is physically expected at the roughly `8.5-degree` vertical off-axis
woofer angle and did not constrain the then-proposed `2.2-2.4 kHz` crossover.
TW1's approved window, axis-qualified single-measurement `.mdat`, and validated
FRD are now retained without moving the geometry.

**VERIFIED FILE / LIVE WINDOW — TW1:**
[`rew/SB17NRX2C35-8_installed_000deg_tweeter-axis_1m_UMC22_2026-09-06.mdat`](../../../rew/SB17NRX2C35-8_installed_000deg_tweeter-axis_1m_UMC22_2026-09-06.mdat)
is `2,428,191` bytes with SHA-256
`78abfeec5c1efcfbba510785710cb35cdaa39a7e8d167fe88c1871f5e16928ef`.
A read-only API check of the live UUID found stored `Hann 2.0 ms` left /
`Tukey 0.25 3.5 ms` right windows, FDW/MTW off, at displayed reference
`3.140 ms`. That reference is only `1.141 us` later than the fitted
`3.138859 ms` peak—well below one `20.833 us` sample and equivalent to
approximately `0.95 degrees` at `2.30 kHz`—so its effect on gate placement is
immaterial.

**VERIFIED EXPORT — TW1:**
[`rew/frd/SB17NRX2C35-8/000deg_tweeter-axis_1m_UMC22_2026-09-06.frd`](../../../rew/frd/SB17NRX2C35-8/000deg_tweeter-axis_1m_UMC22_2026-09-06.frd)
is `913,085` bytes with SHA-256
`03923152b08c36e066cb0f9520c7a76489bf6837e3b85cd06c67af0c12a8e4b7`.
It contains `31,404` finite native unsmoothed magnitude/phase rows from
`499.877960` to `12000.000966 Hz`. A read-only UUID-selected API comparison
against the live response found maximum differences of `0.000009 Hz`,
`0.000513 dB`, and `0.001498 degrees` circular phase. These are text precision
only; the export faithfully preserves TW1 for common-position crossover work.

**VERIFIED MEASUREMENT — FIRST-CAPTURE REVIEW PASSED:** the first controlled production
candidate, `SB17-IW-0deg-1m-U22-260906-C1`, was captured on 2026-09-06 in REW
V5.40 beta 133 from `20-20000 Hz` using one `256k`, `-20.0 dBFS` sweep. Stored
Measurement Info identifies microphone input L, electrical timing-reference
input R, timing-reference output L, `ECM8000_calibration_data.csv`, loopback
soundcard calibration, `48 kHz`, System Delay `3.1241 ms`, IR start `3.0000 ms`,
timing-reference index `47,850.04`, zero timing offset and cumulative shift,
`0.0 ppm` clock adjustment, SNR `44.3 dB`, and signal-to-distortion `62.8 dB`.

**USER-REPORTED:** no physical or electrical change preceded the sweep; the
hardware clip indicators were off and the idle system was silent and normal.
No warning or anomaly occurred during the sweep, and both displayed headroom
indicators remained green throughout. The exact numeric headrooms were not
recorded.

**DERIVED HEADROOM BOUND:** REW defines green analogue-input measurement
headroom as `6-40 dB`, so the observation bounds both microphone-L and
reference-R headroom to that interval. It does not recover the exact values.
The stored SNR, signal-to-distortion result, absence of warnings, and bounded
headroom do not justify another signal solely to recover the missing digits.

**INFERRED FROM ETC AND GEOMETRY:** geometry predicts the earliest floor/ceiling
energy about `3.81 ms` after the direct arrival. The time-expanded ETC shows a
corresponding rise beginning near `6.9 ms` absolute time and a peak near
`7.1 ms`, roughly `27 dB` below the direct peak. Earlier decaying structure is
not uniquely separable from the bandwidth-limited woofer's direct response.

**VERIFIED APPLIED WINDOW / DERIVED:** the live REW measurement now has a
native `Hann` `2.0 ms` left window and `Tukey 0.25` `3.5 ms` right window,
referenced to the displayed `3.12 ms` direct peak, with frequency-dependent and
multi-time windowing off. REW reports `285.71 Hz` using the right-window width
and a total span of `264` samples. Independently, the `5.5 ms` total support has
nominal resolution

```text
Delta f approximately 1 / 0.0055 s = 182 Hz.
```

This ends the right window near `6.62 ms`, ahead of the first
geometry-consistent reflection. The windowed magnitude is coherent from its
REW limit through the crossover region and retains the woofer breakup structure
around `4-10 kHz`; the wrapped phase is continuous apart from ordinary
`+/-180 degree` wraps. **PROVISIONAL VALID RANGE:** use `500 Hz-12 kHz` for
driver/crossover work. This conservative range stays clear of the window's
`285.71 Hz` limit and excludes the steep, increasingly irregular upper-tail
response that is not needed for the intended crossover.

**VERIFIED FILE RETENTION:** the current C1/C2/C3R raw authority is
[`rew/SB17NRX2C35-8_installed_0deg_1m_UMC22_2026-09-06.mdat`](../../../rew/SB17NRX2C35-8_installed_0deg_1m_UMC22_2026-09-06.mdat),
`7,266,399` bytes, SHA-256
`d582c5d1fb7591689b3e4ef5491c1c578338f854fbe97c7d31124b529f0b516b`.
A post-save selected extraction loaded exactly C1, C2, and C3R, produced no
warning, and read back each trace's `Hann` `2.0 ms` left / `Tukey 0.25`
`3.5 ms` right native window with FDW/MTW off and its own direct-peak reference.
The failed C3 attempt is excluded and retained separately below.

**USER-REPORTED / VERIFIED MEASUREMENT — C2:** the user reported microphone-L
minimum headroom `10.6 dB`, reference-R headroom `33.1 dB`, and no warning or
anomaly. The API independently identifies loopback-timed C2 at `48 kHz` with
System Delay `3.1168 ms`, IR start `3.0000 ms`, zero timing offset and shift,
`0.0 ppm` clock adjustment, and SNR `38.74 dB`.

**VERIFIED WINDOW / DERIVED REPEATABILITY RESULT:** the API applied and read
back C1's production window shape and widths to C2, referenced to C2's direct
peak. From `1-5 kHz`, C1/C2 native unsmoothed maximum magnitude difference is
`1.754 dB`, RMS magnitude difference is `0.602 dB`, maximum circular phase
difference is `16.476 degrees`, and System Delay spread is `7.32 us`. This
fails the approximate `0.2 dB` / preferred `5 us` repeatability targets. The
windowed impulses correlate at `0.9991` with a fitted C2/C1 level difference
of approximately `-0.178 dB`; this makes a grossly different route unlikely
but does not explain the response-shape difference.

**USER-REPORTED / VERIFIED DIAGNOSTIC — FAILED C3 ATTEMPT:** the user reported
that the prepared attempt produced no audible output, raised two warnings, and
created a visibly invalid response. The API identifies a `-46 dBFS` maximum,
SNR `9.39 dB`, nonsensical System Delay `-4780.4033 ms`, and raw impulse peak
`-0.0019%`, compared with approximately `-2.6%` for C1/C2. REW's attempt-time
warnings were low measured level and poor SNR. Current API state still reports
the qualified software route and stopped generator. The trace is background
noise and must remain diagnostic.

**USER-REPORTED PHYSICAL CAUSE / STRONGLY SUPPORTED INFERENCE:** the user then
found one woofer lead detached from its connector and re-secured it. The
amplifier selection, volume, UMC22 controls/connections, relay, USB, and
indicators were otherwise reported nominal and unchanged. An open woofer
circuit explains all observed C3 symptoms and is the strongly supported cause,
though the contact state throughout the entire attempted sweep was not
electrically logged. The physical change therefore required a de-energised
connection inspection and cold no-signal restart; both subsequently passed as
user-reported evidence below.

**USER-REPORTED RESTART PASS:** with signal stopped, the user turned the
SU-V570 down and off, inspected the repaired connection, and confirmed correct
polarity, full engagement and retention, with no exposed conductor, stray
strand, or possible opposite-terminal contact. The amplifier was restarted at
minimum, remained silent and normal without heat, smell, or instability, and
was returned to the qualified `-38 dB` position without a tone.

**VERIFIED CURRENT API AUDIT:** after that restart the API reported
REW V5.40 beta 133 reachable, audio ready, generator stopped, no application
error, exact exclusive UMC22 endpoints, Java Stereo-only operation, `48 kHz`,
L/L/L/R routing, loopback calibration/timing, IR merge off, zero timing offset,
and the prepared `20-20000 Hz`, `-20 dBFS`, `256k`, one-repetition sweep. Its
per-input calibration object names `ECM8000_calibration_data.csv` under both L
and R, which by itself is insufficient to prove that the electrical reference
is uncalibrated. **USER-CONFIRMED CONFIGURATION:** the user subsequently
confirmed in both Measure and Preferences that active microphone input L names
the ECM8000 CSV and electrical reference input R is `None`. A final API snapshot
then remained complete with no failed endpoint, new measurement, warning, or
error; audio was ready and the generator remained stopped. This clears the
pre-signal calibration gate.

**USER-REPORTED / VERIFIED MEASUREMENT — C3R:** the user reported normal woofer
output, microphone-L minimum headroom `10.7 dB`, reference-R headroom `33.2 dB`,
and no warning or anomaly. Measurement Info was reported correct for the
microphone calibration, loopback soundcard calibration, and L/L/L/R routing;
timing-reference index was `47,850.56` and signal-to-distortion was `60.5 dB`.
The API independently identifies C3R UUID
`910df95f-0bb4-4a53-8b69-e5b6f3b7f898`, captured at 13:05:32 in REW V5.40
beta 133 from `20.1416-19999.879 Hz` at `48 kHz`. It reports System Delay
`3.1133 ms`, IR start `2.9792 ms`, zero timing offset and cumulative shift,
`0.0 ppm` clock adjustment, and SNR `43.41 dB`. The post-capture snapshot was
complete with no new warning or error; audio was ready and the generator was
stopped.

**VERIFIED WINDOW AND IMPULSE / DERIVED ENVELOPE:** C3R's long default window was
replaced through the API and read back as the common native `Hann` `2.0 ms`
left / `Tukey 0.25` `3.5 ms` right window, referenced to its own `3.1133 ms`
direct peak, with FDW/MTW off. Its raw direct peak is `-2.532%`. The API does
not expose REW's plotted ETC directly; a nine-sample moving-RMS envelope of the
raw impulse locates the first
geometry-consistent material reflection at approximately `7.155 ms` absolute,
`4.042 ms` after the direct peak and approximately `27.0 dB` below it. This
agrees closely with C1/C2 at approximately `7.166/7.179 ms` and confirms that
the right window ends near `6.613 ms`, ahead of that reflection. The established
provisional valid range remains `500 Hz-12 kHz` for each candidate; it is not a
promotion of the set.

**USER-REPORTED CONFIGURATION — C4-C6:** immediately before the new post-repair
series, the user confirmed that the repaired woofer connector was fully seated
and that wiring, settings, physical positions, and environmental conditions
were unchanged. Hardware clip indicators were off; the system was silent and
normal. The Agilent U1282A's internal thermometer, without a connected
thermocouple, indicated `22.1 degrees C`; this is a room-temperature indication,
not calibrated local air temperature. No warning, clipping indication, or other
anomaly was reported for C4-C6. Exact displayed headrooms were not retained;
the remaining visible metadata was subsequently reported without another signal.

**USER-REPORTED RETAINED METADATA — C4-C6:** timing-reference indices are C4
`47850.66`, C5 `47850.64`, and C6 `47850.72`; signal-to-distortion figures are
respectively `63.5`, `59.5`, and `61.0 dB`. Headrooms were reported nearly
identical to the earlier successful runs, though exact values were not retained.
The index spread is `0.08` sample, and at `48 kHz`

```text
0.08 sample / 48000 sample/s = 1.667 us.
```

This accounts for the `1.655 us` System Delay spread to about `0.012 us`, so
the recorded timing does not indicate source-to-microphone distance drift.

**USER-REPORTED ENVIRONMENTAL NOTE / DERIVED TIMING:** a window approximately
`1 m` behind the microphone was slightly open and admitted an intermittent
breeze. For the approximately axial geometry, the reflected path is roughly
`3 m` versus the `1 m` direct path, giving

```text
excess delay = (3 m - 1 m) / 343 m/s = 5.83 ms.
```

That direct specular reflection is later than the retained `3.5 ms` right
window and cannot directly explain the stored-window residual. Airflow could
still add turbulence or move a stand, cable, curtain, or light object. Closing
the window is a proportionate control for future acoustic packages, not grounds
to reject C5/C6 or repeat them now.

**VERIFIED MEASUREMENTS — C4-C6:** the API identifies the following unique
post-repair captures, each made in REW V5.40 beta 133 at `48 kHz` from
`20.1416-19999.879 Hz`, with loopback timing, zero timing offset and cumulative
shift, `0.0 ppm` clock adjustment, and no new application warning:

| Capture | UUID | Time | System Delay | IR start | SNR |
|---|---|---:|---:|---:|---:|
| C4 | `a855e31c-42a2-45a7-bb5c-8e1616334c7a` | `14:03:20` | `3.111277 ms` | `2.979167 ms` | `43.91 dB` |
| C5 | `46922260-e9cb-46c0-bdef-3a11ba592b00` | `14:06:49` | `3.111657 ms` | `2.979167 ms` | `44.06 dB` |
| C6 | `1547767f-1781-4e51-b824-462b5a2788e1` | `14:07:08` | `3.110002 ms` | `2.979167 ms` | `44.06 dB` |

C4 was reviewed before the remaining pair, so C5 and C6 are the strictly
consecutive captures (`19 s` timestamp separation); C4 precedes C5 by
`3 min 29 s`. The three-capture System Delay spread is `1.655 us`, comfortably
inside the preferred `5 us` target.

**VERIFIED FILE RETENTION — C4-C6:** because the live REW workspace contained
API-loaded duplicates, each new UUID was saved to a previously absent
single-measurement archive rather than using `Save all`. A selected reload of
each file returned exactly its expected UUID, common `Hann` `2.0 ms` left /
`Tukey 0.25` `3.5 ms` right native window at its own direct peak, no FDW/MTW,
`54,559` native response points, all `131,072` raw impulse samples, and no
extraction warning:

| Capture | Raw `.mdat` | Bytes | SHA-256 |
|---|---|---:|---|
| C4 | [`rew/SB17NRX2C35-8_installed_0deg_1m_UMC22_C4_2026-09-06.mdat`](../../../rew/SB17NRX2C35-8_installed_0deg_1m_UMC22_C4_2026-09-06.mdat) | `2,428,186` | `6e53eaba36039769075544f0cde4d286db155e5429df4cfa4d536a12419b6052` |
| C5 | [`rew/SB17NRX2C35-8_installed_0deg_1m_UMC22_C5_2026-09-06.mdat`](../../../rew/SB17NRX2C35-8_installed_0deg_1m_UMC22_C5_2026-09-06.mdat) | `2,428,186` | `7d1c45bcf2d58c5582f53db679bf7b0febd32c15c2bd2086d82a076b4ad10c1b` |
| C6 | [`rew/SB17NRX2C35-8_installed_0deg_1m_UMC22_C6_2026-09-06.mdat`](../../../rew/SB17NRX2C35-8_installed_0deg_1m_UMC22_C6_2026-09-06.mdat) | `2,428,186` | `6c9a4223073ac9bd52ec7b7ff2dd6e0106f36cd40b9511c0df77a80eeb686ca0` |

**DERIVED C4-C6 REPEATABILITY — STRICT MAX FAIL / PROPORTIONATE DESIGN PASS:**
on the common native unsmoothed grid over `1-5 kHz`, the pairwise results are:

| Pair | Maximum magnitude | RMS magnitude | Mean level | Mean-removed max / RMS | Circular phase max / RMS |
|---|---:|---:|---:|---:|---:|
| C4/C5 | `0.631 dB` | `0.182 dB` | `-0.0667 dB` | `0.564 / 0.169 dB` | `4.119 / 1.208 degrees` |
| C4/C6 | `0.512 dB` | `0.151 dB` | `-0.0727 dB` | `0.439 / 0.132 dB` | `3.473 / 1.859 degrees` |
| C5/C6 | `0.137 dB` | `0.047 dB` | `-0.0060 dB` | `0.143 / 0.047 dB` | `3.565 / 2.060 degrees` |

The old maximum-over-every-bin rule would fail the set because the worst C4/C5
residual is `0.631 dB` near `2.03 kHz`. That statistic selects the single worst
of `10,923` closely spaced native bins and is disproportionate as the sole veto
for an iterative prototype crossover. It remains useful diagnostic evidence.
The small mean offsets do not explain the frequency-dependent shape. C4 also
differs from C3R by `2.115 dB` maximum and `0.804 dB` RMS over `1-5 kHz`, so
C3R is not selected as the current baseline.

Under the revised design-relevant gate, all C4-C6 pairs pass: whole-band
`1-5 kHz` RMS is at most `0.182 dB`; unsmoothed maximum difference over the
intended `2.2-2.4 kHz` crossover region is C4/C5 `0.185 dB`, C4/C6
`0.183 dB`, and C5/C6 `0.112 dB`; full-band circular-phase maximum is at most
`4.119 degrees`; and System Delay spread is `1.655 us`. At `1/24`-octave
smoothing, used only as a broadness check, the whole-band maxima are `0.548`,
`0.447`, and `0.103 dB`, while the crossover-band maxima remain no greater than
`0.157 dB`. The residual is real but too small in the design region to justify
blocking a prototype network that will be measured and iterated.

**DERIVED WINDOW SENSITIVITY / TIME LOCALISATION:** temporary changes on
API-loaded copies, restored afterward, show that all three C4-C6 pairs pass with
`1.0` or `1.5 ms` right windows. At `1.5 ms`, the worst maximum difference is
`0.154 dB`; at `2.0 ms`, C4/C5 and C4/C6 rise to `0.328` and `0.317 dB`, while
C5/C6 remain at `0.085 dB`. The C4-related maxima then grow monotonically to
`0.631` and `0.512 dB` at the retained `3.5 ms` window. Direct-relative raw-
impulse comparisons likewise show sub-percent differences through the direct
packet, with discrepancy increasing later in the early tail. The recurring
shape change therefore enters mainly between approximately `1.5` and `3.5 ms`
after the direct arrival. A `1.5 ms` right window has nominal resolution

```text
Delta f approximately 1 / 0.0015 s = 667 Hz.
```

It is a useful localisation test, not a silent replacement for the established
`500 Hz-12 kHz` production window.

**DERIVED OLDER C1/C2/C3R COMPARISON — FAIL:** with all three captures on the
same native unsmoothed frequency grid and common window, the `1-5 kHz`
three-capture
maximum magnitude spread is `1.754 dB`, RMS spread is `0.822 dB`, maximum
pairwise circular-phase difference is `25.966 degrees`, and System Delay spread
is `10.82 us`. C2 and post-repair C3R are the closest pair, but still show
`0.957 dB` maximum and `0.487 dB` RMS magnitude difference, `11.185 degrees`
maximum circular-phase difference, and `3.50 us` delay difference. Their mean
level difference is only `0.049 dB`; after removing it, `0.947 dB` maximum and
`0.485 dB` RMS magnitude error remain, proving that the failure is response
shape rather than a simple gain offset. At the provisional `2.3 kHz` crossover
point alone they are close (`0.021 dB`, `2.31 degrees`), but the set still fails
the revised whole-band RMS and timing criteria and spans the connector repair.

**VERIFIED PIPELINE AUDIT / DERIVED SENSITIVITY — 2026-09-06:** UUID selection
returns exactly C1, C2, and C3R; the failed diagnostic is absent. All three
responses contain the same `54,559` native frequency points from
`20.1416015625 Hz` at `0.3662109673 Hz` spacing, with SPL units, smoothing
`None`, no PPO resampling, and the stored common window types and widths.
The `1-5 kHz` comparison contains `10,923` point-for-point samples and uses
circular phase differences; ordinary phase subtraction creates false
approximately `360-degree` spikes at wraps.

Fitting a scalar dB gain leaves most of the error:

| Pair, first trace to second | Best dB gain | Residual maximum | Residual RMS |
|---|---:|---:|---:|
| C1 to C2 | `-0.1690 dB` | `1.5846 dB` | `0.5777 dB` |
| C1 to C3R | `-0.2179 dB` | `1.4720 dB` | `0.7114 dB` |
| C2 to C3R | `-0.04890 dB` | `0.9474 dB` | `0.4847 dB` |

Removing each stored System Delay difference explains the broad phase slope
but leaves frequency-dependent phase error:

| Pair | System Delay difference | Raw phase max / RMS | Delay-corrected max / RMS |
|---|---:|---:|---:|
| C1/C2 | `7.3202 us` | `16.476 / 9.773 degrees` | `9.076 / 3.877 degrees` |
| C1/C3R | `10.8178 us` | `25.966 / 13.631 degrees` | `9.462 / 4.771 degrees` |
| C2/C3R | `3.4976 us` | `11.185 / 4.941 degrees` | `6.148 / 3.186 degrees` |

The recorded timing-reference indices for C1 and C3R move from `47,850.04` to
`47,850.56`, or `0.52` sample = `10.833 us` at `48 kHz`. That accounts for all
but approximately `0.016 us` of their System Delay change. The endpoint delay
spread is therefore timing-reference-pick variation rather than evidence of a
`3.7 mm` acoustic-distance change. C2's timing-reference index was not retained,
so the same check cannot be completed for it. Constant delay cannot change
magnitude in any event.

C1's `3.120000 ms` stored window reference is `4.090837 us`, or `0.1964`
sample, before REW's `3.124090837 ms` sub-sample direct-peak estimate. The
stored reference lands on the actual maximum discrete impulse sample. On a
temporary API-loaded duplicate, moving only the reference to the exact
sub-sample peak and reading it back changed none of the `54,559` native
magnitude/phase values and none of the `265` windowed-impulse amplitudes at the
API's returned precision; only the windowed impulse's reported start time moved.
The original `3.12 ms` reference was restored. Window-reference rounding is
therefore excluded as a material cause.

Shortening every right window from `3.5 ms` to `1.0 ms` reduced, but did not
remove, the `1-5 kHz` differences: C1/C2, C1/C3R, and C2/C3R still had
respectively `0.491`, `0.814`, and `0.502 dB` maximum differences. Their
mean-removed maxima were `0.365`, `0.741`, and `0.489 dB`, all above the
`0.2 dB` target. That short window also gives only about `1 kHz` right-window
resolution and cannot support the established `500 Hz` lower limit. Even
`1/6`-octave smoothing leaves respective maxima of `1.031`, `0.943`, and
`0.688 dB`. Short windowing and smoothing can mask some structure, but neither
explains it nor makes the production evidence reusable.

**DERIVED FREQUENCY LOCALISATION:** the discrepancy consists of broad alternating
lobes rather than isolated bins. Principal signed extrema are C1-C2
`+1.754 dB` at `2517.0 Hz`; C1-C3R `-1.254 dB` at `2162.8 Hz`, `+1.482 dB` at
`2501.6 Hz`, `-1.086 dB` at `4212.2 Hz`, and `+1.289 dB` at `4627.1 Hz`; and
C2-C3R `+0.957 dB` at `2811.4 Hz`, `+0.935 dB` at `3801.3 Hz`, `-0.899 dB` at
`4244.0 Hz`, and `+0.863 dB` at `4736.9 Hz`. The worst pair/band RMS values are
C1/C2 `0.877 dB` over `2-3 kHz`, C1/C3R `0.858 dB` over `4-5 kHz`, and C2/C3R
`0.595 dB` over `4-5 kHz`.

**VERIFIED RAW IMPULSES / DERIVED ENVELOPES:** a fresh temporary extraction from
the authoritative `.mdat` returned `131072` raw samples at `48 kHz` for every
UUID. Direct negative peaks are C1 `-2.627883%`, C2 `-2.576019%`, and C3R
`-2.532312%`. Over `-0.5` to `+0.5 ms` relative to each direct peak, pairwise
correlations are at least `0.99984`; over the common `-2.0` to `+3.5 ms` support
they are `0.99908`, `0.99826`, and `0.99919`. In the `+0.5` to `+3.5 ms`
early tail they fall to `0.99328`, `0.98786`, and `0.99428`, with scalar-fit
residuals about `11.6%`, `15.5%`, and `10.7%` of target RMS. The direct wavelet
is therefore nearly unchanged apart from a small level trend; most shape
divergence accumulates in early post-arrival energy.

The first geometry-consistent material-reflection envelope peaks remain closely
grouped: C1 at `+4.0417 ms` and `-27.06 dB`, C2 at `+4.0625 ms` and
`-26.65 dB`, and C3R at `+4.0417 ms` and `-27.01 dB`, all relative to their
direct envelopes. The current right window ends at `+3.5 ms`, ahead of these
peaks. This rules out the principal floor/ceiling/rear-wall reflection as the
direct cause of the stored-window difference, although lower-level earlier
acoustic or structural energy is not uniquely separable.

**EXPLORATORY FIT / INFERENCE:** a single delayed-comb term fitted over
`1.5-5 kHz` describes much of the C3R-related alternating structure with about
`0.99-1.01 ms` delay and `R^2=0.72-0.74`; the weaker C1/C2 fit has
`R^2=0.35`. A `1.0 ms` acoustic delay corresponds to roughly `0.343 m` extra
path at `343 m/s`. This localises a useful time scale, not a physical object:
early reflection/diffraction, cabinet or driver decay, and sweep corruption from
an evolving contact cannot be distinguished uniquely from these files.

**VERIFIED METADATA AUDIT / LIMITATION:** all API-exposed production summaries
agree on REW V5.40 beta 133, `48 kHz`, sweep span, loopback timing/calibration,
zero timing offset and cumulative shift, `0.0 ppm` clock adjustment, polarity,
SPL/align offsets, and extraction warnings. C1's earlier singleton and final
archive extractions are byte-identical for frequency response, windowed impulse,
and window JSON despite changed session IDs, which supports UUID stability.
The API cannot reconstruct historical per-measurement endpoint/channel routing,
calibration assignment, headroom, timing-reference index, or
signal-to-distortion. C1 and C3R have retained UI/Measurement Info evidence;
C2's less complete historical UI metadata is an evidence gap, not positive
evidence of a configuration error.

The separate diagnostic archive was also re-extracted by its UUID. It contains
one `131072`-sample raw trace with peak `0.001904%`, SNR `9.386 dB`, and
System Delay `-4780.403 ms`, confirming background rather than a production
response. Its warning-free extraction manifest means only that file loading and
export succeeded; it does not supersede the user's two attempt-time warnings.

**RANKED INFERENCES:**

1. A variable early delayed acoustic or structural contribution is now the
   strongest class of explanation. C4-C6 repeat through approximately the first
   `1.5 ms`, then diverge, while direct timing remains within `1.65 us`.
   Subtle cabinet, microphone, support, cable, baffle/driver, or nearby-object
   motion could change that energy without a conspicuous direct-arrival shift.
2. Woofer-connector/contact evolution remains plausible across the original
   pre/post-repair boundary and is the only verified intervening physical event
   there. The firmly seated connector did not prevent the C4-related early-tail
   variation, so connector state alone is no longer an adequate explanation for
   all observations. An electrically changing contact could still affect driver
   decay; that was not independently logged.
3. A small environmental change during C4's `3 min 29 s` separation from C5 is
   possible. C5/C6, only `19 s` apart, pass. The slightly open window's simplest
   reflection arrives about `5.83 ms` after the direct sound, outside the stored
   window, but its intermittent breeze could move a stand, cable, curtain, or
   light object. Closing it is a cheap future control. The `22.1 degrees C`
   internal-thermometer indication does not resolve local gradients or motion.
4. C2's lower `38.74 dB` SNR may contribute to the older comparison, but broad
   coherent lobes with associated phase and impulse-tail structure are not well
   explained as random noise alone; C4-C6 have closely grouped `43.91-44.06 dB`
   SNR and still show the C4-related tail change.
5. A historical routing or calibration inconsistency remains logically possible
   for C2 because it lacks complete UI provenance, but the archived/API metadata
   gives no positive evidence for one. It cannot explain variation among the
   consistently configured C4-C6 captures.
6. Scalar gain, constant delay, phase wrapping, C1 window rounding, smoothing,
   and the first material reflection remain quantitatively excluded as complete
   explanations. Shorter windows localise rather than repair the physical
   variability.

**PROVISIONAL DESIGN RELEASE / PARKED ROOT-CAUSE ITEM:** C1, C2, C3R, and C4-C6
are valid response captures; the failed C3 remains diagnostic. The original
`0.2 dB` maximum over every `1-5 kHz` native bin was too strict as the sole
prototype-design gate. Under the revised method, C4-C6 pass on whole-band RMS,
intended-crossover-band maximum, phase, timing, and capture validity. C6 is the
approved current woofer-axis source capture, with immediate C5 as its
repeatability witness and C4 retained as an uncertainty bound. The later
microphone move creates the separate common-position requirement derived in
Section 6.4; it does not demote or alter C6.

The approximately `0.5-0.6 dB` local early-tail variation near `2.03 kHz` is
recorded rather than erased. It is not large enough at the intended
`2.2-2.4 kHz` crossover to block a reversible external prototype network.
Park the root-cause investigation unless same-package measurements reproduce a
design-relevant discrepancy, the crossover choice becomes sensitive to it, or
normal/reverse-polarity validation is incoherent. No further unchanged woofer
repeatability sweep is justified now.

**HISTORICAL INTERPRETATION SUPERSEDED BY C4-C6:** before the post-repair series,
the leading open item was one unchanged C4 discriminator; immediately afterward,
the full-window maximum was temporarily treated as a blocking failure. The
capture and its two authorised repeats are complete, and the proportionate
design release above supersedes both prior positions without deleting their
evidence.

**VERIFIED DIAGNOSTIC RETENTION:**
[`rew/SB17NRX2C35-8_UMC22_C3_no_output_diagnostic_2026-09-06.mdat`](../../../rew/SB17NRX2C35-8_UMC22_C3_no_output_diagnostic_2026-09-06.mdat)
is `2,428,201` bytes with SHA-256
`e60bd9e0643a37d70f2162a8f8aa24214bceb7b2341a17c79198219374d318e2`.
Its retained measurement is named `DIAG-C3-no-output-260906`; it is excluded
from the C1/C2 production authority.

The completed installed-woofer route and its API-assisted audits are retained
in the [UMC22 installed-woofer FRD
runbook](../procedures/UMC22_INSTALLED_WOOFER_FRD.md). No further unchanged
raw-woofer repeatability sweep is required.
Qualification evidence and its generic microphone/absolute-SPL limitations are
in [UMC22 FRD
qualification](UMC22_FRD_QUALIFICATION.md).

## 3. Protection, Geometry, Polar Release, And Scale Evidence

### 3.1 Original detailed protection and source-release evidence

**USER-REPORTED GEOMETRY — 2026-09-06:** after completing the woofer export,
the ECM8000 was raised `150 mm` so its capsule is level with the centre of the
installed tweeter dome and aimed directly at it. The cabinet was not moved.
The user then confirmed that the capsule-to-baffle distance remains `1000 mm`,
the window is closed, and no cabinet/microphone movement occurred during TW1.
This establishes the intended tweeter-axis crossover-design observation point.

**USER-CONFIRMED HORIZONTAL ROTATION GEOMETRY — 2026-09-06:** the jig's
vertical axis passes through the front baffle plane halfway between the left
and right cabinet edges; the vertically aligned driver centres lie on that
horizontal centreline. At `0 degrees`, the baffle front edge and centre are
directly over the pivot. Positive angle means anti-clockwise cabinet rotation
when viewed from above. This fixes the baffle reference point at constant
radius and releases geometry planning for the separate sparse horizontal
runbook; it is configuration evidence, not an off-axis measurement. The
subsequent protected-tweeter and polar captures used that geometry and passed.

**DERIVED COMMON-POSITION CONSEQUENCE:** with `1.000 m` perpendicular distance
to the baffle and `0.150 m` vertical centre spacing, the woofer-to-microphone
distance at the tweeter-axis point is

```text
d_w = sqrt((1.000 m)^2 + (0.150 m)^2) = 1.01119 m
delta d = 1.01119 m - 1.000 m = 0.01119 m
delta t = 0.01119 m / 343 m/s = 32.6 us
phase at 2.30 kHz = 360 deg x 2300 1/s x 32.6e-6 s = 27.0 deg.
```

The units reduce to metres, seconds, and degrees as expected. Independently
moving the microphone onto each driver's axis would erase this design-relevant
geometric contribution. C6 remains valid woofer-axis evidence; TW1 subsequently
captured the required woofer datum from the fixed tweeter-axis microphone point
and its measured extra delay agrees with this prediction as recorded in
Section 1.3.

**PROVISIONAL MEASUREMENT-PROTECTION DECISION:** for the bounded low-level REW
capture only, use a measured nominal `10 uF` non-polar polypropylene film
capacitor, rated at least `100 V`, in series with the tweeter positive lead.
An `8.2-10 uF` measured value is acceptable if `10 uF` is unavailable. This
single capacitor is not a listening crossover and does not satisfy the
manufacturer's high-power `2.6 kHz`, `12 dB/octave` condition; it is adequate
only in combination with the retained approximately `1 V RMS` amplifier-output
limit, a `20-20000 Hz` sweep, one repetition, and the stop rules in the
[protected-tweeter runbook](../procedures/UMC22_INSTALLED_TWEETER_FRD.md).

**USER-REPORTED SELECTED COMPONENT — 2026-09-06:** the selected capacitor is
TDK `B32774H4106K000`, marked `10 uF`, `450 VDC`, polypropylene film. Five
consecutive instrument readings were consistent at `10.13 uF` and `0.08 ohm`
ESR. The repeatability is useful user-reported component evidence; the ESR
reading remains dependent on the meter's test frequency and lead compensation.

**PUBLISHED PART CHECK:** [TDK identifies this ordering
code](https://product.tdk.com/en/search/capacitor/film/dc-link/info?part_no=B32774H4106K000)
as a radial boxed MKP DC-link capacitor, `10 uF`, `+/-10%`, `450 VDC`. The
selected part therefore passes the dielectric, capacitance, polarity, and
voltage-rating requirements.

For `C = 10 uF` and the published `R_e = 3.2 ohm`, the simple resistive corner
estimate is

```text
f_c = 1 / (2 pi R_e C)
    = 1 / (2 pi x 3.2 ohm x 10e-6 F)
    = 4.97 kHz.
```

Using the measured `10.13 uF` gives `f_c = 4.91 kHz`; the `+1.3%` capacitance
difference is immaterial to this protection role.

Using the measured `10.13 uF` and `0.08 ohm` ESR with the measured complex
installed ZMA rather than a fixed resistor, the derived tweeter-terminal/source-
voltage ratios are approximately `-16.91 dB` at `500 Hz`, `-9.23 dB` at the
measured `761 Hz` resonance, `-7.21 dB` at `2.297 kHz`, and `-2.41 dB` at
`5.01 kHz`. The maximum calculated ratio over `500 Hz-20 kHz` is `1.006`
(`+0.052 dB`) near `19.75 kHz`; an approximately `1.00 V RMS` amplifier source
therefore remains about `1.01 V RMS` maximum at the tweeter. This is a low-
energy measurement condition, not a power-handling test.

The qualified clamp/attenuator must be connected across the tweeter terminals
*after* the series capacitor. Referencing before the capacitor would embed its
transfer in the acoustic FRD; at `2.30 kHz` that would introduce approximately
`-7.21 dB` magnitude and approximately `+59 degrees` phase relative to the
driver terminal.
The post-capacitor electrical reference divides out the protection network's
frequency-dependent magnitude and phase while retaining the tweeter's acoustic
phase and delay. REW defines the generated calibration curve as `0 dB` at
`1 kHz`, however, so the capacitor's terminal/source ratio at that frequency
remains as a constant magnitude offset. That scalar is corrected during
modelling as derived below.
No shunt inductor, fuse, or extra series resistor is required for this one
low-level sweep package; the eventual listening and crossover-validation route
must use the designed full high-pass network.

**USER-REPORTED DE-ENERGISED ASSEMBLY — CORRECTED PASS (2026-09-06):** the
first assembly mistakenly placed the clamp/attenuator reference on the wrong
side of the series capacitor. The anomalous `11.162 kohm` amplifier-side
reading prompted a stop before power-up, and the user corrected the wiring.
After correction, amplifier-side resistance rises rapidly to open circuit,
consistent with capacitor DC blocking; resistance directly across the tweeter
and post-capacitor fixture input is `3.326 ohm`; no short is present; and a
second, more thorough wiring inspection passed. This was a caught pre-power
configuration error, not measurement evidence or a driver fault. The protected
tweeter route passes its physical gate.

**USER-REPORTED / VERIFIED POWERED-IDLE AND REW GATE — PASS (2026-09-06):** the
corrected powered route remained silent and normal with no audible output,
anomaly, or smell. A complete GET-only snapshot confirmed audio ready, exact
exclusive UMC22 endpoints at `48 kHz`, Java Stereo only, L/L/L/R, ECM8000
calibration on microphone input L only, loopback calibration/timing with merge
off and zero offset, Generator stopped, and exact C1 `500-20000 Hz`,
`-20 dBFS`, `256k`, one-repetition, clipping-abort fields. This releases only
the first protected C1 sweep before review.

**USER-REPORTED ATTEMPTS / VERIFIED SURVIVING TWEETER C1 — TIMING EXPLAINED,
CONFIRMATION PENDING (2026-09-06):** three starts occurred. The first
accidentally ran with the amplifier off, the second with a fan left on, and the
third as specified. The first two were deleted from REW before review and
remain only user-reported discarded diagnostics. The surviving third capture is
`SB26-IW-000deg-tweeter-axis-1m-U22-260906-C1`, UUID
`00543c2b-4588-4385-9b81-e0d78bca28a0`, captured at `18:36:05`. The user
reported `19.9 dB` minimum measurement headroom, `36.1 dB` reference figure,
`69.5 dB` signal-to-distortion, no clipping, and no anomaly; the API reports
`44.64 dB` SNR and no warning at the run timestamp. The only new cumulative
warnings, at `18:34:41` and `18:35:09`, precede it and belong to the discarded
attempts. Its separately saved source is
`rew/SB26STWGC-4_installed_000deg_tweeter-axis_1m_UMC22_C1_2026-09-06.mdat`,
`2,377,078` bytes, SHA-256
`f47fb2499c27b6bdff4e1ab01595998beb1ce2bd0d96ebe4cb6bcfed5f561c7b`.

The surviving raw impulse has one dominant direct-looking peak, but REW places
it at `79.8603588 ms` with IR start `79.7916667 ms`, equivalent to an impossible
`27.392 m` path. Energy before `10 ms` is more than `81 dB` below the peak, so
this is not a simple late-reflection peak-selection error. The first separated
later peaks are approximately `3.31 ms` (`-22 dB`) and `6.06 ms` (`-19.86 dB`)
after the dominant peak.

The user-reported timing-reference index is `44,166.70`; the preceding retained
woofer C6 index was `47,850.72`. At `48 kHz` their difference is

```text
delta n = 47,850.72 - 44,166.70 = 3,684.02 samples
delta t = 3,684.02 samples / 48,000 samples/s = 76.7504167 ms
corrected C1 delay = 79.8603588 ms - 76.7504167 ms = 3.1099421 ms.
```

The common-position woofer TW1 delay is `3.1388593 ms`, making the corrected
tweeter arrival `28.9172 us` earlier. The purely geometric expectation for the
woofer being `150 mm` off axis at a `1.000 m` baffle-plane distance is
`32.6164 us` earlier for the tweeter (using `343 m/s`); the residual is only
`3.6992 us`, about `1.27 mm` of acoustic path. This exact accounting verifies
that C1's gross delay is timing-reference bookkeeping, not an acoustic path or
reflection. The user also verified that `Loopback delay reference is IR peak`
remained checked, ruling out a changed preference.

**SUPERSEDED PROVISIONAL INFERENCE / RELEASE BASIS:** the deliberate `500 Hz` rather than
`20 Hz` sweep start is the most economical explanation for the changed
reference-peak index; finite-band excitation can change a loopback reference's
peak location. C1 remains corroborating magnitude/impulse evidence; the
completed C2 below is the phase-bearing design source. Its actual result
confirmed the index mechanism and superseded the pre-C2 delay estimate.
The `10.13 uF` capacitor has `785.6 ohm` reactance at `20 Hz`, so a
simple `3.3 ohm` load bound gives only `0.00420` voltage ratio (`-47.53 dB`, or
about `4.2 mV` for a `1 V RMS` source). Extending the logged sweep start is
therefore negligible additional tweeter stress within the unchanged low-level
one-sweep package.

**USER-REPORTED / VERIFIED MEASUREMENT — C2 PASSED; TIMING CAUSE CONFIRMED:**
the one released `20-20000 Hz` sweep completed without warning, clipping, or
anomaly. The user reported `19.1 dB` minimum headroom, constant `36.2 dB`
reference level, timing-reference index `47,857.68`, System Delay `3.0067 ms`,
and `70.9 dB` signal-to-distortion. A subsequent GET-only API review found the
new measurement at session ID `45`, stable UUID
`898195c2-fc7d-4eee-a877-7be9d3782f0d`, captured at `18:54:03`, with
`20.141602-19999.879 Hz`, `48 kHz`, loopback-cal reference, zero timing
offset/IR shift/clock adjustment, `42.19 dB` SNR, no new warning, and Generator
stopped. The live Measure title was inadvertently left as
`SB26-IW-000deg-tweeter-axis-1m-U22-260906-C1`; that is a naming error only and
must be corrected to C2 before its single-measurement save.

The gross-timing mechanism is now established. Expressing the direct peak on
the common sample axis gives

```text
C1: 44,166.70 + 0.0798603588 s x 48,000 samples/s = 47,999.997 samples
C2: 47,857.68 + 0.00300670085 s x 48,000 samples/s = 48,002.002 samples.
```

Restoring the `20 Hz` start therefore removed the entire approximately
`76.9 ms` reference-index displacement. Only `2.004` samples (`41.76 us`)
separate the band-limited impulse maxima; this is a peak-shape consequence of
the different sweep bandwidths, not evidence of a `26.4 mm` hardware movement.
C2's common-band `3.00670 ms` delay is the retained acoustic timing value. Its
approximately `45.3 mm` shorter apparent path than TW1 contains the real
woofer/tweeter acoustic-centre offset as well as the known `11.19 mm` geometric
path difference and must remain in the crossover phase data.

**DERIVED SIGNAL-FREE IMPULSE REVIEW / SOURCE RELEASE:** aligning
the full raw C1 and C2 impulses at their dominant peaks gives correlation
`0.99883`, least-squares C2/C1 scale approximately `+0.13 dB`, and only
`0.455%` RMS residual relative to C2's peak over `-1.0` to `+3.5 ms`. Both have
the same early/room structure: about `+0.625 ms` near `-22 dB`, `+3.312 ms`
near `-21 to -22 dB`, and `+6.062 ms` near `-20 to -22 dB`. The intended
`Hann 2.0 ms` left / `Tukey 0.25 3.5 ms` right window retains the repeatable
early speaker/baffle response while tapering the first separated later arrival.

The default approximately half-second REW windows produce meaningless large
native-bin differences at deep room-comb cancellations. An offline one-sided
approximation to the intended short window instead gives `0.510 dB` RMS and
`1.982 dB` maximum C2-C1 magnitude difference over `500 Hz-12 kHz`. The local
`2.2-2.4 kHz` difference reaches approximately `1.61 dB` and `14.6 degrees`,
but C1 and C2 deliberately used different sweep starts, so this is not a valid
same-configuration repeatability bound; short-window convolution of C1's
`500 Hz` band edge is a confounder. Given C2's clean validity metrics, stable
raw impulse, correct common timing basis, and the project's proportionate
prototype goal, another on-axis sweep is not justified. Retain C1 as
corroborating evidence and C2 as the source candidate, with the lack of a true
same-band tweeter repeat recorded as an uncertainty rather than a veto.

**VERIFIED RETENTION AND EXPORT — C2:** the renamed single-measurement source
`rew/SB26STWGC-4_installed_000deg_tweeter-axis_1m_UMC22_C2_2026-09-06.mdat`
is `2,428,204` bytes with SHA-256
`662d759ba08044bbda6bb04b0d824a0905c6a841b049cd342b1964d041f0d26b`.
A UUID-selected extraction read back the correct C2 title, UUID
`898195c2-fc7d-4eee-a877-7be9d3782f0d`, `3.0067008 ms` delay, native
`Hann 2.0 ms` left / `Tukey 0.25 3.5 ms` right window at the direct peak, and
FDW/MTW off. The retained FRD
`rew/frd/SB26STWGC-4/000deg_tweeter-axis_1m_UMC22_2026-09-06.frd` is
`912,077` bytes with SHA-256
`a409445a40e645682b188b7a12596c10f727d8a0f78138f052c043d60bb0ea1e`.
Its `31,404` finite native unsmoothed rows span
`499.877960-12000.000966 Hz` and match the UUID-selected response within
`0.000058 Hz`, `0.0005152 dB`, and `0.001502 degrees` circular phase. C2 is
therefore promoted from source candidate to the retained protected-tweeter
on-axis source for initial crossover modelling.

**USER-REPORTED / VERIFIED HORIZONTAL POLAR CAPTURE — TWEETER CAPTURE AND
EXPORT PASS (2026-09-06):** the user completed the protected-tweeter
`+20/+40/+60 degree` batch and reported `19.1 dB` minimum headroom across all
three sweeps. The retained three-measurement archive
`rew/SB26STWGC-4_installed_positive_horizontal_020-060deg_tweeter-axis_1m_UMC22_2026-09-06.mdat`
is `7,266,429` bytes with SHA-256
`61a9c66b1edef2199f9b267a0172bba5933ecb21f26ee8c22bcf12cdf9a053d7`.
A post-save REW extraction returned exactly these measurements:

| Angle | UUID | System Delay | API SNR field |
| ---: | --- | ---: | ---: |
| `+20 degrees` | `7c673a7d-1e5c-42fa-9c1c-3786a8d0d2eb` | `3.0170751 ms` | `40.72 dB` |
| `+40 degrees` | `3ebfc5ee-445d-492c-a51b-6f68d776e2fa` | `3.0079346 ms` | `37.83 dB` |
| `+60 degrees` | `8c55d7cb-bc87-4d5b-baed-93fda8e6e251` | `2.9545955 ms` | `34.84 dB` |

All three are native unsmoothed `48 kHz` responses with loopback-cal timing,
zero timing offset, no inversion, IR shift, or clock adjustment, and no
extraction warning. The post-batch GET-only snapshot found Generator playback
off and no new application warning or error. The `62.48 us` direct-peak span
is retained: the increasingly band-limited off-axis waveform can move its
dominant peak, and no independent delay is added or removed.

**DERIVED POLAR-WINDOW DECISION:** relative to C2's on-axis direct-envelope
peak, the new direct peaks fall by approximately `1.15`, `5.39`, and
`10.66 dB`. The first secondary energy near `+1.56/+1.73/+1.79 ms` instead
remains at approximately `-29.2/-29.0/-28.3 dB` on that same absolute scale;
the later approximately `+3.33 ms` arrival is similarly near `-21 dB`. A
feature that stays nearly fixed while direct sound falls with angle is fixed
room/jig energy, not the tweeter's radiation pattern. The polar family will
therefore use `Hann 2.0 ms` left / `Tukey 0.25 1.5 ms` right, FDW/MTW off,
each at its own exact direct peak. API tests on disposable copies showed that
further shortening to `1.25 ms` changed `1.5-12 kHz` magnitude by only
`0.16-0.23 dB RMS` (`0.47-0.77 dB` maximum), adequate convergence for the
project's crossover-directivity decision.

This is a separate matched-window polar dataset, provisionally usable over
`1.5-12 kHz`; it does not supersede or overwrite C2's `3.5 ms` phase-bearing
on-axis design FRD. At the `1.5 ms` polar window, approximate off-axis changes
at `2.0/2.5/3.0/4.0/5.0/8.0/10.0 kHz` are respectively
`+0.87/-0.14/-0.38/-0.60/-0.35/-1.44/-0.58 dB` at `+20 degrees`,
`+1.81/+0.98/+0.07/-1.91/-2.26/-6.71/-6.15 dB` at `+40 degrees`, and
`+0.57/+0.09/-0.99/-3.27/-3.96/-10.32/-11.47 dB` at `+60 degrees`.
These are **DERIVED** angle-to-on-axis differences on the native grid; the
common `+11.14 dB` protected-tweeter model scale cancels. The tweeter remains
broad through the approximately `2.1-2.4 kHz` candidate crossover region and
narrows progressively above it. The later verified woofer exports and combined
sparse-polar comparison completed that interpretation.

**VERIFIED POLAR EXPORTS / RECOVERABLE FILING COLLISION:** the exported
`000/+20/+40/+60 degree` files each contain `31,404` finite native unsmoothed
rows from `499.877960` to `12000.000966 Hz` and identify the correct
measurement title. Direct comparison against the live `1.5 ms` REW responses
is within `0.000009 Hz`, `0.000514 dB`, and `0.00194 degree` circular phase.
Their sizes and SHA-256 hashes are:

| Angle | Bytes | SHA-256 |
| ---: | ---: | --- |
| `0 degrees` | `912,205` | `7ac03bcb1299136545e7ec61804fea4791014cd41f9badca7c2831adc7d0e8b5` |
| `+20 degrees` | `912,205` | `0b02ac7041dcbb8856ecdbfe3290d1b4049a0114882e467aefa34da6d47872b3` |
| `+40 degrees` | `912,193` | `4429a4d720e0e566ea418c34d09b30e8f2542d1988d090e906ad945262ae8bc1` |
| `+60 degrees` | `912,157` | `a8ad5c386d187428809a578191a0ac53b6e8de86a97870411af457ef9baf018c` |

REW retained the requested data down to `500 Hz` rather than cropping at the
provisional `1.5 kHz` polar limit. This preserves rather than loses samples;
use only `1.5-12 kHz` for polar conclusions and do not repeat the export.

The files were exported in the driver root rather than the prepared `polar/`
subdirectory, so the polar `000deg` file replaced the path previously occupied
by C2's `3.5 ms` design FRD. This is a recoverable pathname collision, not a
measurement loss: the verified polar bytes exist and the authoritative C2
`.mdat` can reproduce the earlier design response. The following resolution
supersedes those then-pending filing and restoration actions.

**RESOLVED ROOT RESTORATION:** the verified four-file polar family remains in
its `polar/` subdirectory. The root design FRD once again identifies C2, is
`912,077` bytes, and has SHA-256
`a409445a40e645682b188b7a12596c10f727d8a0f78138f052c043d60bb0ea1e`,
an exact return to the previously verified `3.5 ms` design export. The
intermediate TW1 selection was a recoverable filing error; neither source data
nor current model dependency remains damaged.

**USER-REPORTED / VERIFIED HORIZONTAL POLAR CAPTURE — WOOFER CAPTURE AND
EXPORT PASS (2026-09-07):** the user completed the woofer
`+20/+40/+60 degree` batch with displayed headroom remaining in REW's green
region throughout. The exact minimum was not transcribed, but no repeat is
needed: clipping-abort remained enabled, no warning or anomaly was reported,
and the precise value would not change acceptance. The retained archive
`rew/SB17NRX2C35-8_installed_positive_horizontal_020-060deg_tweeter-axis_1m_UMC22_2026-09-07.mdat`
is `7,266,225` bytes with SHA-256
`47a09014fa84d7ee0aca371ba422f2283c5eb3a089982e77baec44d51163bfab`.
Signal-free inspection finds each expected title once. Loading it back into
REW is deferred to avoid duplicating the live measurements, so the source-file
count has not yet received a formal REW parse/readback.

Live UUID selection found exactly one matching trace at each new angle:

| Angle | UUID | System Delay | API SNR field |
| ---: | --- | ---: | ---: |
| `+20 degrees` | `f486fa1c-6c96-415d-a83f-ace36baacfba` | `3.1617166 ms` | `38.96 dB` |
| `+40 degrees` | `b39a77b4-e206-43ef-b595-e544ac62d53c` | `3.0571430 ms` | `33.07 dB` |
| `+60 degrees` | `c173e83a-b591-4cbc-97c9-9052423c392b` | `3.0053459 ms` | `31.21 dB` |

All are native unsmoothed `48 kHz` responses with loopback-cal timing, zero
timing offset, no inversion, IR shift, or clock adjustment. A post-batch
GET-only snapshot found Generator playback off, REW non-blocking, and no new
warning or error.

**DERIVED WOOFER POLAR-WINDOW DECISION:** relative to on-axis TW1, the direct
envelope peaks fall by approximately `4.69`, `13.30`, and `17.71 dB`, whereas
the separated room/jig energy near `+3.56` to `+3.71 ms` remains almost fixed
at approximately `-23.5`, `-24.0`, and `-24.0 dB` on the on-axis-direct scale
(`-23.0 dB` on axis). The common `Hann 2.0 ms` left / `Tukey 0.25 3.5 ms`
right window, referenced to each exact peak with FDW/MTW off, excludes that
arrival. Comparing a `3.0 ms` right window changes derived directivity over
`1.8-2.6 kHz` by only `0.13`, `0.53`, and `0.50 dB RMS` at
`+20/+40/+60 degrees`; shortening further increases rather than resolves the
variation. The `+40 degree` feature near `2.2 kHz` has about `0.8 dB` local
analysis-window uncertainty.

At the selected window, approximate angle-to-TW1 changes at
`1.5/2.0/2.2/2.4/3.0/4.0/5.0 kHz` are
`+0.20/-1.14/-0.38/-0.94/-1.63/-2.27/-3.28 dB` at `+20 degrees`,
`+0.08/-3.49/+1.45/-1.80/-4.20/-8.11/-12.09 dB` at `+40 degrees`, and
`-3.26/-5.96/-0.63/-4.39/-9.75/-17.76/-15.98 dB` at `+60 degrees`.
These are derived native-grid comparisons. The woofer narrows materially
through and above the candidate crossover region. Deep upper-band nulls at
large angles are increasingly contaminated by fixed room energy/noise, so use
this sparse family over `1.5-5 kHz` for the present design decision and do not
infer laboratory-grade polar smoothness from it.

The selected window has been applied and read back on the one live copy of
TW1 and every new angle. It changed the REW workspace only; no `.mdat` or FRD
was overwritten.

**VERIFIED WOOFER POLAR EXPORTS:** the `0/+20/+40/+60 degree` files contain
`31,404` finite native unsmoothed rows over
`499.877960-12000.000966 Hz`, identify the correct SB17 measurements, and
match the UUID-selected live responses within `0.000009 Hz`, `0.000530 dB`,
and `0.001724 degree` circular phase. Their sizes and SHA-256 hashes are:

| Angle | Bytes | SHA-256 |
| ---: | ---: | --- |
| `0 degrees` | `913,085` | `03923152b08c36e066cb0f9520c7a76489bf6837e3b85cd06c67af0c12a8e4b7` |
| `+20 degrees` | `911,885` | `f418f7a50449bead7b97c4c89a52ffc938fb199bf4f0d0efc09171e638b03453` |
| `+40 degrees` | `911,941` | `c7c902610f35623e32355b4c4b1a78390f9a6f3266dd61d0fe84336e84e1ea6a` |
| `+60 degrees` | `912,085` | `c34213923124963ba5dad703729ab84c61f4e84d23e0d33c0c3778d0663b63a1` |

The first attempt selected the already retained SB26 traces for the three new
paths. Correct SB17 exports replaced those non-unique copies; no source,
design FRD, measurement, or unique evidence was lost.

**DERIVED CROSS-DRIVER DIRECTIVITY RESULT:** averaging each raw directivity
curve over a one-sixth-octave band gives the closest broad woofer/tweeter match
near `2.2-2.3 kHz`. The RMS mismatch across `+20/+40/+60 degrees` is
approximately `1.99 dB` at `2.2 kHz` and `2.05 dB` at `2.3 kHz`, versus
`3.32 dB` at `2.1 kHz`, `3.10 dB` at `2.4 kHz`, and approximately
`3.8 dB` at `2.5-2.6 kHz`. These figures are comparative design evidence, not
laboratory polar tolerances; the positive-side sparse set and local window
uncertainty remain explicit.

Applying Seed A's documented component values, installed complex impedances,
and the common tweeter `+11.14 dB` scale to the measured polar responses gives
a preliminary system-directivity estimate. Over `1.8-3.0 kHz`, its extrema
relative to on axis are approximately `-1.74/+0.29 dB` at `+20 degrees`,
`-1.94/+2.11 dB` at `+40 degrees`, and `-3.12/+0.43 dB` at `+60 degrees`.
The largest positive feature is near `2.2 kHz` at `+40 degrees`; it is present
in both raw branches and overlaps the recorded approximately `0.8 dB` woofer
window uncertainty. It warrants VituixCAD inspection but not rejection or fine
optimisation from this sparse dataset. The evidence retains Seed A as a useful
starting point and argues against moving the handover materially above
approximately `2.3 kHz`.

**DERIVED MODEL-IMPORT LEVEL CORRECTION — C2:** REW's documented loopback
calibration convention uses the loopback level at `1 kHz` as its `0 dB`
reference. Interpolating the installed tweeter ZMA at `1.001 kHz` gives
`|Z| = 5.061 ohm` at `-22.29 degrees`. With the reported `10.13 uF` capacitor
and `0.08 ohm` ESR,

```text
Zc = 0.08 + 1/(j 2 pi f C)
H = Zt / (Zt + Zc)
|H| = 0.27744
20 log10(|H|) = -11.137 dB.
```

The units in `Zt/(Zt+Zc)` cancel, as required for a voltage ratio. The
post-capacitor reference removes the network's frequency-dependent shape, but
normalisation leaves C2 lower by this constant relative to the directly driven
woofer measurement. Apply `+11.14 dB` to C2 magnitude in VituixCAD, with no
extra phase, delay, polarity, smoothing, or minimum-phase operation. As a
cross-check, this changes the native unfiltered TW1/C2 relationship from
approximately `-8.08 dB` to `+3.06 dB` at `2.30 kHz`, a physically plausible
starting sensitivity relationship. This is a **DERIVED** correction, not an
absolute-SPL calibration or a new measurement.

**RESOLVED FILING ERROR:** REW initially wrote that valid C2
export over TW1's path under `rew/frd/SB17NRX2C35-8/`. The C2 bytes have been
copied without alteration to the correct SB26 path above. TW1's authoritative
single-measurement `.mdat` remains intact, and its live UUID still holds the
approved native window, so no unique evidence was lost. The corrective TW1
re-export returned exactly to the previously established `913,085` bytes and
SHA-256
`03923152b08c36e066cb0f9520c7a76489bf6837e3b85cd06c67af0c12a8e4b7`
and its header again identifies TW1. Both driver-specific export paths are now
correct and independently validated.

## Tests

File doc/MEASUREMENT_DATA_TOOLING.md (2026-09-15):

# Compact Measurement Data Tooling

| State | Value |
| --- | --- |
| Lifecycle | **CURRENT SUPPORTING REFERENCE** |
| Owns | Compact commands for FRD, ZMA, extracted REW response/impulse, `.mdat`, and VituixCAD VXP inspection, comparison, batching, or source fingerprinting |
| Does not own | Raw measurement authority, measurement procedures, driver baselines, crossover conclusions, or live REW qualification |
| Read when | A task needs facts from a large supported data file, a comparison between files, or maintenance of these tools |
| Current approved action | Use the narrowest applicable command before reading raw rows or writing a temporary parser |
| Limitations | `.mdat` needs a running REW API and mutates its workspace; VXP analysis audits stored semantics and sources but does not solve the circuit |
| Last reviewed | 2026-09-15 |

## 1. Authority and output policy

The retained FRD, ZMA, `.mdat`, impulse export, or VXP remains the source
authority. Tool output is a derived convenience summary. Each file-based result
identifies its source path, size, and SHA-256 hash; analysis results also record
the requested band, grid policy, points, window, or fit choices and any parser
warnings.

Use these commands to keep full sample arrays inside the process and return only
decision-relevant JSON. Start with a narrow band or small point set. Read raw
rows only when investigating an anomaly, checking the parser, or answering a
question outside the supported analyses. If the same missing analysis is likely
to recur, add it to the committed tool and tests instead of leaving its only
implementation in `/tmp`.

These measurement tools use only the Python standard library and write
their normal results to standard output. Run them from the project root with `python3` in WSL
or replace `python3` with `.venv\Scripts\python.exe` in Windows PowerShell.

## 2. FRD, ZMA, and extracted response or impulse data

[`src/measurement_summary.py`](../src/measurement_summary.py) is the command-line
front end; [`src/measurement_analysis.py`](../src/measurement_analysis.py) is its
reusable in-memory implementation. The parser accepts REW text FRD/ZMA files,
frequency-response CSV written by the REW API client, and impulse CSV or a saved
REW impulse-response JSON payload.

### 2.1 Inspect one curve or selected points

```text
python3 src/measurement_summary.py inspect FILE --band LOW_HZ HIGH_HZ
python3 src/measurement_summary.py points FILE --frequency HZ --frequency HZ --method interpolate
```

`inspect` reports source and selected sample counts, frequency range and grid,
magnitude/phase availability and extrema, metadata, and validation warnings.
`points` uses either the nearest retained sample or explicit interpolation. For
impedance data it also converts magnitude and phase to real and imaginary ohms.

### 2.2 Impedance and EPDR

```text
python3 src/measurement_summary.py impedance FILE --band LOW_HZ HIGH_HZ
```

This reports extrema of magnitude, phase, real and imaginary impedance, plus the
minimum ideal full-rail class-B EPDR. Optional `--q-band LOW HIGH` requests a
single-peak magnitude-bandwidth estimate; `--q-threshold-ohm VALUE` supplies its
explicit crossing threshold. This is not a fitted loudspeaker equivalent-circuit
or Thiele-Small parameter extraction.

### 2.3 Curve and polar comparisons

```text
python3 src/measurement_summary.py compare A B --band LOW_HZ HIGH_HZ --grid exact
python3 src/measurement_summary.py polar REFERENCE --curve 20deg=FILE --curve 40deg=FILE --band LOW_HZ HIGH_HZ --grid interpolate --frequency HZ
```

`compare` uses the signed convention A minus B and reports compact magnitude and
circular-phase statistics. `--fit-gain` removes a constant magnitude offset;
`--fit-delay` reports the delay correction implied by the unwrapped phase slope.
`exact` refuses mismatched grids. `interpolate` evaluates B on A's in-band grid
without extrapolation. The polar form reports attenuation, any off-axis excess,
and optional selected-frequency differences for named curves.

### 2.4 Impulse comparison

```text
python3 src/measurement_summary.py impulse A B --window START_S END_S --grid exact --max-lag-ms VALUE
```

The required window and grid policy prevent an accidental whole-response or
implicit-resampling comparison. The result reports gain, correlation, RMS and
maximum residual, and an optional sample-quantised delay fit bounded by
`--max-lag-ms`. Gain fitting is on by default; add `--no-fit-gain` to compare
absolute amplitudes. Use `--sample-rate-hz` when the rate must be asserted rather
than derived from the time columns.

## 3. Batch selected measurement questions

`measurement_summary.py batch` runs 1–32 selected questions from one JSON recipe,
reusing parsed files within the run. Paths in the recipe are relative to the
recipe file, so a retained recipe remains portable with its source files. Each
task returns the usual bounded analysis with source provenance; the result also
records the recipe path, size, SHA-256, task count, and parsed-file counts. Keep
recipes in the relevant source/data tree when they become durable evidence;
use ignored `outputs/` only for disposable questions.

```text
python3 src/measurement_summary.py batch outputs/questions.json
```

A small recipe is:

```json
{"tasks":[
  {"name":"axis","operation":"inspect","path":"../rew/frd/axis.frd","band":[1000,5000]},
  {"name":"two-kilohertz","operation":"points","path":"../rew/frd/axis.frd","frequencies":[2000],"method":"interpolate"}
]}
```

The supported operations are `inspect`, `points`, `impedance`, `compare`,
`polar`, and `impulse`, using the same explicit band, grid, window, and fit
choices as their single-operation commands. Point lists are limited to 32,
polar curve sets to 16, each batch to 32 tasks, and the recipe to 128 KiB. This mode does not inspect
`.mdat` directly; that still requires REW.

## 4. Compact `.mdat` analysis through REW

[`src/rew_api_extract.py`](../src/rew_api_extract.py) delegates binary `.mdat`
interpretation to REW, then calls the same in-memory analysis functions:

```text
python3 src/rew_api_extract.py summarize FILE --band LOW_HZ HIGH_HZ --frequency-unit UNIT --smoothing None --ppo 96 --at HZ
```

The result contains no raw arrays and writes no files. The band and unit are
required; `--measurement` and `--at` are repeatable. For `ohm`, the output adds
real/imaginary extrema and EPDR. It records the source hash, REW versions,
request settings, returned scalar metadata, warnings, and the fact that loading
the file added measurements to the current REW workspace. The workspace is not
saved or cleaned up. Runtime setup, live-access constraints, extraction, and
qualification are owned by the [REW API client](REW_API_CLIENT.md).

The default `96` PPO is a compact, consistent review grid. Because REW may apply
PPO/2 anti-alias smoothing during resampling, use the full extraction route with
PPO omitted when a native-grid extremum or narrow feature could affect the
decision.

## 5. VituixCAD VXP summary, comparison, and source fingerprints

[`src/vxp_summary.py`](../src/vxp_summary.py) parses the XML VXP without opening
VituixCAD:

```text
python3 src/vxp_summary.py summary FILE
python3 src/vxp_summary.py compare LEFT RIGHT --max-differences 25
python3 src/vxp_summary.py fingerprints FILE
```

`summary` reports global project settings, driver FRD/ZMA assignments and their
existence, angular responses, scale/delay/polarity/minimum-phase settings, and
crossover component values and parasitics. Stored Windows paths are mapped into
the current checkout when possible. `compare` returns a bounded normalized
semantic diff and deliberately excludes schematic layout-only movement.

`fingerprints` returns only the VXP source hash and unique referenced
FRD/ZMA paths, byte sizes, SHA-256 hashes, and missing paths. The optional
`--fingerprint-sources` flag on `summary` adds hashes to source records; on
`compare` it also reports a byte change at the same stored source path as a
semantic difference. Fingerprinting reads referenced files and is useful for
provenance audits, not routine configuration comparisons. No source file is
modified.

This is a source/reference and configuration audit, not a circuit solver. It
does not calculate acoustic summation, load impedance, transfer functions, or
whether two differently drawn networks are electrically equivalent. Use
VituixCAD and retained measurement evidence for those questions.

## 6. Verification and reconstruction

Run the complete standard-library suite after changing any tool:

```text
python3 -m unittest discover -s tests -v
python3 -m py_compile src/measurement_analysis.py src/measurement_summary.py src/rew_api_extract.py src/vxp_summary.py src/project_docs.py src/project_checks.py
```

Representative retained-data checks should confirm that:

- the installed-axis FRD contains `31,404` samples and its retained polar copy
  compares with zero magnitude and phase difference;
- the 2026-09-09 Seed A ZMA reproduces approximately `4.3664 ohm` minimum
  magnitude, `4.28443 ohm` minimum real part, and `2.56334 ohm` minimum EPDR;
  and
- each retained VXP parses, the practical project reports two drivers and eight
  electrical components, and no referenced FRD/ZMA source is missing.

No new ignored output class is required: summaries normally remain on standard
output, and disposable redirected results may use the existing ignored
`outputs/` tree. Reconstruct a summary from the retained source, its recorded
hash, the committed tool, and the recorded command parameters.

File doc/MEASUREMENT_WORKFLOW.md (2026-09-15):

# Measurement Equipment and Workflow

| State | Value |
| --- | --- |
| Lifecycle | **CURRENT POLICY AND ROUTING** |
| Owns | Project-wide measurement policy, evidence boundary, and routing |
| Does not own | Planning detail, interface settings, fixture operation, individual capture steps, qualification results, or crossover fabrication |
| Detailed driver evidence | [Driver analysis](DRIVER_ANALYSIS.md) |
| Procedure dispatcher | [REW documentation map](rew/README.md) |
| Measurement artefacts | [`rew/`](../rew/) |
| Compact data inspection | [Measurement data tooling](MEASUREMENT_DATA_TOOLING.md) |
| Planning and evidence detail | [Measurement planning and evidence](rew/MEASUREMENT_PLANNING_AND_EVIDENCE.md) |
| Current approved measurement action | Follow the [project dashboard](../README.md) for the active gate and the [REW dispatcher](rew/README.md) for its exact procedure; do not infer a signal release from this policy file |
| Limitations | This policy does not qualify a device, preserve detailed measurement results, or replace the current task-specific safety and routing procedure |
| Last reviewed | 2026-09-15 |

## 1. Current measurement policy

- Separate verified measurements, derivations, inferences, provisional decisions, and open items.
- Compare traces only when their controlled conditions are recorded or explicitly bounded.
- Treat impedance-derived alignment as electrical evidence, not a substitute for acoustic magnitude, phase, distortion, and directivity. Design from installed-baffle, phase-bearing acoustic data and current installed ZMA, not nominal impedances or textbook parts alone.
- Keep exploration provisional until its required measurement gates pass.
- Use the [compact measurement-data tools](MEASUREMENT_DATA_TOOLING.md) before loading raw FRD, ZMA, impulse, `.mdat`, or VituixCAD contents into a review. Ask for the smallest band, point set, or semantic comparison that answers the question; retain raw-file hashes, parameters, and warnings with the result.
- Use the current specialised procedure for exact routing, level, calibration, startup, stop, and capture instructions. Do not reconstruct live work from history. The detailed reusable plan, file conventions, safety/mutation implications, development order, and evidence handover are in [Measurement planning and evidence](rew/MEASUREMENT_PLANNING_AND_EVIDENCE.md).

## 2. Task routing

- Select exact REW operating and evidence authorities through the [REW dispatcher](rew/README.md). Qualification and history records are audit context, not normal operating context.
- Use [Measurement data tooling](MEASUREMENT_DATA_TOOLING.md) for compact FRD, ZMA, response, impulse, and VituixCAD inspection or comparison.
- Use the [REW API client](REW_API_CLIENT.md) for current live API status or a session snapshot; use its linked [`.mdat` extraction procedure](rew/procedures/REW_MDAT_EXTRACTION.md) for any `.mdat` load, summary, or export.
- Read [Measurement planning and evidence](rew/MEASUREMENT_PLANNING_AND_EVIDENCE.md) when planning a new/repeated series or interpreting and recording its results.

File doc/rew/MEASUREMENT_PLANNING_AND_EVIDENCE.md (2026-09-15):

# Measurement Planning and Evidence

| State | Value |
| --- | --- |
| Lifecycle | **CURRENT SUPPORTING REFERENCE** |
| Owns | Reusable measurement planning, file/calibration conventions, generic development order, and evidence handover |
| Does not own | Interface routing, live capture steps, device qualification, or individual measurement conclusions |
| Read when | Planning a new or deliberately repeated measurement series, interpreting measurement evidence, or updating its owning authority |
| Current approved action | Select the active gate and its exact procedure through the [REW dispatcher](README.md); use this record only for the reusable plan and evidence rules |
| Limitations | It does not release a signal, qualify hardware, or replace the applicable procedure's prerequisites and stop rules |
| Last reviewed | 2026-09-15 |

## 1. Planning principles

- Separate verified measurements, derivations, inferences, provisional decisions, and open items.
- Compare traces only when mounting, sealing, damping, orientation, ambient conditions, sample rate, calibration, sweep settings, and drive level are controlled or explicitly recorded.
- Treat impedance-derived alignment as electrical evidence, not a substitute for acoustic magnitude, phase, distortion, and directivity. Design the passive crossover from installed-baffle, phase-bearing acoustic measurements and current installed ZMA files, not nominal impedances or textbook parts alone.
- Keep exploratory optimisation provisional until its named measurement gates pass.
- Before loading a large supported FRD, ZMA, impulse, `.mdat`, or VituixCAD file, use [Measurement data tooling](../MEASUREMENT_DATA_TOOLING.md) for the smallest relevant band, point set, or semantic comparison. Carry the raw-file hash, parameters, and warnings with the derived result.
- Use exactly one current specialised procedure for device routing, calibration, level, startup, stop, and capture instructions. Qualification and history record evidence; they do not reconstruct a live procedure.
- For the qualified `5 V` USB-powered impedance jig, stop signal generation before changing the DUT. Carry unchanged settings and passed checks forward; repeat qualification only after a relevant change, anomaly, or failed control.

## 2. Capability and file conventions

The minimum useful set is a calibrated measurement microphone, two-channel interface or equivalent, test amplifier, REW, VituixCAD, calibrated impedance jig or equivalent, microphone stand, repeatable rotation/angle setup, tape or laser measure, and true-RMS multimeter for terminal-voltage and cold-resistance checks. Swept-sine and impulse-response work through a PC interface is preferred; an audio-frequency spectrum analyser is not required.

- `rew/` holds raw REW measurements and impedance exports. Durable acoustic exports use `rew/frd/<driver>/<AAA>deg_<distance>_<interface>_<date>.frd`, with zero-padded angles; add an axis qualifier if one driver has multiple vertical observation points.
- `calibration/` holds retained calibration sources and documented REW-compatible derivatives; `vituixcad/` holds projects and generated outputs. The [REW dispatcher](README.md) maps procedures, qualification evidence, active diagnostics, and history under `doc/rew/`.
- Retain impedance headers, decimal points, frequency/magnitude/phase columns, dense unsmoothed data, and descriptive filenames. Record terminal voltage, cold DCR, ambient temperature, cooldown, damping state, mounting, screw condition, and wiring changes. Treat data below the validated low-frequency range as artefacts, not inputs to $R_e$, Q, or alignment estimates.
- Use the applicable procedure for interface and calibration settings. The controlled driver-impedance comparison series uses `48 kHz` unless a new series is deliberately established; recalibrate after a changed sample rate, interface path, input gain, measurement leads, sense resistor, or jig wiring, not an ordinary DUT swap on the unchanged qualified route.

## 3. Acoustic plan and safeguards

- Preserve one electrical timing reference and fixed microphone/rotation geometry across both drivers. Use the [FRD measurement method](FRD_MEASUREMENT_METHOD.md) for geometry, impulse/ETC review, production windows, naming, and provenance.
- Match microphone calibration to the actual device, selector, channel, and orientation, and verify it in stored metadata. A generic response file is generic-calibrated, not serial-number-specific or absolute-SPL calibration; record that limitation.
- A first low-level sweep is the headroom and metadata check. Once it validates a bounded package, run its remaining named captures consecutively under one unchanged-state declaration and common stop rules. Repeat the audit after a relevant physical, electrical, application, or day/session boundary.
- Select a REW-native production window from the actual impulse/ETC and required bandwidth. A short qualification window does not automatically become the production window. Record distance, axis, height, gate/window, sample rate, amplifier setting, terminal voltage, and room state.
- Measure individual drivers before filtered sums; retain normal- and reverse-polarity results. Name files for driver, angle, polarity/filter state, level, and date or sequence.
- A loopback calibration with deliberate series protection is normalised by REW to `0 dB` at `1 kHz`. It removes the network's frequency-dependent shape but leaves its normalisation-frequency gain as a constant offset. For protected-tweeter C2, apply the documented `+11.14 dB` magnitude scale in the model; do not change its measured phase or delay.
- Completed Seed A filtered-branch, sum, reverse-null, and horizontal evidence is in the [commissioning history](history/SEED_A_EXTERNAL_CROSSOVER_COMMISSIONING_2026-09-08_TO_09.md), for audit only. The [Seed A level/thermal qualification](qualification/SEED_A_FULL_SYSTEM_LEVEL_AND_THERMAL_QUALIFICATION_2026-09-10.md) owns that result and its excluded wrong-angle trace. For speaker two, retain the `4.000 V RMS` ceiling, both Type-K contact probes, and a correct immediate hot `0-degree` sweep; retest speaker one only if matched evidence reveals an anomaly.

## 4. Reusable development order

Use this order only from the active gate on the [dashboard](../../README.md): confirm dimensions and sealing; record damping, mounting, ambient conditions, and cold baselines; condition drivers when still needed; establish cooled installed ZMA baselines; satisfy the selected procedure; measure installed drivers with common timing; obtain gated far-field, near-field bass, and useful horizontal data; measure protected distortion; import current phase-bearing FRD/ZMA into VituixCAD; design a realisable passive network; then measure filtered branches, normal sum, reverse null, impedance/EPDR, distortion, and off-axis behaviour. Change one crossover, damping, or placement variable at a time and repeat only decisive checks. Move the crossover inside only after the external assembly passes the [crossover design](../CROSSOVER_DESIGN.md) gates, then repeat final installed-system measurements in intended placement.

## 5. Evidence handover

After a material series, preserve the raw REW/VituixCAD source in its data tree, record controlled conditions and deviations, and recalculate derived quantities from the retained export with an explicit band, comparison policy, or point set. Update [Driver analysis](../DRIVER_ANALYSIS.md) or the relevant topic authority with a dated evidence-labelled entry. Put detailed superseded chronology in its designated history record; update the [dashboard](../../README.md) only for high-level state or a locked decision.

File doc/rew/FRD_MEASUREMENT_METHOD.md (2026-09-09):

# Installed-Driver FRD Measurement Method

Lifecycle: **METHOD**
Owns: interface-neutral geometry, timing, repeatability, windowing, naming, and
provenance requirements for installed-driver acoustic measurements.
Does not own: interface qualification, fixture operation, a particular
driver's safe sweep limits, or authorisation to power equipment.
Last reviewed: 2026-09-09

## 1. Objective And Evidence Boundary

The objective is a reusable complex frequency response—magnitude and phase—of
one installed driver in the actual prototype. Measurements intended for
crossover work must share a physical reference, timing convention, geometry,
level convention, and documented impulse-response window. A visually smooth
trace is not sufficient if its timing, calibration, or provenance is unknown.

Use the applicable interface runbook for connection, level, and safety gates.
For the currently qualified UMC22 woofer route that authority is
[`procedures/UMC22_INSTALLED_WOOFER_FRD.md`](procedures/UMC22_INSTALLED_WOOFER_FRD.md).
The UMC202HD route remains suspended under
[`procedures/UMC202HD_FRD_SUSPENDED.md`](procedures/UMC202HD_FRD_SUSPENDED.md).

Evidence classes used here are:

- **USER-REPORTED** for the present physical state or geometry;
- **VERIFIED MEASUREMENT** for stored observations with identified conditions;
- **DERIVED** for quantities calculated from those observations;
- **INFERRED** for plausible explanations that are not uniquely established;
- **PROVISIONAL DECISION** for a reversible working choice; and
- **OPEN ITEM** for an unresolved input or gate.

## 2. Reference Planes And Common Timing

For full-dual measurement, one input records the microphone and the other
records a protected electrical reference derived from the electrical reference
plane selected for the unit under test. The ordinary woofer route samples the
driver/amplifier output directly; the protected-tweeter route deliberately
samples the tweeter terminals after its series capacitor. Keep the loudspeaker
cable unchanged within a driver set and record any later change of reference
plane.

With REW's `Make calibration data from loopback response` option, the measured
reference response becomes a correction curve whose magnitude is defined as
`0 dB` at `1 kHz`. Frequency-dependent response of the reference path is
therefore removed, but a deliberate network's gain at `1 kHz` remains as a
constant magnitude offset. Correct that scalar during modelling from the
measured network and complex driver load; do not add a second phase or timing
correction to a valid common-timed FRD. For protected-tweeter C2 the retained
derived model correction is `+11.14 dB`.

The electrical reference supplies common timing. Both drivers must use the same
timing convention: do not independently align woofer and tweeter peaks, because
that erases their real relative acoustic delay. A timing offset may remove a
chosen common propagation delay only after one valid impulse is inspected and
the same offset is then applied to the complete set.

At a nominal distance `d = 1.000 m` and sound speed `c = 343 m/s`, the direct
time of flight is:

```text
t = d / c = 1.000 m / 343 m/s = 0.002915 s = 2.915 ms
```

The units reduce to seconds, as they should. This is a geometry check, not a
replacement for the measured impulse and timing-reference metadata.

## 3. Geometry And Physical Control

Record at minimum:

- microphone capsule to the chosen baffle-plane reference point;
- capsule and relevant driver-centre heights;
- horizontal and vertical microphone alignment;
- microphone incidence corresponding to the selected calibration file;
- cabinet angle and rotation-axis definition;
- distances to floor, ceiling, rear wall, and nearest side wall;
- enclosure fill, connected driver, speaker cable, and room boundary state;
- doors/windows and any material airflow capable of moving a stand, cable, or
  light object; and
- objects or supports close enough to create an early reflection.

For the established prototype setup, the nominal on-axis distance is `1000 mm`.
The microphone is fixed and aimed at the cabinet; the loudspeaker may later be
rotated on its secured, 10-degree-marked jig. During an on-axis repeatability
set, do not move the cabinet, microphone, stands, cables, fixture, or nearby
objects.

Geometry determines the available reflection-free time. At `1040 mm` source
and microphone height in the documented room, calculated floor and ceiling
reflections begin at approximately `3.81 ms` and the wall behind the cabinet at
approximately `3.91 ms`. These estimates identify where to inspect the ETC;
they do not prescribe a final window before the actual impulse is captured.

## 4. Capture Plan

Before excitation, record the exact application version, driver mode, device
endpoints, sample rate, channel routing, timing mode, calibration treatment,
timing offset, sweep range, level, sweep length, repetitions, clipping-abort
state, and measurement name. Confirm no unrelated application can send audio
to the interface.

Use one controlled first capture when the route, driver, protection, timing
mode, or geometry is new or materially changed. Immediately afterward inspect:

1. both input headrooms and any clipping warning;
2. the stored microphone and soundcard-calibration metadata;
3. measurement and reference input/output identities;
4. timing-reference index, System Delay, IR start, and clock adjustment;
5. the direct impulse and ETC for a single plausible dominant arrival;
6. audible or equipment abnormalities during the sweep; and
7. whether the proposed right window excludes the first material reflection.

Do not continue the batch before that review when the active runbook imposes a
one-capture gate. Once the first capture passes, the runbook may release a
bounded batch of named captures to run consecutively under one unchanged-state
declaration and common stop rules. Do not require a fresh settings recital
between captures. Repeat the physical/no-signal audit only after a reported
change, power-cycle or reconnection relevant to the route, REW endpoint/state
change, anomaly, or a new measurement day—not merely because a chat changed.

Where available, use the current [REW API client](../REW_API_CLIENT.md) for a
read-only pre-capture session snapshot and a selected-measurement extraction
from the saved `.mdat`. This provides a reproducible check of API-exposed
settings, measurement summary, native response, stored windows, and impulse
samples without making a convenience export authoritative. Preserve manual
evidence for physical state, geometry, displayed headroom, timing-reference
sample index, historical per-measurement routing, and any result the client
does not expose.

API extraction loads the source `.mdat` into the current REW workspace and
leaves the loaded copies there. Perform it after the live series is complete
or in a disposable session, and keep API-loaded duplicates out of the retained
production `.mdat`.

After the first capture passes, one immediate unchanged repeat is normally
enough for prototype-design repeatability evidence. Add a third in the same
bounded batch when it has low incremental cost, when the first pair disagrees,
or when a new chain genuinely needs stronger qualification. Store the batch in
raw REW data without overwriting prior diagnostic evidence.

## 5. Repeatability Evaluation

Use two different gates for two different questions. Do not demand laboratory-
like agreement over every FFT bin when deciding whether a capture is useful for
an iterative prototype crossover.

For **interface/direct-path qualification**, a short common direct-sound window
should retain the existing tight target: approximately `0.2 dB` maximum spread
over `1-5 kHz`, System Delay spread preferably no greater than `5 us`, nearly
coincident phase, and no microphone/reference clipping or dropout. This asks
whether the chain repeats before room and later decay dominate.

For **initial crossover-design release** with the documented production window,
the project acceptance targets are:

- no clipping, dropout, warning that invalidates the capture, or route/timing/
  calibration inconsistency;
- System Delay spread preferably no greater than `5 us`;
- unsmoothed `1-5 kHz` pairwise magnitude RMS no greater than approximately
  `0.25 dB`;
- unsmoothed maximum magnitude difference over the current intended crossover
  band no greater than approximately `0.25 dB`;
- maximum circular phase difference over the current intended crossover band
  no greater than approximately `5 degrees`; and
- no broad coherent discrepancy large enough to change the provisional filter
  topology or acoustic-slope decision.

Declare the design-relevant band for each package before comparing repeats.
The completed Seed A acoustic evidence now uses the wider approximately
`1.5-2.5 kHz` transition region around its measured `1.83 kHz` branch equality;
`2.2-2.4 kHz` is retained only as the earlier design hypothesis. A maximum over
every native bin across the wider `1-5 kHz` range remains a useful diagnostic,
but it is not by itself a veto.
Record isolated or out-of-band maxima as a modelling uncertainty and preserve
the less favourable capture. These are project design criteria, not claims of
laboratory metrology or production-unit tolerance.

Delay and phase are linked. At `2.3 kHz`, a `5 us` timing difference gives:

```text
phase = 360 degrees x 2300 1/s x 5e-6 s = 4.14 degrees
```

The seconds cancel, leaving degrees. This is a useful sanity limit: a few
microseconds matter around crossover, even when they look tiny on an impulse
plot.

Compare all repeats on the same frequency grid, window, smoothing, and timing
convention. Use circular phase differences rather than ordinary subtraction at
the `+/-180 degree` wrap. Report both RMS and maximum magnitude differences;
the maximum over thousands of closely spaced native bins is an extreme-value
diagnostic, while RMS better represents the overall modelling perturbation. If
a long window disagrees because later energy changes, preserve that result and
repeat the analysis on the raw impulses using one common direct-sound window.
Do not silently alter the raw session or call the first comparison invalid.

When a set fails, first fit and report a scalar dB offset. Subtracting the mean
magnitude difference tests gain without changing response shape. For phase,
remove a documented constant-delay difference with

```text
corrected phase difference = circular(delta phase + 360 degrees x f x delta t)
```

where `delta phase = phase_A - phase_B` and `delta t = t_A - t_B`.
Delay correction cannot change magnitude. A shorter common right window may be
used as a diagnostic to locate when the divergence accumulates, but a window
that hides the difference or sacrifices the required low-frequency resolution
does not upgrade the production bandwidth. Likewise, `1/48`- to `1/12`-octave
smoothing may describe whether a residual is broad enough to affect crossover
design, but the release figures above remain native and unsmoothed.

## 6. Window Selection

Inspect the impulse and ETC. Place the right window before the first material
reflection, allowing a suitable taper; use the same time support relative to
the direct arrival for all comparable traces. Begin with a `2.0 ms` left window
unless the noise floor or pre-arrival behaviour justifies another value.

A short window trades low-frequency resolution for reflection exclusion. A
total span of `3.0 ms` has nominal resolution:

```text
Delta f approximately 1 / 0.003 s = 333 Hz
```

That can be adequate for a repeatability gate through an approximately
`1.5-2.5 kHz` crossover region, but it is too coarse to establish low-frequency
response. The UMC22 qualification used a
derived `2.0 ms` left / `1.0 ms` right direct window; that result proves chain
repeatability only. It is not automatically the REW-native production window.

For every reusable series, record the selected REW-native window, taper,
smoothing, frequency range over which the result is valid, and the reflection
that limited the right window. Near-field or low-frequency data and any splice
to the far-field response require their own documented method and provenance.

## 7. Naming, Storage, And Export

Names should identify driver, installation, angle, distance, interface, date,
and capture number. A suitable pattern is:

```text
<driver> installed <angle> <distance> <interface> <date> capture <n>
```

For durable FRD exports, the current compact convention is:

```text
rew/frd/<driver>/<AAA>deg_<distance>_<interface>_<YYYY-MM-DD>.frd
```

`<AAA>` is a three-digit zero-padded non-negative angle (`000`, `010`, and so
on), which keeps a single driver's angular files in numerical order. If future
work adds multiple reference axes, levels, windows, polarities, or sessions at
one angle, add a concise qualifier after the angle (for example,
`000deg_tweeter-axis_...`) before allowing two distinct datasets to share one
path.

Retain the raw `.mdat` as the authority. Record its project-relative path,
byte size, SHA-256, REW version, and capture names. Exports must identify their
source measurement, window, smoothing, reference plane, timing treatment, and
generator/client command where applicable. Reconstructible API exports may be
ignored only when the raw source and complete extraction route remain retained.

Do not promote a diagnostic sweep to reusable FRD merely because it looks
plausible. Missing calibration metadata, insufficient headroom, invalid timing,
or a superseded route must remain visible in its evidence label.

## 8. Failure Triage And Scope Limits

For a repeatability failure, check in this order: exact device endpoints and
sample rate; complete channel matrix; timing/calibration mode; active
microphone calibration; headroom; unchanged physical controls; unchanged
geometry; reference voltage; timing-reference index; impulse ambiguity; then
sweep length or window. Quantify gain, constant-delay, window, and smoothing
sensitivity before assigning a physical cause. Change one variable at a time
and preserve the failed result.

Raw-tweeter work requires a separately agreed sweep band, voltage, and
protective high-pass. Polar work requires its own rotation, naming, and
position-verification procedure. Neither is authorised by this general method
or by the current installed-woofer release.

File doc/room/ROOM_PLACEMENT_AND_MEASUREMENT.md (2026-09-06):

# Room Placement and Measurement

> - **Lifecycle:** ACTIVE PLACEMENT AND ROOM-MEASUREMENT AUTHORITY
> - **Owns:** speaker, shelf, and listener coordinates; current/75 mm/150 mm placement candidates; direct-path calculations; placement consequences; and the first listening-position room-measurement series
> - **Does not own:** canonical DAE audit, coupled-volume calculations, boundary construction assumptions, installed-baffle driver FRD procedure, or crossover design
> - **Current decision:** compare current boundary symmetry against 75 mm and 150 mm-left right-speaker trials; do not promote geometric symmetry to a final placement without measurement
> - **Next gate:** confirm the nominal ear marker and run separate-channel impulse/ETC and magnitude comparisons with all other conditions fixed
> - **Limitations:** source/ear acoustic-centre coordinates and normal remote-door states are not yet fully confirmed; room results must not be folded directly into the passive crossover
> - **As of:** 2026-09-06

This file is the placement and room-measurement companion to [ROOM_DETAILS.md](../ROOM_DETAILS.md). Canonical geometry, provenance, boundary assumptions, and screening are in [ROOM_GEOMETRY_AND_SCREENING.md](ROOM_GEOMETRY_AND_SCREENING.md).

## 1. Coordinate and evidence basis

Coordinates use metres: `z` is height; `y` increases toward the speaker wall; `x` runs across the room. The speaker wall is `y = 4.820 m`, and the speakers face decreasing `y`.

Values marked **VERIFIED FILE GEOMETRY** were read from the canonical DAE. **USER-CONFIRMED INSTALLATION** records information supplied separately by the user. **DERIVED** values follow from those inputs. **OPEN ITEM** marks information still required before a final decision.

## 2. Speakers and shelf

The following coordinates are now **VERIFIED FILE GEOMETRY**, rather than placement inferred from the cabinet dimensions:

| Item | DAE coordinate or span |
|---|---:|
| Cabinet nearest the `x = 0` wall | `x = 0.100–0.380 m` |
| Cabinet nearest the `x = 2.550 m` wall | `x = 2.170–2.450 m` |
| Both cabinet bodies, baffle to rear | `y = 4.420–4.720 m` |
| Both cabinet bodies, bottom to top | `z = 1.015–1.445 m` |
| Cabinet envelope | 0.280 m wide × 0.300 m deep × 0.430 m high |
| Rear and nearest-side clearances | 0.100 m |
| Baffle planes and normals | `y = 4.420 m`, facing negative `y` |
| Cabinet-centre spacing | 2.070 m |
| Shelf | `x = 0.100–2.450 m`, `y = 4.420–4.720 m`, `z = 0.970–1.000 m` |
| Shelf dimensions | 2.350 m wide × 0.300 m deep × 0.030 m thick |

- **USER-CONFIRMED INSTALLATION:** the shelf top is 1.000 m above the floor and soft rubber feet provide the 15 mm gap to the cabinet bottoms.
- The speakers and shelf share the same front and rear planes. The shelf is therefore a broad, nearly wall-to-wall horizontal surface directly beneath both baffles, not two small isolated supports.
- **DERIVED:** the ceiling over each cabinet is approximately 1.755 m high at the rear and 2.080 m at the baffle. Minimum nominal clearance above the 1.445 m cabinet top is about 0.310 m at the rear edge.
- **OPEN ITEM:** record shelf material, attachment, and measured deflection or resonance behaviour. The rubber feet may reduce structure-borne transmission and rattles, but they do not guarantee that this large shelf will be non-radiating.

## 3. Listening position and direct-path alternatives

- **VERIFIED FILE GEOMETRY:** the marker is a 0.200 m-diameter vertical disc in the `x-z` plane at `y = 3.700 m`; its centre is `(x, y, z) = (1.200, 3.700, 1.250) m`.
- **OPEN ITEM:** confirm whether its centre is intended to be the midpoint between the listener's ears and whether 1.250 m is the normal seated ear height. Until then it is a nominal head region, not a verified microphone coordinate.
- **DERIVED:** using the speaker baffle-plan centres `(0.240, 4.420)` and `(2.310, 4.420) m`, the marker centre is only 0.720 m forward of the baffle plane. Plan distances are approximately 1.200 m to the left cabinet centre and 1.323 m to the right; the corresponding straight-ahead off-axis angles are approximately 53.1° and 57.0°.
- **DERIVED:** those two sight lines subtend approximately 110.2° at the listener, far wider than a conventional approximately 60° stereo triangle. The 0.123 m path difference corresponds to approximately 0.36 ms and 0.85 dB of spherical distance loss before room effects. These calculations use cabinet-plan centres, not the as-built driver acoustic centres, but the unusually wide angle is too large to be explained by that approximation. Confirm that this near-field, wide-angle arrangement is intentional before finalising listening-axis crossover decisions.
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

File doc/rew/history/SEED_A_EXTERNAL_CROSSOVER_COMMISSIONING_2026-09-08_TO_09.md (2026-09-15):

# Seed A External-Crossover Commissioning — 2026-09-08 to 2026-09-09

> - **Lifecycle:** HISTORY / RETAINED MEASUREMENT EVIDENCE
> - **Owns:** detailed chronology and evidence for completed Seed A cold commissioning, filtered-branch captures, the intermittent tweeter-only-load investigation, normal/reversed full-system captures, and the first physical full-system horizontal set
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

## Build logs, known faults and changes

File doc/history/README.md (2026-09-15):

# Project History

> - **Lifecycle:** HISTORY DISPATCHER
> - **Owns:** routes to dated project-history records
> - **Does not own:** current technical decisions, procedures, or qualification status
> - **Read when:** auditing provenance, a superseded decision, or a dated value
> - **Current consequence:** use the linked current authority for work; history explains how it was reached
> - **Last reviewed:** 2026-09-15

## 1. Driver history

- [Driver-analysis changelog](DRIVER_ANALYSIS_CHANGELOG.md) - installed-driver
  baseline, conditioning, raw-source selection, and later decision changes.

## 2. Crossover history

- [Crossover design development, 2026-09-07 to 08](CROSSOVER_DESIGN_DEVELOPMENT_2026-09-07_TO_08.md)
  - exploratory Seed A, VituixCAD correction, signal-free audit, and Seed B
  comparison.
- [Crossover component build evidence, 2026-09-07 to 08](CROSSOVER_COMPONENT_BUILD_EVIDENCE_2026-09-07_TO_08.md)
  - stock, sample selection, pre-build winding/DCR work, and completed-build
  provenance.

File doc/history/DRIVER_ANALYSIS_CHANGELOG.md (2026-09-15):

# Driver Analysis Change Log

> - **Lifecycle:** DRIVER-IMPACT HISTORY
> - **Owns:** dated changes to driver baselines, conclusions, retention decisions, and the evidence gates that superseded them
> - **Does not own:** full REW, interface, UI, fixture, or troubleshooting chronology
> - **Current authority:** [DRIVER_ANALYSIS.md](../DRIVER_ANALYSIS.md)
> - **Use when:** auditing why a driver conclusion or approved source changed
> - **Limitations:** detailed measurement-route evidence remains in the linked REW qualification and history records
> - **As of:** 2026-09-15

## 1. 2026-08-30 - installed-driver baseline

- Established the two correctly installed ZMA exports as the sole current impedance baseline.
- Recorded the woofer's single approximately 67 Hz sealed-box resonance and derived $Q_{tc}\approx0.82$.
- Recorded the absence of a separate approximately 83 Hz resonance under normal mounting.
- Recorded the tweeter's approximately 761 Hz resonance and close agreement with published Q values.
- Replaced nominal crossover-region loads with the current installed magnitude and phase values.
- Removed obsolete source references and all numerical conclusions dependent on them.

## 2. 2026-08-31 - woofer conditioning procedure

- Recorded the user-reported 45 Hz, 3.44 V RMS terminal-drive condition.
- Replaced the nominal 8-ohm power estimate with current-ZMA estimates of current, real power, and apparent power.
- Added an equivalent-circuit displacement estimate and a conservative 30 Hz, 4.0 V RMS provisional conditioning point.
- Defined cooled repeat impedance measurements, rather than elapsed time alone, as the conditioning stopping criterion.

## 3. 2026-08-31 - matched 48 kHz conditioning comparison and formal run-in procedure

- Clarified that the original installed woofer trace predates all deliberate conditioning.
- Recorded the matched 48 kHz resonance movement from 66.9712 Hz to 65.7115 Hz.
- Identified the post-run trace's approximately 0.342 ohm broadband real-resistance offset and retained the cooled original as the crossover baseline.
- Recorded the conditional effective free-air estimate of approximately 52.66 Hz.
- Linked the formal bounded conditioning, cooldown, measurement, and stopping procedure in `doc/DRIVER_RUNIN.md`.
- Recorded that no dedicated tweeter run-in is presently justified.

## 4. 2026-09-01 to 2026-09-04 — acoustic route remained blocked

- Reference-path qualification and checkout did not change either driver's electrical baseline or retention decision.
- The UMC202HD reached a clean 1.00 V RMS at the woofer but its desktop source-stream dropout prevented reusable FRD; no attempted response from that route became driver-design evidence.
- The active diagnostic and live-Linux discriminator remain in [UMC202HD_DESKTOP_DROPOUT_DIAGNOSIS.md](../rew/UMC202HD_DESKTOP_DROPOUT_DIAGNOSIS.md).

## 5. 2026-09-05 — UMC22 qualification changed the next driver gate

- The risk-accepted UMC22 route passed its bounded electrical, routing, timing, calibration, and three-run repeatability qualification.
- This did not create an approved driver FRD. It removed the interface blocker for controlled installed-woofer capture, subject to the generic microphone-calibration and absent absolute-SPL limitations.
- Raw-tweeter and polar work were not released. The active procedure is [UMC22_INSTALLED_WOOFER_FRD.md](../rew/procedures/UMC22_INSTALLED_WOOFER_FRD.md); decisive measurements are in [UMC22_FRD_QUALIFICATION.md](../rew/qualification/UMC22_FRD_QUALIFICATION.md); failed and superseded attempts remain in [the dated UMC22 history](../rew/history/UMC22_FRD_QUALIFICATION_LOG_2026-09-05.md).

## 6. 2026-09-06 - first reusable installed-woofer FRD start

- Recorded the user's report that the complete UMC22/SU-V570/woofer system,
  controls, wiring, microphone geometry, enclosure/room state, and no-signal
  condition remain identical to the passed qualification, with no anomaly.
- Classified that checkpoint as a user-reported current state rather than a
  new verified electrical or acoustic measurement.
- Held every signal pending a no-excitation audit of the exact REW route and
  active-source microphone calibration. After that review, only one controlled
  `0-degree` capture is to be run before reviewing headroom, stored metadata,
  impulse/ETC, and the REW-native production window.

## 7. 2026-09-06 to 2026-09-07 - raw acoustic sources and Seed A selection

- Promoted C6 as the selected installed-woofer axis source and retained C5 as
  its immediate repeatability witness.
- Completed the protected-tweeter common-position capture and the matched
  positive-horizontal `0/+20/+40/+60 degree` raw-driver families.
- Corrected the VituixCAD response-scale and shunt-connectivity entries, then
  retained same-polarity third-order Seed A after a bounded alternative audit.

## 8. 2026-09-08 to 2026-09-09 - measured build and acoustic validation

- Recorded the measured capacitor banks, inductors and DCRs, resistor banks,
  coherent cold topology, and `5.929 ohm` complete-input resistance.
- Replaced nominal prototype parasitics with the measured values in the
  practical Seed A model; its retained prediction is `2.116 kHz` branch
  equality, `13.2 degrees` relative phase, `18.6 dB` normal-to-reverse
  difference, and `3.805 ohm` minimum impedance.
- Completed filtered woofer/tweeter, normal sum, physical reverse-null, and
  full-system `0/+20/+40/+60 degree` measurements. Real branch equality is
  broadly `1.83 kHz`; summation, reverse null, and sparse horizontal behaviour
  pass proportionately.
- Retained the moderate crossover-region directivity flare for possible later
  refinement and classified the approximately `11 kHz` axial dip as a
  pre-existing angular tweeter/baffle feature that does not justify EQ.
- Closed/parked the intermittent tweeter-only `1 kHz` distortion investigation
  after clean resistor-dummy, damped-branch, and complete-system tests; the
  exact undamped-load mechanism and possible ultrasonic behaviour remain
  unproved.
- Advanced the next gate to qualified as-built system impedance/phase, followed
  by controlled full-system distortion/compression and thermal validation.
  Detailed chronology moved to the [Seed A commissioning
  record](../rew/history/SEED_A_EXTERNAL_CROSSOVER_COMMISSIONING_2026-09-08_TO_09.md).

## 9. 2026-09-10 - bounded level, distortion, and thermal gate

- Retained the nominal `0.5/1/2/4 V RMS` complete-system series with at least
  `27.9 dB` input headroom, no reported warning or audible anomaly, sampled
  distortion within the project gates, and no demonstrated broad compression
  above `0.5 dB`.
- Recorded the narrow approximately `-1.28 dB` 4-versus-2 V shape difference
  near `2.18 kHz` as a matched speaker-two confirmation item, not a broad
  driver or crossover failure.
- Recorded the 15-minute nominal `2 V RMS` CTA-2034 result: R(Tser) and L(W1)
  external-surface rises were only `0.4` and `0.2 degrees C`, with no rise in
  the final five minutes and no reported anomaly.
- Excluded the attempted post-thermal sweep because it was captured at
  `60 degrees`, not `0 degrees`; it is neither an on-axis hot comparison nor
  intentional polar evidence.
- Advanced the driver decision to second-speaker procurement/build and matched
  confirmation. Obtain a valid hot `0-degree` comparison on speaker two and
  retest speaker one only if the new unit reveals an anomaly.
- Detailed evidence is in the [Seed A level/thermal
  qualification](../rew/qualification/SEED_A_FULL_SYSTEM_LEVEL_AND_THERMAL_QUALIFICATION_2026-09-10.md).

## 10. 2026-09-15 — conditioning detail consolidated

- The routine driver authority now retains only the current cooled pre-conditioning ZMA baseline, the approximate `+0.342 ohm` reason that the later trace is comparison-only, and the link to the current bounded procedure.
- Retained superseded operating detail: on 2026-08-31 the installed woofer was driven at `45 Hz`, `3.44 V RMS` terminals. The current installed ZMA gives approximately `10.42 ohm` at `+50.6 degrees`, or `0.330 A RMS`, `1.14 VA`, and `0.72 W` real input; the nominal `V^2/8 = 1.48 W` shorthand was not applicable to the reactive load.
- The linear equivalent-circuit estimate gave about `2.13 mm` peak travel at that condition. The later `30 Hz`, `4.0 V RMS` development point predicted `0.565 A RMS`, `1.9 W` real input, and `2.6 mm` peak, about `47%` of published `Xmax`. These were estimates, not displacement measurements.
- The matched `48 kHz` comparison moved the sealed resonance from `66.9712 Hz` to `65.7115 Hz` (`-1.2597 Hz`, `-1.881%`), equivalent to approximately `+3.87%` total system compliance if moving mass is constant. Its raw impedance maximum changed from about `96.54` to `96.85 ohm`; removing the broadband series offset gives about `96.50 ohm`, `Qmc≈13.8`, `Qec≈0.86`, and `Qtc≈0.81`.
- The derived effective post-conditioning free-air estimate was about `52.66 Hz` (`-2.9%` from the pre-run estimate, about `+6.0%` compliance), but it remained indirect and approximately `44%` above the published `36.5 Hz`. The intervening programme material means the comparison cannot attribute the shift solely to the final sine-wave hour.
- This dated detail is historical context. It does not supersede the cooled original as crossover input or release further conditioning outside [DRIVER_RUNIN.md](../DRIVER_RUNIN.md).

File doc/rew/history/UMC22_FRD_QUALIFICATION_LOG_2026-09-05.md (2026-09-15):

# UMC22 FRD Qualification Log - 2026-09-05

Lifecycle: **HISTORY — AUDIT ONLY; DO NOT USE AS A CURRENT PROCEDURE**

This is the preserved chronological development record from the UMC22
qualification. It intentionally retains interim instructions, failed routes,
partial gates, superseded conclusions, and the final release decision so the
engineering path remains auditable. Those instructions describe the state at
their dated checkpoint and may conflict with later evidence in this file.

For current work use
[`../procedures/UMC22_INSTALLED_WOOFER_FRD.md`](../procedures/UMC22_INSTALLED_WOOFER_FRD.md).
For the concise final evidence use
[`../qualification/UMC22_FRD_QUALIFICATION.md`](../qualification/UMC22_FRD_QUALIFICATION.md).

Date prepared: 2026-09-05

Archived as lifecycle-separated history: 2026-09-06

Status: **QUALIFIED FOR CONTROLLED INSTALLED-WOOFER FRD. GATES A-E PASS WITH
THE RISK ACCEPTANCE AND LIMITATIONS BELOW. ALL THREE FINAL-SETTING SWEEPS STAYED
GREEN AND COMPLETED WITHOUT WARNING OR ABNORMALITY; SYSTEM-DELAY SPREAD IS
`1.0 us`. A COMMON DERIVED DIRECT-SOUND WINDOW PASSES `1-5 kHz` REPEATABILITY:
MAXIMUM MAGNITUDE SPREAD `0.0743 dB` AND MAXIMUM CIRCULAR PHASE SPREAD
`1.931 degrees`. THE WINDOW IS A CONSERVATIVE `2.0 ms` LEFT / `1.0 ms` RIGHT
ANALYSIS WINDOW, NOT A STORED REW WINDOW OR A FINAL PRODUCTION FRD CHOICE.
RAW-TWEETER AND POLAR WORK REMAIN OUTSIDE THIS RELEASE.**

## 1. Purpose And Scope

This is a bounded fallback route for moving the installed-driver FRD work
forward while the desktop-specific UMC202HD dropout is investigated
separately. It reuses the qualified SU-V570 clamp/attenuator, but it does not
silently transfer the UMC202HD-specific connector, phantom-isolation, or input-
headroom findings to the UMC22.

The user is willing to accept a known but unquantified possibility of damage to
the approximately GBP 25 UMC22 in an amplifier fault. That acceptance does not
waive checks which protect the person, SU-V570, PC, loudspeaker, or validity of
the measurements. It also cannot guarantee that a destructive UMC22 input
failure would be perfectly contained within the interface, although the
fixture's high series resistance makes wider damage unlikely.

## 2. Engineering Basis

The UMC22 manufacturer specifications identify:

- Input 1 as an XLR/TRS microphone/line input;
- Input 2 as a 1/4-inch TRS instrument input;
- Input 2 impedance as `1 Mohm`;
- maximum instrument input level as `+2 dBu`; and
- supported sampling rates up to `48 kHz`.

**VERIFIED INTERNAL INSPECTION - 2026-09-05 (USER-OBSERVED):** the UMC22 was
dismantled and both rear output sockets were traced visually on the PCB. Each
socket has separate mechanical tip, ring, and sleeve/shield contacts, but its
ring and sleeve pads join the same copper fill. In the user's terminology the
sockets are physically `TRS` but electrically `TS`: tip is signal, while ring
and sleeve are the same return node. They are not balanced two-active-leg TRS
outputs. This establishes the internal output-contact topology but not USB
channel routing, external cable continuity, output level, or full-duplex
stability.

The fixture's resistance-derived, unloaded floating differential transfer is
`0.09892` (`-20.094 dB`; pre-stress values). The post-stress prediction differs
immaterially at approximately `0.09894` (`-20.092 dB`). At the established
`1.00 V RMS` woofer test level:

```text
Vreference = 1.00 V RMS x 0.09892 = 0.09892 V RMS

+2 dBu = 0.775 V RMS x 10^(2/20) = 0.976 V RMS

normal headroom = 20 log10(0.976 / 0.09892) = 19.9 dB
```

Normal operation therefore has ample nominal level margin. Gate A establishes
that the mechanically TRS `INST 2` socket is single-ended: tip is isolated in
the unpowered resistance map, while ring and sleeve are a low-resistance common
bonded to the USB shell. In the intended system this common will bypass the
fixture's ring-to-sleeve shunt while leaving the tip-leg prediction at
approximately `0.09894 V RMS` for `1.00 V RMS` amplifier output. The final
unpowered ground-path audit must still confirm the complete assembled paths.

The fault case is different. With an amplifier-derived waveform bounded by the
SU-V570's approximately `+/-45.5 V` rails, the qualified resistor network can
place approximately `4.50 V peak` (`3.18 V RMS`, `+12.3 dBu`) on one fixture
node. This is about `10.3 dB` above the UMC22's published maximum instrument
input level. The fixture's `5.5-6.2 V peak` clamp range is higher still. The
published maximum input level is not identified as a destruction threshold, so
neither survival nor damage can be inferred from it.

The primary `9.1 kohm` series resistors still bound amplifier-derived current
to approximately `5 mA` per leg even if an interface node is held near zero:

```text
Imaximum,approx = 45.5 V / 9.1 kohm = 5.0 mA
```

This preserves the fixture's important current-limiting and amplifier-loading
functions. It does not make the UMC22 input compliant with its published level
limit under every fault. A UMC22-specific secondary attenuator/protector remains
an optional risk-reduction improvement, not a prerequisite under the explicit
interface-risk acceptance, unless the connection mapping exposes a new hard
path or unsafe topology.

Manufacturer source: [Behringer U-PHORIA series Quick Start Guide](https://mediadl.musictribe.com/media/PLM/data/docs/UMC/QSG_BE_0805-AAR_U-PHORIA-Series_WW.pdf).

## 3. Minimum Release Gates

These are deliberately limited to uncertainties that materially affect safety
or usable FRD data. Do not repeat the completed component-level fixture
qualification.

### 3.1 Gate A - Unpowered Input 2 Contact Map

Initial state:

1. SU-V570 off and not connected to the UMC22 or fixture.
2. UMC22 USB disconnected, phantom off, and every other UMC22 socket empty.
3. Insert the passed breakout cable's male TRS plug into UMC22 `INST 2`; leave
   its female socket empty.
4. Set the Agilent U1282A to auto-ranging resistance and null the leads.

Measure at the breakout terminal block:

| Measurement | Result |
| --- | --- |
| Tip to ring | open |
| Tip to sleeve | open |
| Ring to sleeve | `0.314 ohm` |
| Tip to USB Type-B shell | open |
| Ring to USB Type-B shell | `0.050 ohm` |
| Sleeve to USB Type-B shell | `0.030 ohm` |

Record a stable resistance, `open`, or a description of any settling or
polarity-sensitive reading. Gate A requires that tip is not hard-shorted to
ring, sleeve, or USB shell. Ring-to-sleeve and sleeve-to-shell results determine
the final adaptor/ground arrangement rather than passing or failing in
isolation. Do not connect USB or generate a signal before this map is reviewed.

**VERIFIED MEASUREMENT - 2026-09-05:** the SU-V570 was off; the UMC22 was
unpowered and otherwise disconnected; phantom was disabled; the passed
breakout cable was inserted into `INST 2`; and its female socket was empty. The
Agilent U1282A was in auto-ranging resistance mode with its leads nulled before
the first reading. All six results above were stable and showed no polarity
sensitivity.

The three sub-ohm common-node readings do not form a precision resistance
triangle: `0.314 ohm` ring-to-sleeve is greater than the sum of the two readings
to the USB shell (`0.080 ohm`). At this scale, changing probe/contact resistance
and residual-zero uncertainty dominate the comparison. This does not obscure
the needed topology: tip is open to every tested return, while ring, sleeve,
and USB shell are mutually connected at sub-ohm resistance. Repeating these as
precision milliohm measurements would not materially improve this gate.

**GATE A DECISION - PASS:** tip is not hard-shorted to ring, sleeve, or USB
shell. `INST 2` is mechanically TRS but behaves as a single-ended input with a
ring/sleeve/USB-shell common. USB connection is now permitted only for the
otherwise-unloaded Gate B phantom-isolation measurements. Signal generation
and any SU-V570 connection or power remain prohibited.

### 3.2 Gate B - Input 2 Phantom Isolation

After Gate A defines the contacts, power the otherwise unloaded UMC22 by USB
and measure DC voltage at tip-sleeve, ring-sleeve, and tip-ring with phantom off
and then on. The microphone, amplifier, fixture, and every other analogue cable
remain disconnected. Stop if any pair exceeds `0.1 V DC`, is unstable, or
behaves materially differently when phantom is enabled. This is one direct
isolation check, not a repeat of the UMC202HD's exhaustive qualification.

| Red probe to black probe | Phantom off | Phantom on |
| --- | ---: | ---: |
| Tip to sleeve | `0.0005 V DC` | `0.0000 V DC` |
| Ring to sleeve | `0.0000 V DC` | `0.0000 V DC` |
| Tip to ring | `0.0004 V DC` | `0.0000 V DC` |

**VERIFIED PARTIAL MEASUREMENT - 2026-09-05:** the SU-V570 was off; the UMC22
was connected only to USB and the passed breakout cable in `INST 2`; phantom
was disabled; and the Agilent U1282A was in auto-ranging DC-voltage mode. No
instability was reported. The largest magnitude, `0.0005 V DC`, is `200` times
below the `0.1 V DC` stop threshold. The close tip-to-sleeve and tip-to-ring
values are consistent with Gate A's ring/sleeve common.

**GATE B PARTIAL DECISION - PHANTOM-OFF HALF PASS:** retain the isolated setup
and complete the three phantom-on readings. Gate B and every downstream gate
remain pending until the on/off comparison is reviewed.

**VERIFIED PHANTOM-ON MEASUREMENT - 2026-09-05:** with the meter already
connected tip-to-sleeve, enabling phantom produced no movement beyond
`0.001 V DC`. Each subsequent pair initially displayed approximately
`0.0020 V DC` and settled to `0.0000 V DC` in approximately `10 s`. This brief
settling was common to all three probe placements rather than a sustained
phantom-derived bias. The largest observed magnitude was `50` times below the
`0.1 V DC` stop threshold.

**GATE B DECISION - PASS:** no tested `INST 2` pair exceeded the threshold,
remained unstable, or changed materially when phantom was enabled. Disable
phantom and disconnect USB before Gate C. Signal generation and SU-V570 power
remain prohibited.

### 3.3 Gate C - Final Unpowered Ground-Path Audit

With the UMC22 contact behaviour known, assemble the intended final cables with
the SU-V570 switched off. Confirm that amplifier positive cannot reach the
UMC22 active input contact without the intended `9.1 kohm` series resistance.
Map amplifier negative, ring, sleeve, USB shell, and the playback-cable ground;
record any deliberate ring-to-sleeve or system-ground commoning and confirm it
does not create an unexpected active-signal path. Stop for an unexplained low-
resistance amplifier-positive to interface-ground path.

The inspected rear-output ring/sleeve common predicts that the playback-cable
return will use that single PCB return node. Gate C must still verify this
end-to-end through the actual selected output and cable; internal inspection
does not replace the final assembled ground-path audit.

**SELECTED PLAYBACK PATH - 2026-09-05:** UMC22 Output 1 will feed SU-V570
`AUX` left through the same already-mapped TS-to-RCA playback cable used for
the UMC202HD checkout. Its retained cable-only results are TS tip to RCA centre
`0.244 ohm`, TS sleeve to RCA shell `0.078 ohm`, and both cross-paths open. The
UMC22 output inspection establishes the same tip-plus-ring/sleeve-common source
topology as the UMC202HD, so repeating the isolated cable map would add no
useful evidence. Gate C will instead measure the complete UMC22 assembled
paths.

For the first Gate C stage, keep the UMC22 unpowered and USB disconnected;
keep the SU-V570 switched off with no loudspeaker connected; connect UMC22
Output 1 through that cable to `AUX` left; connect fixture red/`In+` and
black/`In-` to speaker-bank `B` left positive and negative respectively; and
connect the fixture output to `INST 2` through the passed breakout. With
auto-ranging resistance and nulled leads, measure from speaker `B` left positive
to the following nodes:

| Speaker `B` left positive to | Expected path | Result |
| --- | ---: | ---: |
| Breakout tip | approximately `9.13 kohm` through R1 | `9125 ohm` |
| Breakout ring | approximately `10.13 kohm` through R1 + R3 to common | `10127 ohm` |
| Breakout sleeve | approximately `10.13 kohm` through R1 + R3 to common | `10127 ohm` |
| UMC22 USB Type-B shell | approximately `10.13 kohm` through R1 + R3 to common | `10127 ohm` |

Stop for a hard or unexpectedly low path, instability, or unexplained polarity
sensitivity. Review this amplifier-positive isolation stage before completing
the low-resistance return map.

**VERIFIED GATE C POSITIVE-PATH MEASUREMENT - 2026-09-05:** the SU-V570 was
off with no loudspeaker connected. The fixture ran from speaker-bank `B` left
through the breakout to UMC22 `INST 2`; UMC22 Output 1 used the selected
TS-to-RCA cable into `AUX` left; and the UMC22 was USB-disconnected with
phantom off. The U1282A was in auto-ranging resistance mode with its leads
nulled before the first measurement. The four readings are recorded above.

The active-input path is the intended `9125 ohm` R1 resistance. Each return
reading adds exactly:

```text
10127 ohm - 9125 ohm = 1002 ohm
```

That is the fixture's measured R3 shunt. Ring, sleeve, and USB shell therefore
reach amplifier positive only through R1 plus R3; no low-resistance bypass is
present.

**GATE C PARTIAL DECISION - AMPLIFIER-POSITIVE ISOLATION PASS:** retain the
same unpowered assembly and map the deliberate common return from speaker-bank
`B` left negative to these nodes:

| Speaker `B` left negative to | Expected result | Result |
| --- | ---: | ---: |
| SU-V570 `AUX` left RCA shell | low resistance; previous amplifier result approximately `0.12-0.15 ohm` | `0.137 ohm` |
| Breakout ring | low resistance through the assembled playback return; broadly below `1 ohm` | `0.311 ohm` |
| Breakout sleeve | low resistance through the assembled playback return; broadly below `1 ohm` | `0.290 ohm` |
| UMC22 USB Type-B shell | low resistance through the assembled playback return; broadly below `1 ohm` | `0.299 ohm` |

These are topology checks, not precision milliohm measurements. Stop for an
open, unstable, or otherwise unexplained result. Gate C remains incomplete
until this return map is reviewed.

**VERIFIED GATE C RETURN-PATH MEASUREMENT - 2026-09-05:** in the unchanged
unpowered assembly, speaker-bank `B` left negative measured `0.137 ohm` to the
`AUX` left RCA shell, `0.311 ohm` to breakout ring, `0.290 ohm` to breakout
sleeve, and `0.299 ohm` to the UMC22 USB Type-B shell. No instability was
observed.

The `0.137 ohm` amplifier-local result lies within the previous
`0.12-0.15 ohm` range. The complete return paths are all below `0.32 ohm`; their
additional approximately `0.15-0.17 ohm` is consistent with the mapped
`0.078 ohm` playback-cable return plus interface, plug, breakout, and probe-
contact resistance. These are coherent topology results rather than precision
subtraction of remade milliohm contacts.

**GATE C DECISION - PASS:** the selected playback cable creates the intended
single low-resistance bond between UMC22 common and SU-V570 signal/speaker
ground. The fixture independently retains R1 in every amplifier-positive path,
and no unexplained hard active-signal path is present. Disconnect the complete
SU-V570 path before Gate D; amplifier power remains prohibited.

### 3.4 Gate D - Low-Voltage UMC22 Full-Duplex Checkout

At `48 kHz`, prove the actual UMC22 output channel, Input 1 microphone channel,
Input 2 reference channel, REW timing-reference mode, gain range, and dropout-
free operation without the powered amplifier. A direct or fixture-mediated
low-voltage loopback must remain below the UMC22 input maximum. Recreate any
soundcard calibration for this interface and rate; do not reuse UMC202HD
calibration or level settings. The historical UMC22 evidence is dropout-free
ordinary playback. In addition, a current matched five-minute media control on
this desktop produced zero audible dropouts with Microsoft `USBAUDIO.sys`
(`10.0.26100.8972`). Gate D later passed with an exact-routing, dropout-free
`256k` sweep using ordinary loopback timing. A valid UMC22 soundcard/electrical-
reference calibration route remains required before reusable acoustic-response
capture; that measurement-validity item is separate from Gate D's hardware,
stream, and timing qualification.

The rear-output contact topology is already established by direct PCB
inspection: tip is the signal contact and ring/sleeve are one common return.
The selected playback cable's existing map is also reusable. Gate D therefore
need not repeat either isolated investigation, but it must prove the actual REW
output channel, level, input paths, timing mode, and dropout-free sweep
operation.

#### 3.4.1 Amplifier-Disconnected No-Signal Check

In this section, *source adaptor* means the already-built and mapped TRS-to-
fixture-input adaptor originally called the `Output 2 source adaptor` during
UMC202HD fixture commissioning. It is not the breakout cable and it does not
bypass the clamp/attenuator. Its TRS tip connects to fixture red/`In+`, its
sleeve connects to fixture black/`In-`, and its ring is unconnected. Its passed
map is tip-to-`In+` `0.400 ohm`, sleeve-to-`In-` `0.370 ohm`, and every
prohibited path open.

The complete Gate D loopback is:

```text
UMC22 Output 1
  -> passed source adaptor
  -> fixture red/In+ and black/In-
  -> complete 9.1 kohm / 1 kohm clamp-attenuator
  -> fixture TRS output
  -> passed breakout (meter access only)
  -> UMC22 INST 2
```

This is therefore an approximately `-20 dB` protected loopback. Do not connect
Output 1 directly to `INST 2` for this stage.

1. Disconnect both the fixture and playback cable completely from the
   SU-V570. Leave the amplifier off and connect no loudspeaker.
2. With UMC22 USB disconnected and phantom off, set `OUTPUT`, `GAIN 1`, and
   `GAIN 2` fully down and set `DIRECT MONITOR` off.
3. Leave Input 1, Output 2, and the headphone socket empty.
4. Insert the passed source adaptor into UMC22 Output 1. Its tip feeds fixture
   `In+`, sleeve feeds `In-`, and ring remains unconnected. Connect the fixture
   output to `INST 2` through the passed breakout.
5. Connect the same known-good USB cable and desktop USB path used for the
   zero-dropout media control. Keep all software audio stopped.
6. Observe for an unexpected clip indication or other instability. In DC-
   voltage mode, measure breakout tip-to-sleeve for approximately `10 s`.

| No-signal observation | Result |
| --- | ---: |
| Breakout tip-to-sleeve DC | initial `0.0015 V`, settled to `0.0000 V` after approximately `15 s` |
| UMC22 clip indication or instability | none observed |

Stop and disconnect USB for sustained or unstable DC above `0.1 V`, a clip
indication, unexpected sound, heat, smell, or other abnormal behaviour. Do not
open REW or generate a signal until this no-signal state is reviewed.

**VERIFIED GATE D NO-SIGNAL MEASUREMENT - 2026-09-05:** in the documented
amplifier-disconnected, fixture-attenuated loopback, breakout tip-to-sleeve
started at `0.0015 V DC` and settled to `0.0000 V DC` after approximately
`15 s`. No clipping indication or abnormal behaviour was observed. The initial
magnitude is approximately `0.1 / 0.0015 = 66.7` times below the stop threshold,
and there is no sustained DC.

**GATE D NO-SIGNAL DECISION - PASS:** retain the unchanged hardware and USB
connection. REW may now be opened for no-excitation `48 kHz` routing setup, but
do not use Generator, Check Levels, or Measure until that routing is reviewed.

#### 3.4.2 REW Routing Setup Without Excitation

Use the Microsoft USB-audio path already selected for the UMC22. In REW
`Preferences -> Soundcard`, select the UMC22/USB Audio CODEC as both input and
output and select `48 kHz`. Do not inherit a UMC202HD or different-rate
soundcard-calibration file. Before excitation, record the exact REW driver,
input/output device names, and available channel names; then establish Input 1
as measurement left, Input 2 as reference right, and Output 1 as measurement
left. Keep every signal command stopped while inspecting these controls.

**VERIFIED REW DEVICE STATE - 2026-09-05:** REW uses driver type `Java` with
`EXCL: Behringer UMC22 (USB Audio CODEC)` selected for both input and output.
Available output channels are `L`, `R`, and `L+R`; available input channels are
`L` and `R`; the selected rate is `48 kHz`; and soundcard calibration is
`None`. This is the intended native Microsoft USB-audio, exclusive-mode,
two-input/two-output basis for the checkout.

**DEVICE-ENUMERATION DECISION - PASS:** output `L` is the measurement output to
physical Output 1, input `L` is the measurement input from physical Input 1,
and input `R` is the loopback/reference input from `INST 2`. `Use loopback as
cal and timing reference`, `Merge loopback response into IR`, and timing offset
`0.0000 ms` were selected without excitation. The screenshot also retained
reference output `R` while physical Output 2 was empty. That last assignment
was not electrically proved at this stage and is superseded by the live timing
correction below.

**VERIFIED NO-EXCITATION CHANNEL/TIMING UI ASSIGNMENT - 2026-09-05:** screenshots of Soundcard
Preferences and the Measure panel confirm output `L`, measurement input `L`,
timing-reference output `R`, loopback/reference input `R`, `Use loopback as cal
and timing reference`, `Merge loopback response into IR`, timing offset
`0.0000 ms`, `48 kHz`, and calibration `None`. Output 2 remains physically
empty. This records the UI state that passed without excitation; the reference-
output choice was later shown to be invalid for the actual wiring and is
superseded below.

The screenshots also showed two inherited setup details to correct before the
first signal. `Control input volume` was enabled at `0.25`; unity (`1.00`)
avoids digital attenuation of both captured channels before the physical UMC22
gain controls are set. The dormant measurement also retained the stale name
`SB17 UMC202HD checkout 1` and an exact-Nyquist `24 kHz` endpoint.
REW documents that Windows Java uses 16-bit data, so the inherited `Treat
32-bit data as 24-bit` check box is immaterial on this path and need not become
a separate test. See [REW Soundcard Preferences](https://www.roomeqwizard.com/help/help_en-GB/html/soundcard.html).

**VERIFIED PRE-EXCITATION SETTINGS - 2026-09-05:** the user confirms that
`Control input volume` is now `1.00`, the measurement is named `UMC22
low-voltage loopback 1`, and the sweep range is `20-20000 Hz`. The first-checkout
settings remain `-20 dBFS`, `1M`, one repetition, and timing offset `0.0000 ms`.
This establishes configuration only; no excitation or sweep result is inferred.

**PRE-EXCITATION SETTINGS DECISION - PASS:** with the amplifier still fully
disconnected, Gate D may advance to one bounded `1 kHz` level-setting tone
through the protected fixture loopback:

1. Keep phantom off, `GAIN 1`, `GAIN 2`, and the physical `OUTPUT` control fully
   down. Keep Input 1, Output 2, and the headphone socket empty.
2. Without moving the loopback wiring, place the true-RMS meter across breakout
   tip-to-sleeve in AC-voltage mode.
3. In REW Generator select sine, `1 kHz`, output `L`, and `-20 dBFS`. Start the
   tone with the physical `OUTPUT` control still fully down.
4. Raise only `OUTPUT` slowly to a target of approximately `0.020 V RMS` at the
   breakout; `0.018-0.022 V RMS` is close enough and avoids needless knob
   chasing. Stop immediately at `0.050 V RMS`, any clip indication,
   dropout/instability, or other abnormal behaviour. If the target cannot be
   reached at maximum `OUTPUT`, do not increase the digital level; record the
   maximum instead.
5. Hold the achieved level for approximately `30 s`, stop Generator, then
   record the stable voltage, approximate `OUTPUT`-control position, and any
   clip indication, dropout, or abnormality.

The `0.020 V RMS` target is approximately `33.8 dB` below the published
`0.976 V RMS` input maximum:

```text
20 log10(0.976 / 0.020) = 33.8 dB
```

It corresponds to only approximately `0.202 V RMS` at the fixture input under
the resistance-derived `0.09892` transfer ratio. This is a proportionate first
AC check, not the Gate D sweep and not authorization to power the amplifier.

**VERIFIED CONTROLLED AC LEVEL - 2026-09-05:** with the amplifier absent and
the protected loopback unchanged, the breakout tip-to-sleeve voltage reached
`0.0207 V RMS` with the UMC22 `OUTPUT` control at approximately 3 o'clock
(estimated by the user as about 80% of its travel). During the observation it
wandered slowly between `0.0205 V RMS` and `0.0210 V RMS`. No clip indication,
dropout, or other abnormality was observed.

The full observed voltage span is only:

```text
20 log10(0.0210 / 0.0205) = 0.21 dB
```

That slow approximately `0.21 dB` end-to-end movement is immaterial for this
bounded level check and is distinct from an abrupt stream dropout. Even the
highest observed level remains approximately `33.3 dB` below the UMC22's
published `0.976 V RMS` instrument-input maximum.

**CONTROLLED AC-LEVEL DECISION - PASS:** leave the `OUTPUT` position unchanged
and keep the amplifier disconnected. Set the reference-channel ADC level before
attempting the Gate D sweep:

1. Keep phantom off, `GAIN 1` fully down, Input 1 empty, and all hardware and
   routing otherwise unchanged. Leave the true-RMS meter across breakout
   tip-to-sleeve in AC-voltage mode.
2. Open REW's Level Meters so both `In` and `Ref In` are visible. Restart the
   same output-L, `1 kHz`, `-20 dBFS` sine; the external meter must remain below
   the existing `0.050 V RMS` stop limit.
3. Raise only UMC22 `GAIN 2` slowly until the `Ref In` RMS level is in the
   approximate `-24` to `-18 dBFS` range. A sine-wave peak should then be about
   `3 dB` higher. Do not chase an exact value.
4. Stop immediately if `Ref In` peak reaches `-6 dBFS`, the front-panel clip
   indicator illuminates, the external voltage changes unexpectedly, or any
   dropout/instability or other abnormality occurs. If maximum `GAIN 2` cannot
   bring `Ref In` above `-30 dBFS`, stop and record that result rather than
   raising output level.
5. After approximately `10 s` of stable indication, stop Generator and record
   `Ref In` RMS and peak levels, approximate `GAIN 2` position, the external
   AC voltage, and any abnormality. Do not use Check Levels or Measure yet.

REW's Level Meters show RMS as the lower numeric value and peak as the upper
numeric value; see [REW Level Meters](https://www.roomeqwizard.com/help/help_en-GB/html/vumeters.html).

**LIVE REFERENCE-CAPTURE HOLD - 2026-09-05:** with the externally verified
approximately `0.0207 V RMS` tone still reaching physical `INST 2`, moving
UMC22 `GAIN 2` across its complete range produced no change in REW's `Ref In`
bargraph. A Preferences screenshot shows output `L` active at `-20.00 dBFS`,
measurement input `L`, loopback input `R`, and both `In` and `Ref In` at the
approximately `-93.72 dBFS` noise floor. It also shows the output device with
the `EXCL:` prefix but the current input device without it, contrary to the
earlier reported exclusive-device selection for both directions. This does not
invalidate the external AC-level pass, but the actual Java/USB input endpoint
and channel map are not yet proved. The earlier channel/timing decision is
therefore only a **no-excitation UI-assignment pass**, not a live reference-
capture pass.

Do not permanently change the main measurement input to `R` merely because
physical `INST 2` is expected to be the right channel: the main `Input` selector
is intended for the future Input 1 microphone, while the separate `Loopback
input` selector is intended for Input 2. First restore or disprove the earlier
exclusive-input selection with the amplifier absent:

1. Stop Generator and return `GAIN 2` fully down. Keep the DMM connected and all
   hardware unchanged.
2. Open the `Input device` list. If the exact `EXCL: Behringer UMC22 (USB Audio
   CODEC)` entry is available, select it. Retain main input `L`, loopback input
   `R`, `48 kHz`, and input volume `1.00`; report if any of those options change
   or disappear.
3. Restart the same output-L, `1 kHz`, `-20 dBFS` tone and move `GAIN 2` only
   far enough to determine whether `Ref In` now follows it. Retain the
   `0.050 V RMS`, `-6 dBFS`, clipping, and abnormality stop limits.
4. Stop Generator and report the exact selected input-device name, whether
   `Ref In` saw the tone, and whether it followed `GAIN 2`.

If no `EXCL:` input endpoint is available, or selecting it does not restore
capture, stop there. A temporary main-input `R` test will then distinguish a
channel-map problem from an endpoint/capture problem without increasing the
analogue level.

**LIVE REFERENCE-CAPTURE RESOLUTION - PASS, 2026-09-05:** the non-exclusive
input endpoint was the complete cause of the apparent failure. Selecting
`EXCL: Behringer UMC22 (USB Audio CODEC)` immediately restored `Ref In` capture,
and its indicated level then followed `GAIN 2` linearly in decibels over the
control range. No main-input channel swap was required. This supersedes the
hold above while retaining it as useful diagnostic history.

`GAIN 2` is now set for a stable `Ref In` RMS level of `-20.88 dBFS`, fluctuating
by only approximately `0.01 dB`. The external tip-to-ring voltage is steady at
`0.0218 V RMS`. Gate A established that ring and sleeve are the same Input 2
return node, so this tip-to-ring reading is equivalent to the earlier tip-to-
sleeve reference for present purposes. It is approximately `0.45 dB` above the
earlier `0.0207 V RMS` reading and still approximately `33.0 dB` below the
published `0.976 V RMS` input maximum; neither difference warrants retuning the
output level.

**REFERENCE-CHANNEL LEVEL DECISION - PASS:** retain the exact exclusive input
and output endpoints, `GAIN 2`, `OUTPUT`, `48 kHz`, input volume `1.00`, and L/R
assignments. Input 1/USB-L must now be proved independently with the microphone
before the full-duplex sweep gate can close. The amplifier remains absent and
unapproved.

For the Input 1 microphone-channel check:

1. Stop Generator. Do not move `OUTPUT` or `GAIN 2`; note the approximate
   `GAIN 2` knob position for the record. Keep the SU-V570 fully disconnected.
2. With phantom off and `GAIN 1` fully down, connect the ECM8000 to Input 1 by
   its normal XLR cable. Keep the existing protected Input 2 loopback connected.
3. Enable `+48 V`, confirm the phantom indicator illuminates, and wait about
   `15 s`. Stop for any clip indication, instability, heat, smell, or other
   abnormality.
4. With Generator still stopped, observe REW's main `In` meter while speaking
   normally near the microphone or rubbing fingers near it; do not strike the
   microphone. Raise only `GAIN 1` enough to show a clear input response and
   confirm that the indicated level follows the control.
5. Avoid peaks above `-12 dBFS` for this mapping check. Return `GAIN 1` fully
   down, then report the approximate noise-floor and stimulus levels, whether
   they followed `GAIN 1`, the phantom/clip indications, the retained `GAIN 2`
   position, and any abnormality. Do not run Check Levels or Measure yet.

**VERIFIED INPUT 1 MICROPHONE-CHANNEL CHECK - 2026-09-05:** `GAIN 2` remains
between approximately 3 and 4 o'clock. With `GAIN 1` at minimum, REW `In`
indicated approximately `-83 dBFS`, usually moving by about `+/-3 dB` and
occasionally reaching about `-76 dBFS`. With `GAIN 1` raised to approximately
2 o'clock, the indicated background averaged roughly `-56 dBFS`, usually moving
by about `+/-4 dB`, while nearby speech reached approximately `-18 dBFS`.
Speech, finger clicks, and other nearby test sounds all produced the expected
response. No clipping or abnormality was observed.

The room was not silent: a PC case fan was continuous, with intermittent
birdsong and aircraft audible outside. These readings therefore establish
microphone-channel function and gain response, not the UMC22's intrinsic input-
noise performance. The approximately `27 dB` shift in indicated background
between minimum gain and the raised setting, together with the local-sound
response, proves the intended Input 1/USB-L route.

**INPUT 1 MICROPHONE-CHANNEL DECISION - PASS:** both ADC channels, their
physical gain controls, and the intended REW L/R assignments now respond. A
coherent acoustic signal must still reach the microphone during the first
full-duplex sweep. Use the UMC22 headphone output as a low-energy temporary
source if known-good wired headphones or earbuds are available; this is a
functional checkout, not reusable acoustic-response evidence:

1. Keep the SU-V570 fully disconnected. Stop Generator, keep phantom on and the
   ECM8000 connected, return `GAIN 1` fully down, and do not move `OUTPUT` or
   `GAIN 2`. Retain the DMM across breakout tip-to-ring in AC-voltage mode.
2. With no signal playing and with the headphones **not worn**, connect known-
   good wired stereo headphones or earbuds to the UMC22 headphone socket. Place
   the left earpiece initially about `100 mm` from the microphone capsule and
   keep the right earpiece farther away.
3. Restart the same output-L, `1 kHz`, `-20 dBFS` sine. Confirm that `Ref In`
   remains near `-20.88 dBFS` and that the external reference remains stable
   and below `0.050 V RMS`.
4. Raise only `GAIN 1`, or reduce the earpiece-to-capsule distance, until main
   `In` RMS is approximately `-24` to `-18 dBFS`. Do not change `OUTPUT` or
   `GAIN 2`, and do not chase an exact value.
5. Stop immediately for either input peak at or above `-6 dBFS`, any clip
   indication, reference-voltage instability, dropout, or other abnormality.
   After about `10 s` of stable indication, stop Generator and record `In` and
   `Ref In` levels, external voltage, `GAIN 1` position, approximate earpiece
   distance, and observations. Do not run Measure yet.

If no suitable headphones or earbuds are available, stop here rather than
substituting an unqualified powered device.

**VERIFIED HEADPHONE-TO-MICROPHONE LEVEL SETUP - 2026-09-05:** with the left
earpiece approximately `150 mm` from the ECM8000, `GAIN 1` between approximately
2 and 3 o'clock, and the retained `GAIN 2` between approximately 3 and 4
o'clock, REW indicated:

| Channel/point | Indication |
| --- | ---: |
| Main `In` RMS | `-19.5 dBFS`, very stable; occasional movement to approximately `-19 dBFS` |
| `Ref In` RMS | `-20.84 dBFS`, very stable within approximately `+/-0.01 dB` |
| Breakout tip-to-ring | steady `0.0230 V RMS` |

No clipping, dropout, or other abnormality was observed. A separate numeric
sample-peak result was not reported; for undistorted sine waves the RMS figures
imply peaks of approximately `-16.5 dBFS` and `-17.8 dBFS` respectively, leaving
ample margin. The two RMS channel levels differ by only `1.34 dB`.

The external reference is approximately `0.46 dB` above the preceding
`0.0218 V RMS` observation and remains approximately `32.6 dB` below the
published `0.976 V RMS` instrument-input maximum:

```text
20 log10(0.0230 / 0.0218) = 0.46 dB
20 log10(0.976 / 0.0230) = 32.6 dB
```

This small, stable change after adding the headphone load does not justify
retuning either level control.

**FULL-DUPLEX LEVEL-SETUP DECISION - PASS:** retain all controls, endpoint and
channel assignments, the microphone/earpiece geometry, and the protected
reference wiring. One amplifier-disconnected sweep may now be run:

1. Keep the headphones unworn, the SU-V570 fully disconnected, the microphone
   and phantom supply active, and every physical control unchanged. Secure the
   breakout and meter leads so they cannot contact another node.
2. Before starting, confirm both input and output devices are the exact `EXCL:
   Behringer UMC22 (USB Audio CODEC)` endpoint at `48 kHz`; measurement output
   and input are `L`; reference input is `R`; loopback-as-cal-and-timing and IR
   merge are selected; timing offset is `0.0000 ms`; and soundcard calibration
   is `None`. The first sweep historically retained reference output `R`; that
   setting is superseded by the correction below.
3. Confirm measurement name `UMC22 low-voltage loopback 1`, range
   `20-20000 Hz`, level `-20 dBFS`, length `1M`, and one repetition. Do not run
   Check Levels or alter a gain to satisfy a new prompt.
4. Start exactly one measurement. Do not move either earpiece or microphone.
   Abort for any clip warning/indicator, timing-reference failure, dropout,
   discontinuous sound, USB error, or other abnormality. Do not raise any level
   if REW reports a weak frequency extreme.
5. When the sweep ends, do not run a repeat yet. Record whether it completed,
   every warning, the reported System Delay, any visible clipping indication,
   and whether the impulse has one clear dominant arrival rather than several
   comparable peaks. This headphone response is functional gate evidence, not
   reusable loudspeaker FRD data.

**VERIFIED FIRST FULL-DUPLEX SWEEP EXECUTION - 2026-09-05:** the single
amplifier-disconnected `1M`, `20-20000 Hz`, `-20 dBFS` headphone-to-microphone
sweep completed successfully. REW produced no warning or error; no interface
clip indicator illuminated; no discontinuity was heard; and no other
abnormality was reported.

The supplied Impulse screenshot shows one unmistakable dominant red arrival at
approximately `t = 0`, followed by a much lower decaying response that trends
toward the noise floor. It does not show several comparable impulse peaks. The
blue curve and the green `R` marker at approximately `500 ms` are the applied
impulse-window overlay and right-window marker, not additional measured
arrivals. At this broad `-100 ms` to `1 s` view, the approximately `0.44 ms`
air-travel time for the nominal `150 mm` earpiece distance would appear very
close to zero, so the displayed peak position is physically plausible.

**SWEEP-EXECUTION DECISION - PASS FOR STREAM STABILITY ONLY:** this is the first
verified dropout-free REW full-duplex sweep on the UMC22 and closes the
principal stream-stability uncertainty. Gate D timing validity remained open
pending the stored measurement metadata. With the measurement selected,
`Tools -> Info` (`Ctrl+N`) exposes `System Delay`, `Timing offset`, `Timing ref
mode`, and `Clock adjustment`.
REW documents `System Delay` in the measurement Info panel; see
[Making Measurements](https://www.roomeqwizard.com/help/help_en-GB/html/makingmeasurements.html)
and the [`Tools -> Info` command](https://www.roomeqwizard.com/help/help_en-GB/html/tools.html).

**VERIFIED FIRST-SWEEP TIMING METADATA - 2026-09-05:** the Info panel records:

| Field | Stored result |
| --- | --- |
| Peak | `0.4292 ms` |
| IR start | `0.3750 ms` (`129 mm`, `5.06 in`) |
| Timing ref index | `N/A` |
| System Delay | `Not available` |
| Timing offset | `N/A` |
| Clock adjustment | `0.0 ppm` |
| Timing ref mode | `Loopback as cal ref` |
| Timing ref output | `R` |
| Timing ref input | `MICROPHONE (Master Volume) R` |

The Info panel proves that the requested mode was stored but a timing-reference
event was not acquired: `Timing ref index` is `N/A`, so `System Delay` cannot be
calculated. The reason is now explicit. The protected reference input receives
physical UMC22 Output 1, USB output `L`, while REW was told to emit its timing-
reference signal on output `R`; physical Output 2/R was intentionally empty.
The loopback input could capture the main L sweep for response correction, but
not the timing event emitted on the unconnected R output.

The untimed result's `0.3750 ms` IR start corresponds to approximately `129 mm`
at `343 m/s`, and its `0.4292 ms` peak corresponds to approximately `147 mm`,
both physically consistent with the nominal `150 mm` earpiece distance. That is
a useful sanity check but does not replace a valid loopback System Delay.

**CORRECTED TIMING-ROUTING DECISION - 2026-09-05:** this mismatch came from the
documented setup, not a user wiring error. For this amplifier-output-reference
topology, both measurement output and timing-reference output must be `L`,
because that is the single physical output sensed by the fixture. Measurement
input remains `L` and loopback/reference input remains `R`. One repeat is
necessary and sufficient:

1. Stop all signals and leave every physical connection and control unchanged.
2. Change only `Timing reference output` from `R` to `L`. Retain measurement
   output `L`, measurement input `L`, loopback input `R`, both `EXCL:` devices,
   `48 kHz`, loopback-as-cal-and-timing, IR merge, and `0.0000 ms` offset. If REW
   will not permit measurement output and reference output both to be `L`, stop
   and report that rather than rewiring anything.
3. Briefly restart the `1 kHz`, `-20 dBFS` tone. Verify both input levels remain
   in their established ranges and tip-to-ring remains below `0.050 V RMS`;
   stop for any unexpected level increase, clipping, or abnormality. Stop the
   tone after the check.
4. Name the repeat `UMC22 low-voltage loopback timing-fixed`, retain
   `20-20000 Hz`, `-20 dBFS`, `1M`, and one repetition, then run exactly one
   sweep without moving anything or changing a gain.
5. Record warnings/errors, clipping/dropouts, and the new Info-panel `Timing ref
   index`, `System Delay`, `Timing offset`, `Clock adjustment`, `Timing ref
   mode`, output, and input. Do not alter or rerun the first measurement.

**VERIFIED CORRECTED-ROUTING UI BEHAVIOUR - 2026-09-05:** REW accepted `L` as
both the measurement and timing-reference output. On starting the measurement
it displayed `Ref output is the same as measurement output` and explained that
the outputs would usually differ for a loopback timing reference. This warning
is expected in the present topology: the protected Input 2 reference is
deliberately a sample of the same physical Output 1/L that supplies the
measurement stimulus. Select `Yes` without rewiring or changing a gain, provided
the immediately preceding external AC check is still below `0.050 V RMS` and
shows no abnormality. The user subsequently confirmed that the latest reading
was `0.0222 V AC` (`22.2 mV AC`), not `0.0222 mV AC`; it therefore remained
comfortably inside the established range.

**VERIFIED SECOND FULL-DUPLEX SWEEP EXECUTION - 2026-09-05:** the corrected-
output `1M`, `20-20000 Hz`, `-20 dBFS` sweep completed with no warning other
than the expected same-output confirmation, and with no clipping or dropout.
Its Info panel records:

| Field | Stored result |
| --- | --- |
| Name | `UMC22 low-voltage loopback fixed` |
| Peak | `0.0002 ms` |
| IR start | `-0.0417 ms` (`-14 mm`, `-0.56 in`) |
| Timing ref index | `N/A` |
| System Delay | `Not available` |
| Timing offset | `N/A` |
| Clock adjustment | `0.0 ppm` |
| Timing ref mode | `Loopback as cal ref` |
| Timing ref output | `L` |
| Timing ref input | `MICROPHONE (Master Volume) L` |

This second sweep is further dropout-free full-duplex evidence, but it is not
valid response, phase, or timing evidence. The stored reference input is the
same Input 1/L microphone channel used for the measurement instead of the
fixture signal on Input 2/R. Merging a channel with itself as the loopback
calibration reference naturally produces the reported almost-unity, almost-
flat magnitude and phase, while no independent timing reference can be found.
The flat trace is therefore diagnostic of the input-selection error, not a
measured headphone response.

**EXACT-ROUTING REPEAT DECISION - 2026-09-05:** one further amplifier-
disconnected sweep is necessary and sufficient. Keep all wiring, physical gain
controls, level, frequency range, sweep length, and sample rate unchanged. In
the Measure window set and visually verify all four selectors together:

| Role | Required channel |
| --- | --- |
| Measurement output | `L` |
| Timing-reference output | `L` |
| Measurement input | `L` |
| Loopback/reference input | `R` |

The exact `EXCL:` UMC22 input and output devices must remain selected. Name the
measurement `UMC22 low-voltage loopback timing-fixed Rref`, start one sweep,
and accept the same-output warning with `Yes`. Stop if either input meter is
abnormal, but do not alter a gain merely to optimise an immaterial fraction of
a decibel. Afterward record the Info-panel fields listed above and confirm that
`Timing ref input` is `MICROPHONE (Master Volume) R` before treating any graph
or System Delay as valid.

**VERIFIED REW EXCEPTION AND POST-RESTART SETTINGS AUDIT - 2026-09-05:** when
the Measure-window reference input was changed to `R` after the invalid self-
referenced sweep, REW V5.40 beta 133 raised this exception before a further
valid measurement was established:

```text
java.lang.ArrayIndexOutOfBoundsException: Index 1 out of bounds for length 1
    roomeqwizard.audio.Q.A(y:1251)
    roomeqwizard.audio.Q.run(y:1499)
```

REW was restarted. The three post-restart screenshots then show the following
coherent state:

| Area | Verified setting | Decision |
| --- | --- | --- |
| Soundcard | Java; exact `EXCL:` UMC22 input and output; `48 kHz`; both buffers `32k` | PASS |
| Soundcard routing | output L; timing-reference output L; measurement input L; loopback input R | PASS |
| Soundcard options | virtual balanced, invert, high-pass, and output-volume control off; input-volume control on at `1.00`; calibration `None` | PASS for this gate |
| Java channel request | `Stereo only` off | Not intrinsically invalid, but the only visible setting directly relevant to forcing a two-channel capture |
| Analysis | automatic IR widths; no FDW/MTW; loopback delay reference at IR peak; no loopback clock adjustment; align IR peak and t=0 to a sample | PASS for the full-range headphone check |
| Measure | SPL sweep; `1M`; one repetition; loopback as calibration/timing reference; merge loopback response; zero offset; From REW; single measurement; `20-20000 Hz`; `-20 dBFS`; output/ref-output L; input L; ref-input R | PASS |

`Adjust clock with acoustic ref` is enabled but is inactive in the selected
loopback-reference mode. Leaving `Adjust clock with loopback` off is appropriate
because UMC22 playback and capture share the same hardware clock. `Control input
volume` at unity is not evidence of the exception and is retained for the next
attempt so that only one variable changes.

The exception's attempted index `1` in an array of length `1` is consistent with
REW trying to access the right channel while a live Java capture object still
contained only a mono channel. The obfuscated stack trace does not prove that
internal cause, but the interpretation matches both the preceding one-input
self-reference state and the fact that a restart accepted the correct `R`
selection. It does not indicate a UMC22 electrical fault.

**STEREO-CAPTURE RETRY DECISION - 2026-09-05:** with all signals stopped and
the amplifier still absent, select `Stereo only` in Soundcard Preferences. If
REW refreshes its device lists, reselect the exact `EXCL:` UMC22 input and
output, then reverify the L/L/L/R matrix. Do not alter input volume, either
physical gain, wiring, or sweep level. Briefly run the established output-L
`1 kHz`, `-20 dBFS` tone and confirm that `Ref In` again receives Input 2/R,
the main input remains normal, and the external reference stays below
`0.050 V RMS`; then stop the tone. If that passes, run the one exact-routing
`1M` sweep and accept the expected same-output warning. If the same exception
recurs, stop without another sweep, retain the stack trace, and use `Generate
debug file...` for a REW bug report; do not continue changing settings blindly.

**VERIFIED STEREO-CAPTURE EXACT-ROUTING RESULT - 2026-09-05:** after enabling
`Stereo only`, the next sweep completed and the preceding channel-index
exception did not recur. The Info panel proves that REW stored the intended
reference routing rather than either earlier erroneous assignment:

| Field | Stored result |
| --- | --- |
| Peak | `0.5100 ms` |
| IR start | `0.4792 ms` (`164 mm`, `6.47 in`) |
| Timing ref index | `N/A` |
| System Delay | `Not available` |
| Timing offset | `N/A` |
| Clock adjustment | `0.0 ppm` |
| Timing ref mode | `Loopback as cal ref` |
| Timing ref output | `L` |
| Timing ref input | `MICROPHONE (Master Volume) R` |

At `343 m/s`, the peak and start correspond to approximately `175 mm` and
`164 mm` respectively:

```text
343 m/s * 0.0005100 s = 0.1749 m
343 m/s * 0.0004792 s = 0.1644 m
```

Those values are physically plausible for the nominal `150 mm` earpiece-
capsule spacing, but that sanity check alone cannot prove stable loopback-
referenced timing. The result eliminates a stored L/R assignment error and
shows that forcing stereo prevented the exception, but it does not explain why
REW withheld the timing metadata. Absence of a separately reported warning,
clip, or dropout for this attempt is not silently inferred from completion.

**SCOPE CORRECTION AND TIMING-ONLY DIAGNOSTIC DECISION - 2026-09-05:** the
previously proposed `Captured`/`Ref Captured` inspection is withdrawn. Current
REW Scope is a live two-channel oscilloscope; it does not expose the preceding
measurement's raw capture buffers. The absence of those selector entries is
expected and is not a user setting error. A live Scope run would merely repeat
the already-established fact that Input 2/R responds to the low-voltage tone,
so it has insufficient additional value.

The next proportionate discriminator is one short amplifier-disconnected A/B
sweep. Keep the current physical wiring, `OUTPUT`, `GAIN 1`, `GAIN 2`, exact
`EXCL:` devices, `48 kHz`, `Stereo only`, measurement output L, reference output
L, measurement input L, reference input R, `20-20000 Hz`, `-20 dBFS`, and one
repetition unchanged. Change only the timing function from `Use loopback as cal
and timing reference` to ordinary `Use loopback as timing reference`; leave
`Merge loopback response into IR` off/inactive, select `256k`, and name the
measurement `UMC22 timing-only diagnostic`. Accept the same-output warning and
run the single sweep through the protected low-voltage loop.

This result is diagnostic rather than a calibrated FRD. Record warnings,
clipping/dropout observations, and the Info-panel timing-reference mode, output,
input, index, System Delay, timing offset, clock adjustment, peak, and IR start.
If a numeric System Delay appears, ordinary L/R loopback timing works and the
remaining problem is confined to the combined calibration/merge path. If timing
is still unavailable or another exception occurs, stop signal generation,
retain the measurement and a REW debug file, and take the issue to current REW
rather than continuing blind setting changes. Neither outcome authorises the
SU-V570 to be connected or powered.

**VERIFIED TIMING-ONLY DIAGNOSTIC - 2026-09-05:** the physical setup was
reconfirmed as the known-good desktop USB path; UMC22 Output 1/L through the
source adaptor, complete clamp/attenuator, and breakout to `INST 2`; ECM8000 to
`MIC / LINE 1`; headphones to the headphone socket; and phantom active. This is
the intended Gate D circuit. `DIRECT MONITOR` must remain off. The ECM8000
calibration file was not loaded, which is immaterial to this routing/timing
diagnostic but prevents its magnitude response from becoming reusable acoustic
evidence.

The `UMC22 timing-only diagnostic` completed with no warning, clipping,
dropout, exception, or other reported abnormality. Its Info panel records:

| Field | Stored result |
| --- | --- |
| REW | `V5.40 beta 133` |
| Excitation | `256k` log swept sine, one sweep at `-20.0 dBFS` |
| Frequency range | `20-20000 Hz` |
| Sample rate | `48000.0 Hz` |
| Timing ref mode | `Loopback` |
| Timing ref output | `L` |
| Timing ref input | `MICROPHONE (Master Volume) R` |
| Timing ref index | `47970.52` |
| System Delay | `0.6141 ms` (`211 mm`, `8.29 in`) |
| Timing offset | `0.0000 ms` |
| Clock adjustment | `0.0 ppm` |
| Peak | `0.6141 ms` |
| IR start | `0.5208 ms` (`179 mm`, `7.03 in`) |
| Signal-to-noise | `41.6 dB` |
| Signal-to-distortion | `70.5 dB` |
| Microphone calibration | None loaded |
| Soundcard calibration | None loaded |

At `343 m/s`, the independent time conversions agree with REW:

```text
343 m/s * 0.0005208 s = 0.1786 m = 179 mm
343 m/s * 0.0006141 s = 0.2106 m = 211 mm
```

The non-`N/A` reference index proves that REW detected the Input 2/R reference,
and the numeric System Delay proves that it referenced the acoustic Input 1/L
arrival to that capture. The result therefore establishes the intended
two-channel routing and ordinary loopback timing. The `0.0 ppm` adjustment is
also coherent with input and output sharing the UMC22 hardware clock.

**GATE D DECISION - PASS:** Gates A-D now qualify the UMC22 for the controlled
powered no-signal and `1.00 V RMS` woofer checks in Gate E. The earlier
`Loopback as cal ref` results remain invalid and show that beta 133's combined
loopback-calibration/IR-merge path is not presently qualified on this setup.
Gate D does not promote the timing-only trace to calibrated acoustic evidence.
Before a reusable powered sweep, load the appropriate ECM8000 calibration file
for the chosen microphone orientation and establish a valid UMC22/electrical-
reference magnitude-calibration route. Do not silently use `No cal file` data
for crossover design.

**CALIBRATION-ROUTE NEXT STEP - 2026-09-05:** before dismantling the successful
low-voltage setup or wiring the SU-V570, run one final `256k` A/B with all
physical controls, wiring, exact devices, sample rate, L/L/L/R routing,
frequency range, level, and repetition count unchanged. Select `Use loopback as
cal and timing reference`, but choose `Make calibration data from loopback
response` instead of `Merge loopback response into IR`. Name it `UMC22
loopback-cal-data diagnostic`. The ECM8000 calibration may remain unloaded for
this diagnostic so that only the reference treatment changes.

Record the same timing fields, warnings/clipping/dropout/exception state, and
whether the Info panel shows calibration data generated from the loopback. If
the reference index and numeric System Delay remain valid and the loopback
calibration data are created, this becomes the candidate mode for Gate E; load
the ECM8000 file before reusable acoustic capture. If timing again becomes
`N/A`, stop low-voltage testing and preserve the session plus a debug file for
current REW. Do not return to the already-failed IR-merge option.

**VERIFIED LOOPBACK-CAL-DATA DIAGNOSTIC - 2026-09-05:** the unchanged
amplifier-disconnected test completed with no warning or reported abnormality.
The headphone was held by hand at approximately `150 mm` from the microphone,
so differences of a few centimetres among inferred path lengths are expected
and are not repeatability evidence. The Info panel records:

| Field | Stored result |
| --- | --- |
| Name | `UMC22 loopback-cal-data diagnostic` |
| REW | `V5.40 beta 133` |
| Excitation | `256k` log swept sine, one sweep at `-20.0 dBFS` |
| Frequency range | `20-20000 Hz` |
| Sample rate | `48000.0 Hz` |
| Microphone calibration | None loaded |
| Soundcard calibration | `Loopback cal` |
| Timing ref mode | `Loopback as cal ref` |
| Timing ref output | `L` |
| Timing ref input | `MICROPHONE (Master Volume) R` |
| Timing ref index | `47975.52` |
| System Delay | `0.5100 ms` (`175 mm`, `6.89 in`) |
| Timing offset | `0.0000 ms` |
| Clock adjustment | `0.0 ppm` |
| Peak | `0.5100 ms` |
| IR start | `0.4375 ms` (`150 mm`, `5.91 in`) |
| Signal-to-noise | `43.5 dB` |
| Signal-to-distortion | `70.0 dB` |

The distance conversions again agree with REW:

```text
343 m/s * 0.0004375 s = 0.1501 m = 150 mm
343 m/s * 0.0005100 s = 0.1749 m = 175 mm
```

The IR start happens to match the hand-estimated spacing, while the peak is
approximately `25 mm` later. Neither figure should be treated as a precise
distance measurement because the acoustic source was hand-held. More
importantly, `Soundcard: Loopback cal` proves that REW generated calibration
data from Input 2/R, while reference index `47975.52` and the numeric System
Delay prove that the same capture also supplied timing.

**CALIBRATION-ROUTE DECISION - PASS:** for the UMC22 route, use `Use loopback as
cal and timing reference` with `Make calibration data from loopback response`.
Do not select `Merge loopback response into IR` on the present beta-133 setup.
This closes the amplifier-disconnected qualification and establishes the
candidate live electrical-reference treatment for Gate E. The separate ECM8000
calibration remains mandatory before any reusable acoustic-response sweep.

The raw Gate D REW session is retained as `UMC22 loopback-cal-data
diagnostic.mdat` (`2,426,614` bytes as observed on 2026-09-05). It is
qualification/debug evidence, not loudspeaker FRD. It was committed with the
completed qualification record at the user's request; do not treat it as
disposable generated output.

### 3.5 Gate E - Controlled Powered Woofer Checkout

Only after Gates A-D pass, adapt the switched-off connection and minimum-volume
startup in the now-superseded procedure retained in
[`FRD_REPEATABILITY_DEVELOPMENT_2026-09-03_TO_05.md`](FRD_REPEATABILITY_DEVELOPMENT_2026-09-03_TO_05.md) to
the documented UMC22 contacts. Use the woofer only. Confirm no-signal behaviour,
raise the woofer to `1.00 V RMS`, confirm a gross reference level near
`0.10 V RMS` without clipping, then complete three unmoved repeats. The final
reference level may differ slightly if the verified UMC22 input topology makes
the fixture operate single-ended; record and use the measured result.

#### 3.5.1 Switched-Off Transition To The Full-Dual Circuit

Gate D and the calibration-data route now pass, but do not power either device
while changing topology:

1. Save the useful Gate D measurements, stop every REW signal, turn phantom off,
   wait approximately `15 s`, and disconnect UMC22 USB.
2. Turn UMC22 `OUTPUT`, `GAIN 1`, and `GAIN 2` fully down. Keep `DIRECT MONITOR`
   off. Disconnect the headphones and remove the temporary Output 1 source-
   adaptor connection used for Gate D.
3. Confirm the SU-V570 is off with volume fully down. Select `AUX`, keep `POWER
   AMP DIRECT` off so the normal input selector remains active, centre the
   balance, disable tone/loudness processing, and select speaker bank `B` only.
4. Connect UMC22 Output 1 through the passed TS-to-RCA cable to SU-V570 `AUX`
   left. Leave UMC22 Output 2 and the amplifier's right input unused.
5. Connect only the woofer to SU-V570 speaker-bank `B` left. Keep the tweeter
   electrically disconnected.
6. At the same `B`-left amplifier terminals, connect fixture red/`In+` to
   positive and black/`In-` to negative. Retain the passed breakout between the
   fixture output and UMC22 `INST 2`, with the terminal block restrained and
   insulated.
7. Keep the ECM8000 connected to `MIC / LINE 1` by XLR. Do not enable phantom,
   reconnect USB, or power the SU-V570 yet.

Report this complete switched-off state before proceeding. The next reviewed
stage will power the UMC22 first, restore microphone phantom, confirm no clip or
abnormality, and only then perform the SU-V570 minimum-volume no-signal startup.

**VERIFIED PARTIAL SWITCHED-OFF GATE E STATE - 2026-09-05:** the user reports
the following coherent state:

- UMC22 USB disconnected; phantom off; `GAIN 1`, `GAIN 2`, and `OUTPUT` at
  minimum; `DIRECT MONITOR` off;
- ECM8000 connected to `MIC / LINE 1`;
- `INST 2` connected through the passed breakout and complete fixture to
  SU-V570 speaker-bank `B` left;
- UMC22 Output 1/L connected to SU-V570 `AUX` left;
- SU-V570 off with volume minimum, `AUX` selected, balance centred, tone
  `DEFEAT`, loudness off, bank B enabled, and bank A disabled.

Those reported controls and paths pass. Before USB or amplifier power, confirm
the load and connector details not explicitly included in the report: the
woofer alone is connected to B-left and the tweeter is disconnected; fixture
red/`In+` is on B-left positive and black/`In-` on B-left negative; the breakout
terminal block is restrained and insulated; and headphones, UMC22 Output 2, and
the amplifier right input are unused. The Gate E power-up remains held pending
those confirmations.

**VERIFIED COMPLETE SWITCHED-OFF GATE E STATE - 2026-09-05:** the remaining
connections are now explicit. SU-V570 B-left red/positive feeds both fixture
red/`In+` and woofer positive; B-left black/negative feeds both fixture
black/`In-` and woofer negative. No tweeter or other load is present. UMC22
Output 2, its headphone socket, and SU-V570 `AUX` right are empty. The breakout
terminal block is restrained and insulated so neither its contacts nor
associated conductors can touch a person or unintended object. The user's term
`breaker block` is interpreted here as that already-documented breakout
terminal block.

**SWITCHED-OFF CONNECTION DECISION - PASS:** the full-dual topology, load,
polarity, inactive controls, insulation, and unused sockets are now confirmed.
Keep the SU-V570 off at minimum volume. The next bounded stage is UMC22-only
power-up: keep all REW signals stopped and all UMC22 controls unchanged; connect
the known-good USB cable; then enable phantom for the already-connected ECM8000
and wait approximately `15 s`. Confirm that the phantom indicator illuminates
and report any clip indication, unexpected sound, instability, heat, smell, or
other abnormality. Do not power the SU-V570 yet.

**VERIFIED UMC22-ONLY USB/PHANTOM NO-SIGNAL OBSERVATION - 2026-09-05:** with
the SU-V570 off at minimum volume and all REW signals stopped, the known-good
USB cable was connected and phantom power was enabled without changing the
UMC22 controls or wiring. The phantom indicator illuminated. Neither channel
showed a clip indication; there was no unexpected sound, instability, smell,
heating, or other abnormality.

**UMC22-ONLY POWER-UP DECISION - PASS:** retain the unchanged full-dual wiring,
USB connection, active phantom supply, minimum UMC22 `GAIN 1`, `GAIN 2`, and
`OUTPUT` controls, and `DIRECT MONITOR` off. The next bounded stage is the
SU-V570 minimum-volume no-signal startup:

1. Keep every REW signal stopped. Do not use Generator, Check Levels, or
   Measure.
2. Reconfirm SU-V570 volume at minimum, `AUX` selected, tone `DEFEAT`, loudness
   off, balance centred, bank B enabled, and bank A disabled. Do not change any
   wiring while the amplifier is powered.
3. Switch on the SU-V570 without adjusting its volume or any UMC22 control.
4. Observe for approximately `15 s`. Report whether the woofer remains silent,
   whether either UMC22 channel shows a clip indication, and whether there is
   any unexpected sustained hum/buzz, transient sound, instability, unusual
   heating, smell, smoke, or other abnormality.
5. Switch the SU-V570 off immediately for sustained or otherwise concerning
   sound, clipping, instability, smell, smoke, unusual heating, or any other
   abnormality. Even after a clean observation, do not generate a signal or
   adjust a level until the result is reviewed.

**VERIFIED SU-V570 MINIMUM-VOLUME NO-SIGNAL POWER-UP - 2026-09-05:** the
documented `AUX`, tone `DEFEAT`, loudness-off, centred-balance, bank-B-only
state was reconfirmed. With every REW signal stopped, all UMC22 controls
unchanged, and the complete Gate E wiring retained, the SU-V570 was powered at
minimum volume for approximately one minute. The woofer produced no detectable
sound of any kind. Neither UMC22 channel showed a clip indication, and there
was no transient or persistent hum/buzz, instability, heating, smell, smoke, or
other abnormality.

**SU-V570 NO-SIGNAL DECISION - PASS:** this closes the staged powered no-signal
startup. The next bounded stage is the `1.00 V RMS` woofer-level and gross
reference-level check. The ECM8000 calibration file is not needed for these
two electrical-voltage observations, but it remains mandatory before any
reusable acoustic sweep.

1. Stop every REW signal, switch the SU-V570 off, retain its volume at minimum,
   and make no connection change until it is off. Secure a true-RMS meter in
   AC-voltage mode directly across the woofer terminals without disturbing the
   woofer, amplifier, or fixture wiring.
2. In REW, retain the exact `EXCL:` UMC22 input and output endpoints, `48 kHz`,
   and Java `Stereo only`. Prepare Generator for a `1 kHz` sine on output `L`
   at `-10 dBFS`, but keep Generator stopped.
3. With the amplifier off and Generator stopped, turn only UMC22 `OUTPUT`
   fully clockwise for a repeatable source setting. Retain `GAIN 1` and
   `GAIN 2` at minimum, `DIRECT MONITOR` off, phantom on, and all wiring
   unchanged.
4. Switch on the SU-V570 at minimum volume and confirm the established quiet
   no-signal state. Start Generator, then raise only SU-V570 volume slowly until
   the woofer meter reads `1.00 V RMS`; approximately `0.98-1.02 V RMS` is
   sufficient and avoids needless knob chasing. Stop Generator immediately.
   Stop earlier for any abrupt level jump, UMC22 clip indication, dropout,
   unexpected sound, instability, or other abnormality.
5. With Generator stopped, record the woofer voltage and approximate SU-V570
   volume position. Move the meter to breakout tip-to-ring in AC-voltage mode.
   Do not move any level control.
6. Restart the same tone briefly and confirm the protected reference is broadly
   `0.10 V RMS`; `0.080-0.120 V RMS` passes this gross range check. Stop
   immediately outside that range, for either UMC22 clip indication, a
   reference dropout, or any other abnormality. Stop Generator before moving
   the meter again.
7. Report the woofer voltage, breakout tip-to-ring voltage, approximate
   SU-V570 volume position, clip/dropout state, and any abnormality. Do not run
   Check Levels or Measure yet.

**VERIFIED CONTROLLED WOOFER LEVEL - 2026-09-05:** with the documented source,
amplifier, woofer, and fixture configuration restored, the Agilent U1282A read
`1.0000 V AC` across the woofer terminals with the SU-V570 volume control at
exactly the `-38 dB` mark on its scale. Generator was then stopped and the
system was silent. The scale mark is a reproducibility landmark, not a
calibrated voltage setting; the U1282A remains the authority when restoring the
test level. This passes the absolute woofer-voltage target. The gross protected-
reference voltage and clip/dropout observations remain to be recorded before
input-gain setting or any sweep.

**WOOFER-LEVEL DECISION - PASS:** do not move the UMC22 `OUTPUT` control or
SU-V570 volume. With Generator stopped, move the U1282A to breakout tip-to-ring
in AC-voltage mode and secure the leads. Briefly restart the unchanged `1 kHz`,
`-10 dBFS`, output-L tone. Confirm `0.080-0.120 V RMS`, then stop Generator.
Stop immediately for either UMC22 clip indication, a reference dropout,
instability, or any other abnormality. Report the stable reference voltage,
both clip indications, dropout/instability state, and any other observation.
Do not run Check Levels or Measure yet.

**VERIFIED GROSS PROTECTED-REFERENCE VOLTAGE - 2026-09-05:** with the unchanged
`1 kHz` tone and both level controls fixed, the Agilent U1282A in auto-ranging
AC-voltage mode measured a stable `98.53 mV AC` from breakout tip to ring. With
the woofer level established at `1.0000 V AC`, the measured transfer and
attenuation are:

```text
kmeasured = 0.09853 V / 1.0000 V = 0.09853

attenuation = 20 log10(0.09853) = -20.129 dB
```

Compared with the resistance-derived `0.09892` transfer, the result is only
`-0.39%` (`-0.034 dB`) lower. This is excellent agreement and comfortably
inside the gross `0.080-0.120 V RMS` pass band.

**REFERENCE-VOLTAGE DECISION - PASS FOR LEVEL:** stop Generator if it is still
running and do not change either level control. Before removing the breakout or
advancing to the final direct Input 2 connection, confirm whether either UMC22
clip indicator illuminated during the reference tone and whether there was any
dropout, instability, or other abnormality. None is inferred from the stable
voltage report alone. Do not run Check Levels or Measure yet.

**VERIFIED REFERENCE OBSERVATIONS - 2026-09-05:** Generator was stopped after
the voltage reading. Neither UMC22 clip indicator illuminated during the test,
and there was no dropout, instability, or other abnormality.

**GROSS PROTECTED-REFERENCE DECISION - PASS:** the measured level, agreement
with prediction, clipping margin, and stability all pass. Advance to the final
direct-reference connection without changing either level control:

1. Keep Generator, Check Levels, and Measure stopped. Switch the SU-V570 off
   while retaining its `-38 dB` volume-scale position, and wait for it to
   settle before touching any connection.
2. Remove the U1282A from the breakout. Remove the passed breakout cable from
   between the fixture output and UMC22 `INST 2`, then insert the fixture's TRS
   output plug directly into `INST 2`. Do not disturb the amplifier-terminal
   fixture leads, woofer cable, playback cable, or any level control.
3. If retaining the meter for the next level confirmation, secure it back
   across the woofer terminals in AC-voltage mode while the amplifier is off.
   Leave no exposed breakout contact or loose conductor in the powered setup.
4. Reconfirm UMC22 USB connected, phantom on, `GAIN 1` and `GAIN 2` at minimum,
   `OUTPUT` fully clockwise, and `DIRECT MONITOR` off. Keep every REW signal
   stopped.
5. Switch on the SU-V570 at the retained `-38 dB` position and observe for
   approximately `15 s`. Report whether the woofer remains silent, whether
   either UMC22 clip indicator illuminates, and whether there is any transient
   or persistent hum/buzz, dropout, instability, heating, smell, smoke, or
   other abnormality. Switch off immediately for anything concerning.

Do not generate a signal, change either level control, run Check Levels, or run
Measure until the direct-connection no-signal result is reviewed.

**VERIFIED FINAL DIRECT-REFERENCE NO-SIGNAL STATE - 2026-09-05:** the breakout
was removed, the fixture TRS output was connected directly to UMC22 `INST 2`,
the U1282A was secured back across the woofer, and the specified UMC22/SU-V570
configuration was confirmed. The SU-V570 was powered with every REW signal
stopped. The user reported no abnormalities.

**FINAL DIRECT-CONNECTION DECISION - PASS:** the intended measurement topology
now passes its powered no-signal observation. Retain all physical connections,
UMC22 `OUTPUT` fully clockwise, SU-V570 volume at its `-38 dB` scale mark, the
U1282A across the woofer, `GAIN 1` at minimum, phantom on, and `DIRECT MONITOR`
off. Set only the reference-input gain:

1. In REW, confirm both devices remain the exact `EXCL:` UMC22 endpoints at
   `48 kHz`, Java `Stereo only`, with measurement output L and reference input
   R. Open Level Meters; do not run Check Levels or Measure.
2. With `GAIN 2` at minimum, restart the unchanged output-L `1 kHz`, `-10 dBFS`
   tone. Confirm the U1282A remains within `0.98-1.02 V AC` at the woofer. Stop
   and report rather than adjusting either output level if it lies outside that
   range.
3. Raise only UMC22 `GAIN 2` until `Ref In` RMS is within approximately `-24`
   to `-18 dBFS`; do not chase an exact value. Retain at least `6 dB` peak
   headroom.
4. Stop immediately for a `Ref In` peak at or above `-6 dBFS`, either hardware
   clip indication, a woofer-voltage change outside the stated band, dropout,
   instability, or any other abnormality.
5. After approximately `10 s` of stable indication, stop Generator. Report
   `Ref In` RMS and peak, approximate `GAIN 2` position, U1282A woofer voltage,
   both clip indications, and any dropout or abnormality. Do not change
   `GAIN 1`, run Check Levels, or run Measure yet.

**VERIFIED FINAL REFERENCE-INPUT GAIN - 2026-09-05:** the exact `EXCL:` UMC22
endpoints, `48 kHz`, Java `Stereo only`, measurement output L, and reference
input R were confirmed. With the unchanged tone, the U1282A indicated a stable
`1.0003 V AC` across the woofer, only `+0.03%` (`+0.0026 dB`) above the
established target. Raising only `GAIN 2` to approximately 2 o'clock produced a
stable `Ref In` RMS indication of `-20.87 dBFS`, fluctuating by approximately
`+/-0.01 dB`. The user confirmed at least `6 dB` peak headroom, although no
numeric peak value was recorded. Neither channel clipped; voltages remained
stable; and there was no dropout or other anomaly. Generator was then stopped.

**REFERENCE-INPUT GAIN DECISION - PASS:** retain `GAIN 2` at approximately
2 o'clock, UMC22 `OUTPUT` fully clockwise, SU-V570 at its `-38 dB` scale mark,
`GAIN 1` at minimum, the U1282A across the woofer, all final direct-reference
wiring, and every signal stopped. Before setting microphone gain or capturing
any reusable response, identify the exact ECM8000 calibration filename/source
and whether it is intended for 0-degree or 90-degree incidence. That
identification is recorded in the next checkpoint. Do not run Check Levels or
Measure yet.

**PROVISIONAL GENERIC MICROPHONE CALIBRATION - 2026-09-05:** the supplied
`../calibration/ECM8000_calibration_data.csv` is identified as a generic
`0-degree` ECM8000 response. It contains `124` strictly ascending numeric rows
from `20` to `21999 Hz`, gain values from `-4.920` to `+1.015 dB`, and phase.
Its as-supplied SHA-256 was
`c64553a2ff0e2f2799bf1bd8a275ea649c3a1aae7ff2dd39fba1b572953b4d6d`.
REW documents comma-delimited calibration rows as requiring at least one space
after each comma. Spaces were therefore added after the commas without changing
any numeric value. The retained, directly REW-compatible CSV now has SHA-256
`bb8fba5b6ae58b5a84d4ba47807ca61d49cc291325a0c3b43fae7294407c5e23`.

This is not a serial-number-specific calibration and contains no microphone
sensitivity. It is acceptable as a clearly identified, provisional correction
for this hobby measurement series, but it does not establish unit-specific
magnitude/phase accuracy or calibrated absolute SPL. In particular, its
approximately `-4.92 dB` endpoint at `21999 Hz` would make REW apply a large
positive upper-treble correction, where unknown microphone-to-microphone
variation is most consequential. Preserve that limitation in exported FRD
provenance.

**VERIFIED REPORTED MICROPHONE/ROTATION GEOMETRY - 2026-09-05:** the microphone
tip is `1000 mm` from the baffle plane, its body is perpendicular to that plane
and aimed at the cabinet, and it is level with the centre of the woofer dome
and horizontally centred on the baffle. The loudspeaker is secured on a sturdy-
table jig that rotates it about the horizontal centre of the baffle plane and
is marked in 10-degree increments. The microphone incidence therefore matches
the generic `0-degree` calibration. Keep the microphone fixed for the later
off-axis series.

**CALIBRATION-LOAD NEXT STEP:** keep Generator and every REW measurement signal
stopped and retain all established hardware controls. In REW, enable separate
calibration by input if needed, load
`calibration/ECM8000_calibration_data.csv` for measurement input L only, and
leave electrical-reference input R without microphone calibration. Confirm the
filename and input assignment shown by REW and report any warning. Do not run
Check Levels or Measure until that assignment is reviewed.

**VERIFIED PRE-CONSOLIDATION CALIBRATION LOAD - PASS (2026-09-05):** REW showed
no warning while loading the derived calibration. Closing and reopening
Preferences showed that it persisted for the left channel only of the exact
`EXCL:` UMC22 microphone input; the right channel showed `None`. This verifies
the calibration parser and per-input assignment mechanism.

**CANONICAL-FILE DECISION - 2026-09-05:** at the user's request the compatible
format was folded into `../calibration/ECM8000_calibration_data.csv` and the
redundant `.cal` copy was deleted. Numeric calibration values are unchanged.
At that checkpoint REW's persisted entry named the removed file, so the retained
CSV had to be reselected on input L before setting `GAIN 1` or producing any
signal. The completed re-selection is recorded immediately below.

**VERIFIED CANONICAL CALIBRATION ASSIGNMENT - PASS (2026-09-05):** the retained
`../calibration/ECM8000_calibration_data.csv` was selected for the left channel
of the exact `EXCL:` UMC22 microphone input. Closing and reopening Preferences
showed that the new filename persisted; the right channel remained `None`.
The generic 0-degree microphone correction is therefore active only on the
acoustic measurement channel.

**MICROPHONE-GAIN CHECK LEVELS NEXT STEP:** this authorises only a bounded REW
Check Levels observation, not a measurement sweep:

1. Keep Generator stopped and retain every physical connection and control:
   UMC22 `OUTPUT` fully clockwise, `GAIN 2` approximately 2 o'clock, `GAIN 1`
   minimum, Direct Monitor off, phantom on, SU-V570 at its `-38 dB` scale mark,
   and the U1282A across the woofer.
2. In Measure, reconfirm Java `Stereo only`, exact `EXCL:` UMC22 input/output,
   `48 kHz`, measurement and reference outputs L, measurement input L,
   reference input R, `Use loopback as cal and timing reference`, `Make
   calibration data from loopback response`, and `Merge loopback response into
   IR` off. Confirm the retained CSV is shown for input L only.
3. Set the level to the established final `-10 dBFS`. Do not change the UMC22
   Output control or SU-V570 volume. Run `Check Levels`; while it is active,
   raise only `GAIN 1` slowly until main-input peaks are approximately `-18` to
   `-12 dBFS`. About `-15 dBFS` is a convenient centre, not a target to chase.
4. Retain at least `6 dB` main-input peak headroom. Stop immediately for an
   input peak at or above `-6 dBFS`, either hardware clip indication, dropout,
   unexpected rubbing/buzzing, instability, unusual heating, smell, or any
   other abnormality. The normal broadband Check Levels sound is not itself an
   abnormality.
5. After approximately `10 s` of stable levels, stop Check Levels. Report main
   `In` RMS and peak, `Ref In` RMS and peak, approximate `GAIN 1` position, both
   UMC22 clip indications, and any dropout or other abnormality. Do not alter a
   gain or run Measure afterward.

**VERIFIED MICROPHONE-GAIN CHECK LEVELS - PASS (2026-09-05):** with the
specified settings confirmed, raising only `GAIN 1` to approximately 4 o'clock
produced main `In` near `-15.5 dBFS`. `Ref In` was near `-33.8 dBFS`; both
indications varied by less than approximately `+/-1 dB`. Neither UMC22 clip
indicator illuminated, and there was no dropout or other anomaly.

The main level is comfortably within REW's documented acceptable `-30` to
`-12 dBFS` RMS range for an analogue microphone/preamp input. Do not raise
`GAIN 2` to match the Check Levels pink-noise indication: its direct coherent
`1 kHz` result is already `-20.87 dBFS`, REW defines loopback calibration level
at `1 kHz`, and no reference control has moved. The first sweep will directly
test whether actual reference headroom, timing detection, and calibration data
are valid.

**MICROPHONE-GAIN DECISION - PASS:** retain both gains and all output-level and
physical settings. One bounded acoustic checkout sweep is now approved:

1. Confirm the woofer is still the only connected drive unit and the room and
   `1000 mm` on-axis geometry are unchanged. Keep the U1282A connected but do
   not interpret its changing swept-signal display as a calibrated broadband
   RMS reading.
2. In Measure, use the exact `EXCL:` UMC22 endpoints, Java `Stereo only`,
   `48 kHz`, measurement/reference outputs L, measurement input L, reference
   input R, `Use loopback as cal and timing reference`, `Make calibration data
   from loopback response`, and `Merge loopback response into IR` off. Confirm
   the canonical ECM8000 CSV is active on input L only.
3. Set SPL sweep, `20-20000 Hz`, `-10 dBFS`, `256k`, one repetition, timing
   offset `0.0000 ms`, clipping abort enabled, and name
   `SB17 UMC22 acoustic checkout 1`.
4. Run exactly one measurement. Stop immediately for a hardware clip
   indication, REW clipping warning, severe rubbing/buzzing, dropout,
   instability, unusual heating, smell, or any other abnormality.
5. If it completes, do not run another sweep or alter any control. Report the
   main and reference headroom shown during measurement; numeric timing-
   reference index and System Delay; IR peak and IR start; output and reference-
   input channels; microphone and soundcard-calibration entries; whether the
   impulse has one clear dominant arrival; whether the magnitude curve is
   grossly woofer-like rather than almost flat; and any warning or abnormality.

**VERIFIED ACOUSTIC CHECKOUT ATTEMPTS - 2026-09-05:** the first run at
`-10 dBFS` raised a distortion warning and showed inadequate available
headroom. The user therefore repeated the same bounded checkout at `-20 dBFS`.
That suppressed the warning, but the Measure dialog still showed minimum
headroom occasionally approaching approximately `3.8 dB`; the screenshots do
not identify which channel supplied that minimum. Neither attempt produced a
hardware clip indication, dropout, or other abnormality.

The `-20 dBFS` Measurement Info and plots establish:

- REW `V5.40 beta 133`, `20-20000 Hz`, one `256k` log sweep, `48 kHz`;
- exact UMC22 measurement input L and output L, reference output L/input R;
- `Soundcard: Loopback cal`, timing-reference index `47850.03`, System Delay
  and IR peak `3.1243 ms`, IR start `3.0000 ms`, and clock adjustment `0.0 ppm`;
- SNR `43.8 dB` and signal-to-distortion `23.1 dB`;
- one clear dominant impulse arrival and a grossly woofer-like, non-flat
  magnitude response; and
- critically, `Mic: No cal file`.

**CALIBRATION-APPLICATION CORRECTION:** the previous canonical-file conclusion
is narrowed. It proved Preferences persistence on the left channel but not
application to the active source. The Cal files screenshot associates the CSV
with the exact device's `Default Input`, while Soundcard and Measurement Info
show the active source as `MICROPHONE (Master Volume), L`. The `-20 dBFS` run
therefore passes as routing, loopback-calibration, timing, and gross acoustic-
path evidence only. Neither run is reusable microphone-calibrated FRD.

**HEADROOM INFERENCE, NOW RESOLVED FOR THE NEXT CONTROL:** the screenshot did
not capture which channel supplied the approximately `3.8 dB` minimum, so that
number alone did not initially authorise a gain change. The independent
reference result does discriminate the channels: `Ref In` was `-20.87 dBFS` at
the higher `-10 dBFS` excitation, hence approximately `-30.87 dBFS` is expected
after reducing excitation to `-20 dBFS`. The electrical reference therefore
has far more than `3.8 dB` nominal margin and `GAIN 2` remains qualified. The
limiting path is consequently the microphone input. Reducing `GAIN 1` by
approximately `4 dB` should move the observed margin to approximately `7.8 dB`;
the next sweep must verify that prediction.

**COMPLETED NO-SIGNAL CALIBRATION CHECK:** keep Generator, Check Levels, and Measure
stopped and change no physical control. In Soundcard, confirm the selected
input is the exact `EXCL:` UMC22 device with `MICROPHONE (Master Volume)`, L.
In Cal files, locate the entry for that complete active input identity—not
`Default Input`—enable separate calibration per input, load
`calibration/ECM8000_calibration_data.csv` on L only, and leave R as `None`.
The active entry should be highlighted. Then use Measure's Cal files button to
confirm the microphone file is listed for the pending measurement. Report the
complete entry labels shown. Signal and gains remained unchanged while this
check was performed.

**VERIFIED CORRECTED ACTIVE-SOURCE PREFERENCES ASSOCIATION - PASS
(2026-09-05):** with all signals stopped, Soundcard shows input device
`EXCL: Behringer UMC22 (USB Audio CODEC)`, input selector
`MICROPHONE (Master Volume)`, and channel L. The ECM8000 CSV is now assigned to
that specific input on the left channel only, and the configuration persists
across Preferences close/reopen. This passes the Preferences half of the
correction. Signal remained held pending the measurement-level check below.

**VERIFIED PENDING-MEASUREMENT CALIBRATION APPLICATION - PASS (2026-09-05):**
Measure's `Calibration data` display identifies the exact UMC22
`MICROPHONE (Master Volume)` source and shows `ECM8000_calibration_data.csv`
under Mic calibration files for L. The pending Measure dialog explicitly uses
`MICROPHONE (Master Volume) L` as its input and
`MICROPHONE (Master Volume) R` as its timing-reference input. REW does not show
a separate microphone-calibration row for the timing-reference channel in this
view. The file is therefore confirmed for the pending measurement input, with
no displayed evidence of application to the electrical reference. The
soundcard-calibration row showing `None` before the sweep is expected because
the selected mode makes calibration data dynamically from the loopback
response rather than loading a stored soundcard file.

**NEXT CONTROLLED MICROPHONE-GAIN CORRECTION:** retain the `-20 dBFS` Measure
level, `GAIN 2`, UMC22 Output, SU-V570 volume, wiring, and physical geometry.
Run `Check Levels`, allow the main-input indication to settle, and record its
starting level. Reduce only `GAIN 1` until the main indication is approximately
`4 dB` below that starting level; do not chase better than about `+/-0.5 dB`.
Stop Check Levels and report the before/after main and reference indications,
approximate final `GAIN 1` position, and any warning or abnormality. A `4 dB`
input-gain reduction should turn the previously observed approximately
`3.8 dB` minimum sweep headroom into approximately `7.8 dB`. This is a
prediction, not a pass: one subsequent bounded `-20 dBFS` sweep must confirm
at least `6 dB` actual headroom and a Measurement Info mic-file entry.

**VERIFIED MICROPHONE-GAIN ADJUSTMENT - PASS (2026-09-05):** during
the authorised `-20 dBFS` Check Levels observation, main `In` moved from
approximately `-15.5 dBFS` to approximately `-19.3 dBFS` after reducing only
`GAIN 1`. The achieved reduction is therefore:

```text
-19.3 dBFS - (-15.5 dBFS) = -3.8 dB

predicted minimum sweep headroom = 3.8 dB + 3.8 dB = 7.6 dB
```

The knob moved only a few degrees and remains approximately at its 4 o'clock
position; the measured level change, not the coarse clock description, defines
the adjustment. The predicted `7.6 dB` exceeds the `6 dB` target but is not yet
a measured sweep result. `Ref In` was stable at `-33.58 dBFS` with only
`+/-0.01 dB` fluctuation. There was no warning, clipping, dropout, or other
abnormality. Retain `GAIN 1` at this new position. This closes the gain-
adjustment gate and authorises only the verification sweep below.

**NEXT CALIBRATED HEADROOM-VERIFICATION SWEEP:**

1. Retain the woofer-only connection, `1000 mm` on-axis geometry, U1282A,
   SU-V570 `-38 dB` setting, UMC22 Output, both input gains, and all wiring.
2. Confirm Java `Stereo only`, the exact `EXCL:` UMC22 endpoints, `48 kHz`,
   measurement/reference outputs L, measurement input L, reference input R,
   `Use loopback as cal and timing reference`, `Make calibration data from
   loopback response`, and `Merge loopback response into IR` off.
3. Confirm Measure's Calibration data still names
   `ECM8000_calibration_data.csv` for microphone input L. Use SPL sweep,
   `20-20000 Hz`, `-20 dBFS`, `256k`, one repetition, timing offset
   `0.0000 ms`, and clipping abort enabled. Name it
   `SB17 UMC22 calibrated headroom checkout 1`.
4. Run exactly one sweep. Watch the headroom indication and note the value
   closest to zero, retaining REW's displayed sign. Stop immediately for any
   clipping or distortion warning, hardware clip indication, severe rubbing or
   buzzing, dropout, instability, unusual heating, smell, or other abnormality.
5. After completion, do not alter any control or run another sweep. Report the
   closest-to-zero headroom value, every warning or abnormality, and the
   Measurement Info entries for `Mic`, `Soundcard`, timing-reference index,
   System Delay, output channel, timing-reference output/input, SNR, and signal
   to distortion. A screenshot of Measurement Info is sufficient.

**VERIFIED CALIBRATED HEADROOM-CHECKOUT EXECUTION - PARTIAL PASS / HEADROOM
FAIL (2026-09-05):** the user confirmed the ECM8000 file was still in place and
ran exactly one authorised sweep. It completed without warning or anomaly. The
captured Measure display shows `3.6 dB` main-input headroom in red and
`32.9 dB` reference headroom in green. The reference channel is therefore not
limiting; the microphone input remains below the required `6 dB` margin.

The predicted `7.6 dB` margin is superseded by this direct sweep observation.
The approximately `3.8 dB` change seen with broadband Check Levels did not
produce the predicted improvement at the sweep's narrow worst-case peak. That
does not by itself establish whether the discrepancy arose from stimulus
spectrum/statistics, level-reading variability, or control resolution. Do not
repeat Check Levels or another sweep merely to investigate it. Keep all signals
stopped and controls unchanged while the completed measurement's Info panel and
peak frequency are reviewed. The Info panel must still prove that the mic file
was stored with this measurement.

**VERIFIED CALIBRATED CHECKOUT METADATA AND PEAK - PASS FOR DIAGNOSIS
(2026-09-05):** Measurement Info confirms the requested name, exact UMC22
`MICROPHONE (Master Volume), L` source, one `256k` `20-20000 Hz` sweep at
`-20.0 dBFS`, `48 kHz`, `Mic: ECM8000_calibration_data.csv`, and
`Soundcard: Loopback cal`. It records timing-reference index `47849.89`, System
Delay and IR peak `3.1273 ms`, IR start `3.0000 ms`, timing-reference output L,
timing-reference input `MICROPHONE (Master Volume) R`, timing offset `0.0000 ms`,
and clock adjustment `0.0 ppm`. SNR is `44.4 dB` and signal-to-distortion is
`34.3 dB`. The user located the highest response peak at `6.07 kHz`.

This proves microphone-calibration application, routing, loopback calibration,
and timing for the checkout. It does not override the `3.6 dB` main-headroom
failure, so the response remains diagnostic rather than the retained FRD
baseline.

**NEXT TARGETED MICROPHONE-GAIN SETTING:** use the measured `6.07 kHz` peak to
set worst-case gain directly, without another broadband trial:

1. Keep every control, connection, and physical position unchanged initially.
   Keep any measurement sweep stopped.
2. Open REW Generator and select sine, `6070 Hz`, `-20 dBFS`, output L only.
   Open the Levels tool so main `In` RMS and peak and `Ref In` can be read.
3. Start the tone. Record the initial main-input peak, then reduce only
   `GAIN 1` slowly until the stable main-input peak is approximately
   `-9` to `-10 dBFS`. Do not chase better than approximately `+/-0.5 dB`.
4. Stop the tone as soon as the setting is stable, and in any case after no
   more than approximately `10 s` of continuous output. A pure high-frequency
   tone is expected. Stop immediately for a hardware clip indication,
   distortion or abnormal sound, dropout, instability, unusual heating, smell,
   or any other abnormality.
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

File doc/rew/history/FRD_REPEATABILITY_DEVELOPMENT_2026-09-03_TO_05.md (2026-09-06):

# FRD Repeatability Development - 2026-09-03 To 2026-09-05

Lifecycle: **HISTORY — AUDIT ONLY; DO NOT USE AS A CURRENT PROCEDURE**

This record preserves the development of the UMC202HD full-dual method, its
suspension after desktop source-stream dropouts, and the later UMC22 checkout
and repeatability narrative. It deliberately retains obsolete settings and
superseded instructions as dated evidence. They are not authorisation to power
equipment or generate a signal.

Use [`../FRD_MEASUREMENT_METHOD.md`](../FRD_MEASUREMENT_METHOD.md) for the
interface-neutral method, use
[`../procedures/UMC22_INSTALLED_WOOFER_FRD.md`](../procedures/UMC22_INSTALLED_WOOFER_FRD.md)
for current UMC22 work, and use
[`../procedures/UMC202HD_FRD_SUSPENDED.md`](../procedures/UMC202HD_FRD_SUSPENDED.md)
for the UMC202HD suspension/resumption boundary.

Date prepared: 2026-08-30

Last revised: 2026-09-05

Status: **UMC202HD PROCEDURE SUSPENDED BY DESKTOP DROPOUT; FIXTURE RELEASE
REMAINS VALID; UMC22 GATES A-D, ITS COMPLETE SWITCHED-OFF GATE E ASSEMBLY, AND
ITS USB/PHANTOM AND SU-V570 MINIMUM-VOLUME NO-SIGNAL OBSERVATIONS PASS; THE
CONTROLLED UMC22 WOOFER LEVEL PASSES AT `1.0000 V AC` WITH SU-V570 VOLUME AT
ITS `-38 dB` SCALE MARK; THE GROSS PROTECTED REFERENCE PASSES AT A STABLE
`98.53 mV AC` WITH NO CLIPPING, DROPOUT, INSTABILITY, OR OTHER ABNORMALITY;
FINAL DIRECT-REFERENCE RECONNECTION AND NO-SIGNAL OBSERVATION PASS; REFERENCE-
INPUT GAIN SETTING PASSES AT `-20.87 dBFS`; THE GENERIC `0-DEGREE` ECM8000 CSV
IS REW-COMPATIBLE AND NOW PERSISTS AGAINST THE EXACT ACTIVE `MICROPHONE (MASTER
VOLUME), L` SOURCE; `-10 dBFS` CHECKOUT FAILED DISTORTION/HEADROOM; `-20 dBFS`
REPEAT PASSES ROUTING/TIMING ONLY; MEASURE'S CAL-FILE DISPLAY NOW CONFIRMS THE
ECM8000 CSV FOR THE PENDING INPUT-L MEASUREMENT; `GAIN 1` HAS BEEN REDUCED BY
APPROXIMATELY `3.8 dB` WITH THE REFERENCE STABLE AND NO ABNORMALITY; ONE
CALIBRATED `-20 dBFS` VERIFICATION SWEEP COMPLETED CLEANLY BUT FAILED INPUT
HEADROOM AT `3.6 dB`; REFERENCE HEADROOM PASSES AT `32.9 dB`; POST-MEASUREMENT
METADATA PASSES AND THE PEAK IS `6.07 kHz`; ONE SHORT TARGETED
GAIN-SETTING TONE PASSES AT `-10.3 dBFS` MAIN PEAK WITH `GAIN 1` AT 2 O'CLOCK;
THE FINAL CALIBRATED CHECKOUT PASSES WITH `10.7 dB` MAIN AND `33 dB` REFERENCE
HEADROOM; REPEATABILITY RUNS 2 AND 3 ALSO STAYED GREEN WITH NO WARNING OR
ABNORMALITY; THREE-RUN DELAY SPREAD IS `1.0 us`; RAW SESSION SAVED; THE LONG-
WINDOW ROOM RESPONSE IS INAPPLICABLE TO THE HARDWARE GATE, WHILE A COMMON
DERIVED `2.0 ms` LEFT / `1.0 ms` RIGHT DIRECT WINDOW PASSES `1-5 kHz` AT
`0.0743 dB` MAXIMUM MAGNITUDE AND `1.931 degrees` MAXIMUM PHASE SPREAD; UMC22
GATE E AND THE CONTROLLED INSTALLED-WOOFER FRD ROUTE PASS**

Every electrical release prerequisite has passed: SU-V570 common-ground
topology, UMC202HD Input 2 phantom isolation, complete-fixture
resistance/DC/physical qualification, the unpowered ground audit, and rear-
output topology. The inspected UMC202HD rear outputs are mechanically TRS but
electrically tip plus a ring/sleeve common. The fixture's short unscreened tail
was included in the powered no-signal pass.

The proportionate safety/connectivity review in
[the consolidated fixture qualification](../qualification/REFERENCE_FIXTURE_QUALIFICATION_2026-09-01_TO_03.md)
passes, and the fixture authority says `Approved for amplifier use: YES` for
controlled UMC202HD bench work. That electrical release remains valid, but
UMC202HD measurement use is suspended by the separate dropout. This is not a
raw-tweeter or final polar-measurement procedure.

This procedure's base settings and release statements are UMC202HD-specific.
The risk-accepted UMC22 alternative has now passed the separate gates in
[the current UMC22 procedure](../procedures/UMC22_INSTALLED_WOOFER_FRD.md);
its qualified `48 kHz` configuration, contact mapping, calibration, gains, and
measured reference level supersede the corresponding UMC202HD details below
whenever that fallback is used.
Direct PCB inspection has established that both UMC22 rear outputs are likewise
two-node unbalanced sources: tip is signal and ring/sleeve share one copper
return. Its unpowered `INST 2` contact map has also passed: tip is isolated and
ring/sleeve/USB shell are common. Its Gate B phantom isolation also passes:
all on/off readings remained at or below approximately `0.0020 V DC` and
settled to zero. Gate C also measures `9125 ohm` from speaker positive to input
tip and `10127 ohm` to ring, sleeve, and USB shell, proving there is no primary-
resistor bypass. Its stable `0.290-0.311 ohm` complete returns then establish
the intended common bond and close Gate C. The fallback procedure remains
authoritative for the interface-specific low-voltage and powered gates. Its amplifier-
disconnected Gate D no-signal path started at `0.0015 V DC`, settled to zero,
and showed no clipping or abnormality. REW then enumerated Java exclusive-mode
UMC22 input/output with independent L/R channels at `48 kHz` and calibration
`None`. Measurement output/input L, reference input R, loopback calibration/
timing, IR merge, and zero offset are confirmed. The original no-excitation
setup also selected reference output R; that is superseded below. Unity input
scaling, the UMC22-specific measurement
name, and the `20-20000 Hz` first-checkout range are also confirmed. The
amplifier-disconnected `1 kHz` level check then passed at `0.0207 V RMS`, with
only `0.0205-0.0210 V RMS` slow movement and no clipping, dropout, or
abnormality. Live REW capture was initially held at the next step: with that
external tone present, `Ref In` remained near `-93.72 dBFS` throughout the full
`GAIN 2` range. The current screenshot also shows a non-`EXCL:` input endpoint despite the earlier
reported exclusive selection. Selecting the `EXCL:` input variant immediately
resolved the problem: `Ref In` then followed `GAIN 2` linearly and is set to a
stable `-20.88 dBFS` with `0.0218 V RMS` measured externally. Input 1's
microphone channel then responded normally to ambient sound, nearby speech, and
its gain control without clipping. The room-noise indications are contextual,
not an intrinsic interface-noise measurement. The controlled headphone-to-
microphone setup then produced `-19.5 dBFS` main and `-20.84 dBFS` reference at
a stable external `0.0230 V RMS`, with no clipping, dropout, or abnormality.
The first amplifier-disconnected `1M` sweep then completed without warning,
error, clipping, audible discontinuity, or abnormality and shows one dominant
impulse arrival. Its timing index is nevertheless `N/A` and System Delay is not
available: reference output R was selected while the fixture actually sensed
measurement output L. A second sweep with both output selections L also ran
without clipping or dropout at a confirmed `0.0222 V AC`, but its Info panel
stored the timing-reference input as L instead of R. Its nearly flat magnitude
and phase are the invalid result of self-referencing measurement Input 1/L,
and its timing index remains `N/A`. At that checkpoint one further amplifier-
disconnected repeat was required with output and reference output L, measurement input L, and
loopback/reference input R. Changing the Measure-window reference input to R
then raised `Index 1 out of bounds for length 1` in REW V5.40 beta 133. After a
restart, the exact `EXCL:` endpoints, `48 kHz`, L/L/L/R routing, loopback mode,
merge, zero offset, and sweep fields all pass visual audit. The fallback record
authorises one retry after enabling Java `Stereo only` to force a two-channel
capture; recurrence of the exception stops testing for a debug-file bug report.
That retry completed without the exception and its Info panel stored timing-
reference output L and input R, but its timing index remains `N/A` and System
Delay remains unavailable. Its `0.5100 ms` peak and `0.4792 ms` IR start are
physically plausible for the nominal `150 mm` headphone check, but are not by
themselves sufficient timing proof. The proposed retained-capture inspection has
been withdrawn: current REW Scope is a live two-channel oscilloscope and cannot
display the preceding measurement's raw captures. The subsequent amplifier-
disconnected `256k` timing-only sweep passed with timing-reference index
`47970.52`, System Delay `0.6141 ms`, IR start `0.5208 ms`, and no warning,
clipping, dropout, or exception. Gates A-D therefore qualify the UMC22 to enter
Gate E's documented staged checkout. The IR-merge
treatment remains excluded, and reusable FRD is held until the
ECM8000 calibration is loaded and the UMC22/electrical-reference magnitude-
calibration route is valid. The final unchanged `256k` check now qualifies
`Make calibration data from loopback response`: REW stored `Soundcard: Loopback
cal`, reference index `47975.52`, System Delay `0.5100 ms`, and no warning or
abnormality. Use that treatment for UMC22 Gate E, keep IR merging excluded, and
load the ECM8000 calibration before reusable acoustic capture.
UMC22 Output 1 uses the same already-mapped TS-to-RCA cable to
SU-V570 `AUX` left, so the isolated cable map need not be repeated.

## 1. Purpose And Pass Criteria

Use three repeated, unmoved woofer measurements to establish whether the
UMC202HD, ECM8000, Technics SU-V570, amplifier-output reference fixture, REW,
and room setup provide repeatable magnitude, phase, and timing around the
intended crossover region.

Pass criteria over `1-5 kHz`:

- magnitude spread no greater than approximately `0.2 dB`;
- system-delay spread preferably no greater than `5 us`;
- phase traces nearly coincident, with no unexplained jumps or drift; and
- no clipping or reference dropout.

Passing this test permits the same chain to be used for the first installed-
driver FRD measurements. Tweeter protection and sweep limits remain a separate
prerequisite.

## 2. Measurement Topology

### 2.1 Full-Dual Arrangement

| UMC202HD channel | Assignment |
| --- | --- |
| Input 1 / USB input L | ECM8000 microphone |
| Input 2 / USB input R | Protected SU-V570 amplifier-output reference |
| Output 1 / USB output L | SU-V570 and woofer under test |
| Output 2 / USB output R | Physically unconnected |

Use REW's `Use loopback as cal and timing reference` mode with
`Merge loopback response into IR` enabled. Input 2 then references the acoustic response to the
voltage at the selected SU-V570 rear speaker terminals and supplies common
timing.

The current fixture reference plane is the amplifier output, not the driver
terminals. The true-RMS meter still establishes `1.00 V RMS` at the woofer.
Keep the loudspeaker cable unchanged throughout the driver set and record any
later change of reference plane.

### 2.2 Safe Semi-Dual Fallback

If the complete fixture is not approved, do not connect either amplifier
terminal to the UMC202HD. Instead use:

```text
UMC202HD Output 2 -> straight-through TRS patch cable -> UMC202HD Input 2, LINE
```

Select `Use loopback as timing reference`. This preserves common timing but
leaves DAC and amplifier response in the acoustic measurement. Do not mix
semi-dual and full-dual data in a final driver set without first demonstrating
equivalent results. The cable retains separate TRS contacts because Input 2
ring is distinct, even though this interface's Output 2 ring and sleeve are
internally common.

## 3. Prerequisites And Equipment

### 3.1 Mandatory Release Gates

Before making the full-dual connection, confirm:

1. the SU-V570 record passes the unpowered common-ground topology gate;
2. the UMC202HD Input 2 central-TRS phantom-isolation gate passes;
3. the proportionate AC sanity/release gate in
   [the consolidated fixture qualification](../qualification/REFERENCE_FIXTURE_QUALIFICATION_2026-09-01_TO_03.md)
   passes; and
4. the fixture record explicitly says `Approved for amplifier use: YES`.

The fixture file owns its schematic, component values, wiring, and release
state; the qualification archive owns completed test evidence. This acoustic
procedure does not repeat either.

### 3.2 Required Equipment

- Behringer ECM8000 and XLR microphone cable;
- Behringer UMC202HD and USB cable;
- an interface driver/host path that has first passed the separate stability
  diagnosis; the former Behringer Windows driver is uninstalled and is not a
  current prerequisite;
- measured cable from UMC202HD Output 1 to the selected SU-V570 line input;
- fully commissioned SU-V570-to-UMC202HD reference fixture;
- Technics SU-V570;
- unchanged speaker cable from the selected SU-V570 output to the woofer;
- true-RMS voltmeter suitable at `1 kHz`;
- microphone stand, tape or laser measure, and cabinet support; and
- PC running REW.

Do not use the UMC202HD headphone output to drive a loudspeaker.

## 4. Suspended UMC202HD Checkout Configuration

The settings below preserve the exact configuration used for the completed
2026-09-03 checkout. They are not a current instruction to reinstall the
Behringer driver or resume UMC202HD sweeps. Re-establish this path only after
the stability issue in
[UMC202HD_DESKTOP_DROPOUT_DIAGNOSIS.md](../UMC202HD_DESKTOP_DROPOUT_DIAGNOSIS.md)
has been resolved and the selected driver/host combination has passed a
dropout-free control.

### 4.1 Interface Controls

1. Connect the UMC202HD directly to a reliable USB port and select its ASIO
   driver, not an old UMC22 endpoint or generic shared-mode device.
2. Select `24 bit`, `88.2 kHz` operation and confirm two independent inputs and
   outputs.
3. Prevent Windows and other applications from sending audio to the UMC202HD.
4. Clear any UMC22 or different-sample-rate soundcard calibration file.
5. Load the ECM8000 calibration file for the exact active device, input
   selector, and Input 1 channel. Confirm it in Measure's Cal files display and
   require the first Measurement Info panel to name it rather than `No cal
   file`; Preferences persistence against another selector is insufficient.
6. Set `DIRECT MONITOR` off, both pads off, both gains fully down, and `OUTPUT`
   fully down.
7. Set Input 2 to `LINE`. Its outer XLR contacts remain unused; the fixture uses
   only the central 1/4-inch TRS jack.
8. Connect the ECM8000 by XLR to Input 1 before enabling `+48 V`.

The `88.2 kHz` rate permits a nearly full-band `5 Hz-41 kHz` reference sweep.
It does not improve the low-frequency resolution of the short reflection-free
window.
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

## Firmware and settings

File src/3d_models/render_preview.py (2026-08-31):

#!/usr/bin/env python3
"""Render a QA preview for any generated model in ``src/3d_models``.

Each generator may expose a ``PREVIEW_CONFIG`` dictionary to customise its
camera views, title, material fallback, and canvas size. The rasterisation,
lighting, labels, output naming, and artifact-path handling stay here so new
models do not need their own copy of the rendering code.
"""

from __future__ import annotations

import argparse
import importlib.util
from pathlib import Path
import sys

import numpy as np
from PIL import Image, ImageDraw, ImageFont


SOURCE_ROOT = Path(__file__).resolve().parent
PROJECT_ROOT = SOURCE_ROOT.parents[1]
ARTIFACT_ROOT = PROJECT_ROOT / "3d_models"


def unit(vector):
    vector = np.asarray(vector, dtype=float)
    length = np.linalg.norm(vector)
    if length == 0.0:
        raise ValueError("Cannot normalise a zero-length vector")
    return vector / length


def load_generator(model_name):
    model_source = SOURCE_ROOT / model_name
    candidates = sorted(model_source.glob("generate_*.py"))
    if len(candidates) != 1:
        raise RuntimeError(
            f"Expected one generator under {model_source}, found {len(candidates)}"
        )
    generator_path = candidates[0]
    # Generator modules may share code with a sibling model source directory.
    sys.path.insert(0, str(SOURCE_ROOT))
    sys.path.insert(0, str(model_source))
    spec = importlib.util.spec_from_file_location(
        f"model_generator_{model_name}", generator_path
    )
    if spec is None or spec.loader is None:
        raise RuntimeError(f"Could not load {generator_path}")
    module = importlib.util.module_from_spec(spec)
    # Some standard-library features (notably ``dataclasses``) resolve type
    # metadata through ``sys.modules`` while a module is executing. Mirror the
    # normal import machinery instead of executing an unregistered module.
    sys.modules[spec.name] = module
    try:
        spec.loader.exec_module(module)
    except Exception:
        sys.modules.pop(spec.name, None)
        raise
    return module


def build_mesh(generator):
    for function_name in (
        "build_preview_mesh",
        "build_model",
        "build_low_poly_mesh",
        "build_mesh",
    ):
        function = getattr(generator, function_name, None)
        if callable(function):
            return function()
    raise RuntimeError("Generator exposes no recognised mesh-building function")


def face_colour(mesh, face_index, materials, base_colour, normal, light, view):
    if materials and hasattr(mesh, "materials"):
        definition = materials[mesh.materials[face_index]]
        base = np.array(definition["diffuse"][:3], dtype=float) * 255.0
        shininess = float(definition.get("shininess", 8.0))
    else:
        base = np.asarray(base_colour, dtype=float)
        shininess = 18.0
    diffuse = max(0.0, float(np.dot(normal, light)))
    half_vector = unit(light + view)
    specular = max(0.0, float(np.dot(normal, half_vector)))
    specular **= max(3.0, shininess * 0.55)
    return np.clip(
        base * (0.38 + 0.72 * diffuse) + 75.0 * specular,
        0,
        255,
    ).astype(np.uint8)


def render_view(mesh, direction, width, height, config, materials):
    vertices = np.asarray(mesh.vertices, dtype=float).copy()
    faces = np.asarray(mesh.faces, dtype=int)
    view = unit(direction)
    helper = np.array((0.0, 0.0, 1.0))
    if abs(np.dot(helper, view)) > 0.94:
        helper = np.array((0.0, 1.0, 0.0))
    right = unit(np.cross(helper, view))
    up = unit(np.cross(view, right))
    projected = np.column_stack((vertices @ right, vertices @ up, vertices @ view))

    margin = int(config.get("view_margin", 34))
    x_min, y_min = projected[:, :2].min(axis=0)
    x_max, y_max = projected[:, :2].max(axis=0)
    scale = min(
        (width - 2 * margin) / (x_max - x_min),
        (height - 2 * margin) / (y_max - y_min),
    )
    screen = np.empty_like(projected)
    screen[:, 0] = width / 2 + (projected[:, 0] - (x_min + x_max) / 2) * scale
    screen[:, 1] = height / 2 - (projected[:, 1] - (y_min + y_max) / 2) * scale
    screen[:, 2] = projected[:, 2]

    yy = np.linspace(0.0, 1.0, height)[:, None, None]
    top = np.array(config.get("background_top", (250, 251, 252)), dtype=float)
    bottom = np.array(config.get("background_bottom", (221, 228, 232)), dtype=float)
    pixels = np.repeat(
        top[None, None, :] * (1.0 - yy) + bottom[None, None, :] * yy,
        width,
        axis=1,
    ).astype(np.uint8)
    z_buffer = np.full((height, width), -np.inf, dtype=float)

    triangles = vertices[faces]
    raw_normals = np.cross(
        triangles[:, 1] - triangles[:, 0],
        triangles[:, 2] - triangles[:, 0],
    )
    lengths = np.linalg.norm(raw_normals, axis=1)
    if np.any(lengths == 0.0):
        raise RuntimeError("Preview mesh contains a degenerate triangle")
    normals = raw_normals / lengths[:, None]
    light_offset = unit(config.get("light_offset", (-0.35, -0.55, 1.15)))
    light = unit(view + light_offset)
    base_colour = config.get("base_colour", (170.0, 179.0, 184.0))

    for face_index in np.argsort(np.mean(screen[faces, 2], axis=1)):
        face = faces[face_index]
        face_normal = normals[face_index]
        if np.dot(face_normal, view) <= 0.0:
            continue
        triangle = screen[face]
        x0, y0, z0 = triangle[0]
        x1, y1, z1 = triangle[1]
        x2, y2, z2 = triangle[2]
        min_x = max(0, int(np.floor(min(x0, x1, x2))))
        max_x = min(width - 1, int(np.ceil(max(x0, x1, x2))))
        min_y = max(0, int(np.floor(min(y0, y1, y2))))
        max_y = min(height - 1, int(np.ceil(max(y0, y1, y2))))
        if min_x > max_x or min_y > max_y:
            continue
        denominator = (y1 - y2) * (x0 - x2) + (x2 - x1) * (y0 - y2)
        if abs(denominator) < 1e-10:
            continue
        xs = np.arange(min_x, max_x + 1, dtype=float) + 0.5
        ys = np.arange(min_y, max_y + 1, dtype=float) + 0.5
        xx, yy_grid = np.meshgrid(xs, ys)
        w0 = ((y1 - y2) * (xx - x2) + (x2 - x1) * (yy_grid - y2)) / denominator
        w1 = ((y2 - y0) * (xx - x2) + (x0 - x2) * (yy_grid - y2)) / denominator
        w2 = 1.0 - w0 - w1
        inside = (w0 >= -1e-8) & (w1 >= -1e-8) & (w2 >= -1e-8)
        if not inside.any():
            continue
        depth = w0 * z0 + w1 * z1 + w2 * z2
        old_depth = z_buffer[min_y:max_y + 1, min_x:max_x + 1]
        visible = inside & (depth > old_depth)
        if not visible.any():
            continue
        colour = face_colour(
            mesh,
            face_index,
            materials,
            base_colour,
            face_normal,
            light,
            view,
        )
        crop = pixels[min_y:max_y + 1, min_x:max_x + 1]
        crop[visible] = colour
        old_depth[visible] = depth[visible]

    return Image.fromarray(pixels, mode="RGB")


def render_preview(model_name):
    generator = load_generator(model_name)
    mesh = build_mesh(generator)
    materials = getattr(generator, "MATERIALS", None)
    config = dict(getattr(generator, "PREVIEW_CONFIG", {}))
    views = config.get(
        "views",
        (
            {"label": "Front three-quarter", "direction": (1.25, -1.55, 1.20)},
            {"label": "Rear three-quarter", "direction": (-1.25, -1.55, -1.05)},
        ),
    )
    view_width = int(config.get("view_width", 720))
    view_height = int(config.get("view_height", 650))
    header_height = int(config.get("header_height", 90))
    canvas = Image.new(
        "RGB",
        (view_width * len(views), view_height + header_height),
        config.get("canvas_colour", (244, 247, 249)),
    )
    draw = ImageDraw.Draw(canvas)
    title_font = ImageFont.load_default(size=int(config.get("title_size", 24)))
    label_font = ImageFont.load_default(size=int(config.get("label_size", 17)))
    title = config.get("title", model_name.replace("_", " "))
    draw.text((28, 22), title, fill=(38, 44, 48), font=title_font)

    for index, view_config in enumerate(views):
        image = render_view(
            mesh,
            view_config["direction"],
            view_width,
            view_height,
            config,
            materials,
        )
        x = index * view_width
        canvas.paste(image, (x, header_height))
        draw.text(
            (x + 28, 58),
            view_config.get("label", f"View {index + 1}"),
            fill=(78, 86, 91),
            font=label_font,
        )
        if index:
            draw.line(
                (x, header_height - 2, x, canvas.height - 20),
                fill=(185, 192, 196),
                width=1,
            )

    output_dir = ARTIFACT_ROOT / model_name
    output_dir.mkdir(parents=True, exist_ok=True)
    output = output_dir / config.get("output_name", f"{model_name}_preview.png")
    canvas.save(output, optimize=True)
    print(f"Wrote {output}: {canvas.width} x {canvas.height}")
    return output


def main():
    parser = argparse.ArgumentParser(
        description="Render the QA preview for a generated 3D model."
    )
    parser.add_argument(
        "model_name",
        help="Model folder name beneath src/3d_models and 3d_models.",
    )
    args = parser.parse_args()
    render_preview(args.model_name)


if __name__ == "__main__":
    main()

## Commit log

2026-08-31 Initial project import
    [Crossover coil bracket.stl, Crossover coil former small.stl, Crossover coil former.stl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]
2026-09-05 Qualify UMC22 FRD fallback calibration setup
    [ECM8000_calibration_data.csv]
2026-09-08 Add measured crossover baseline and Seed A prototype
    Retain the verified woofer and tweeter axial/polar evidence, document the measurement workflow and repeatability decisions, and reduce VituixCAD to the measured baseline and Seed A working project. R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
2026-09-09 Document Seed A prototype acoustic validation
2026-09-13 Added/rearranged crossover coil 3d models
    [Crossover coil bracket 70mm.stl, Crossover coil former 50mm.stl, Crossover coil former 60mm.stl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]
2026-09-15 Consolidate project documentation and Seed A evidence
    [Crossover coil bracket B.stl]
2026-09-15 Added four-pole crossover schematic and pcb
2026-09-16 renamed crossover schematic+pcb to add revision number
2026-09-16 added 55mm dia crossover coil former
2026-10-09 docs: consolidate current routes and catalogue retained sources
